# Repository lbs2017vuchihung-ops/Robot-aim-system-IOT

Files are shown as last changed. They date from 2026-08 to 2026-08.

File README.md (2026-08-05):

# Hệ Thống Phân Loại Màu Sắc Tự Động (IoT Robot Aim System)

> Một giải pháp tự động hóa toàn diện kết hợp phần cứng ESP32, vi điều khiển cơ khí 5 trục và nền tảng quản lý Web hiện đại (IoT).

Dự án được nghiên cứu và phát triển bởi nhóm hai sinh viên Đại học Bách Khoa TP.HCM. Hệ thống bao gồm một băng chuyền tự động và cánh tay robot 5 bậc tự do, có khả năng nhận diện, phân loại sản phẩm theo màu sắc và được giám sát theo thời gian thực qua giao diện Web Dashboard.

---
## Hình Ảnh Thực Tế Hệ Thống

<p align="center">
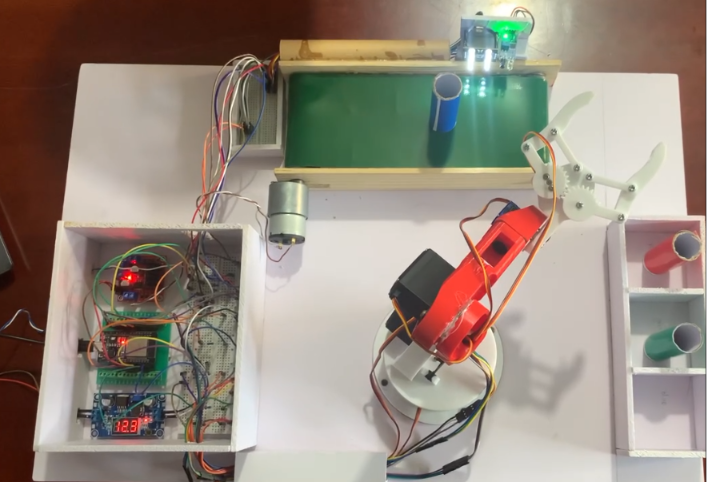
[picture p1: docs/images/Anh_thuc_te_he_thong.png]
Mô hình Robot Aim thực tế 1
  
</p>

---
## Tính Năng Nổi Bật

*   **Nhận Diện Chính Xác:** Sử dụng cảm biến màu TCS3200 với hộp che chống nhiễu sáng để thu thập thông số RGB của sản phẩm trên băng chuyền.
*   **Kết Cấu Cơ Khí Vững Chắc:** Băng tải sử dụng khung gỗ định hình dễ tháo lắp, dây đai PVC bám dính tốt và động cơ DC giảm tốc (12V) đảm bảo vận hành êm ái.
*   **Tay Máy Chịu Tải Cao:** Sử dụng 3 động cơ Servo MG996R (nhông kim loại, lực kéo 9-11 kg.cm) cho các khớp chịu lực (đế, vai, cùi chỏ) và 2 Servo SG90 siêu nhẹ cho tay kẹp để tối ưu trọng tâm.
*   **Hệ Thống Điện An Toàn:** Cấp nguồn 5V riêng biệt cho Servo qua mạch giảm áp LM2596. Tích hợp tụ điện chống tụt áp và điện trở giảm chấn bảo vệ chân tín hiệu của ESP32 khỏi tia lửa điện (Back EMF).
*   **Giao Diện Web Real-time:** Dashboard giám sát trực quan bằng Python, theo dõi tọa độ khớp gốc, số lượng sản phẩm màu và tình trạng đang chạy hay tắt của hệ thống.

---

## Sơ Đồ Đấu Dây (Pinout & Wiring)

### 1. Bảng Kết Nối ESP32 (Pin Mapping)
| Bảng chân (ESP32) | Thiết bị kết nối | Chức năng |
| :--- | :--- | :--- |
| **D5** | L298N (IN3) | Điều khiển Động cơ DC Băng tải |
| **D18** | L298N (IN4) | Điều khiển Động cơ DC Băng tải |
| **D13** | FC-51 | Cảm biến hồng ngoại nhận diện vật cuối băng tải |
| **D32, D14, D27, D26** | TCS3200 (S0, S1, S2, S3) | Cấu hình tần số cảm biến màu |
| **D25** | TCS3200 (OUT) | Tín hiệu xung màu sắc |
| **D4** | Servo MG996R (SV1) | Trục Đế (Xoay trái/phải) |
| **D19** | Servo MG996R (SV2) | Trục Vai (Nâng/hạ) |
| **D21** | Servo MG996R (SV3) | Trục Cùi chỏ (Vươn/rút) |
| **D22** | Servo SG90 (SV4) | Nâng hạ tay kẹp (Nâng/hạ) |
| **D23** | Servo SG90 (SV5) | Tay kẹp (Gripper) |

### 2. Nguyên Tắc Cấp Nguồn (Cực kỳ quan trọng)
*   **Tuyệt đối không** lấy nguồn 5V từ ESP32 để cấp cho Servo.
*   Nguồn 12V từ Adapter được chia làm 2 đường: 1 đường cấp cho L298N (kéo DC), 1 đường qua LM2596 hạ xuống đúng 5V để cấp cho Servo và ESP32.
*   Nối chung tất cả chân **GND** (Mass) của ESP32, LM2596, Servo và L298N để đồng bộ tín hiệu.
*   **Mạch bảo vệ:** Cắm tụ điện song song vào dải nguồn Servo và mắc điện trở nối tiếp trên các dây tín hiệu điều khiển.

### 3. Sơ đồ mạch trực quan

**Sơ đồ đấu nối hệ thống cảm biến & Servo:**
<p align="left">
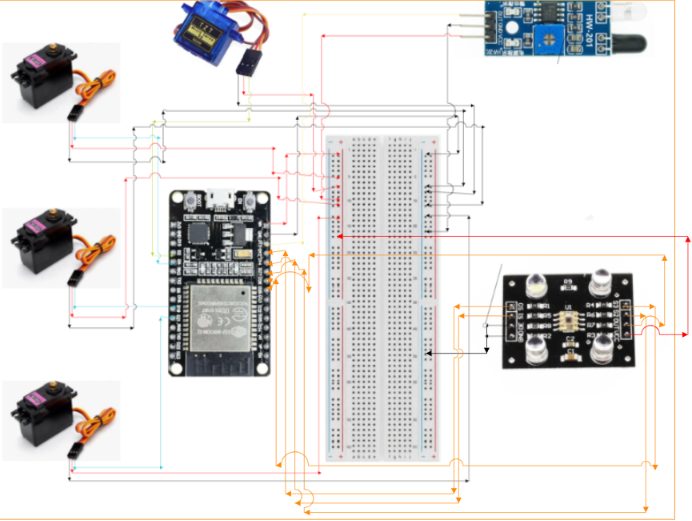
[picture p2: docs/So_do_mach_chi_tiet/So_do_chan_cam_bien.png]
Sơ đồ Cảm biến & Servo
  
</p>

**Sơ đồ đấu nối Động cơ DC & Hệ thống Nguồn:**
<p align="left">
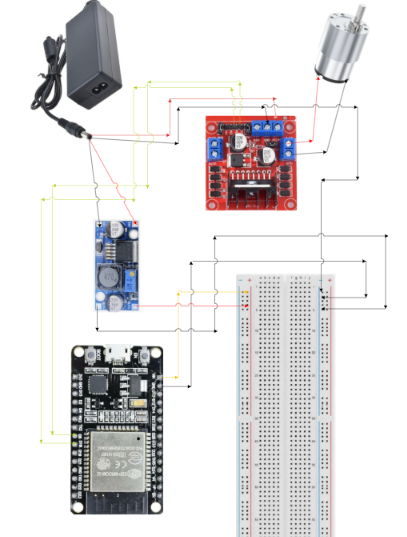
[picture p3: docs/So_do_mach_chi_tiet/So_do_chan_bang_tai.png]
Sơ đồ Băng tải & Nguồn
  
</p>

---

## Danh Sách Linh Kiện (BOM)

| STT | Tên Linh Kiện | Số Lượng |
| :--- | :--- | :--- |
| 1 | Vi điều khiển ESP32 NodeMCU 32S | 1 |
| 2 | Động cơ Servo MG996R (Nhông kim loại) | 3 |
| 3 | Động cơ Servo SG90 (Nhông nhựa) | 2 |
| 4 | Bộ băng tải mini (Khung gỗ định hình) | 1 |
| 5 | Động cơ DC giảm tốc 12V | 1 |
| 6 | Module điều khiển động cơ L298N | 1 |
| 7 | Cảm biến màu sắc TCS3200 | 1 |
| 8 | Cảm biến vật cản hồng ngoại FC-51 | 1 |
| 9 | Nguồn tổ ong / Adapter 12V-10A | 1 |
| 10 | Mạch giảm áp LM2596 (Step-down) | 1 |
| 11 | Điện trở, Tụ điện, Dây cắm Breadboard | Nhiều |

---

## Hướng Dẫn Cài Đặt & Khởi Chạy

### 1. Phần cứng (Firmware ESP32)
1. Tải và cài đặt Arduino IDE.
2. Mở file mã nguồn `.ino` trong thư mục `firmware`.
3. Cài đặt các thư viện cần thiết (ví dụ: `ESP32Servo`).
4. Kết nối board ESP32 với máy tính qua cáp Micro-USB và tiến hành Upload code.

### 2. Phần mềm (Web Dashboard)
Đảm bảo máy tính của bạn đã cài đặt Python. Hệ thống web sử dụng framework `NiceGUI` và `FastAPI` để render giao diện Real-time.

**Bước 1:** Di chuyển vào thư mục Web
```bash
cd web_app
```

**Bước 2:** Cài đặt các thư viện phụ thuộc
```bash
pip install -r requirements.txt
```

**Bước 3:** Khởi động máy chủ web
```bash
python RobotAim.py
```
*(Nếu muốn chạy ngầm máy chủ, hãy sử dụng lệnh pythonw RobotAim.py)*

**Bước 4:** Mở trình duyệt và truy cập vào địa chỉ `http://localhost:8080`.
Bạn có thể tự do bấm vào nút **Đăng ký** để tạo một tài khoản mới của riêng mình, hoặc sử dụng ngay tài khoản quản trị viên mặc định để trải nghiệm nhanh:
*   Username: `admin`
*   Password: `123456`

---
## Video Thuyết Trình & Hoạt Động

Dưới đây là các video thực tế ghi lại quá trình hoạt động của hệ thống mô hình:

* **Video Thuyết trình & Demo toàn bộ hệ thống:** [Bấm vào đây để xem](https://drive.google.com/file/d/19g9mdSmp5sloyk1nDQbA5UnhPswKEt9c/view?usp=sharing)

---

Dự án phát triển bởi: Vũ Chí Hưng & Đặng Hồng Anh - Đại học Bách Khoa TP.HCM

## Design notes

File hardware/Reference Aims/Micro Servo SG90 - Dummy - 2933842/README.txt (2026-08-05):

Micro Servo SG90 - Dummy by demetrius on Thingiverse: https://www.thingiverse.com/thing:2933842

Summary:
A simple micro servo dummy for help on your creation needs. One thing i had no idea about this servo (particularly the Tower Pro, not sure about others) is that its body is not perfectly square but is slightly tapered towards the top.

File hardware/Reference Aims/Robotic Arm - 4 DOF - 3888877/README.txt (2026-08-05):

Robotic Arm - 4 DOF by aled96 on Thingiverse: https://www.thingiverse.com/thing:3888877

Summary:
Robotic Arm - 4 DOF !Exclusive models and  contents only for you  on my PATREON page !!Visit now and support me at: https://www.patreon.com/aled96Support me if you like my work :)Motors used: SG90  https://www.amazon.it/gp/product/B01MXPTCHO/ref=ppx_yo_dt_b_asin_image_o02_s00?ie=UTF8&amp;psc=1Post ProcessingCreates the holes for the screws using a drill.Connect all together and make it works using an Arduino or another control board.

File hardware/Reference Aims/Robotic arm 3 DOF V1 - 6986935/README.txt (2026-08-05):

Robotic arm 3 DOF V1 by Vidimo_se on Thingiverse: https://www.thingiverse.com/thing:6986935

Summary:
The robot uses three 5V 28byj-48 stepper motors, one for each degree of freedom. The gripper is made for 20x20x20 XYZ calibration cubesThe SG90 is used for the two finger gripper. It's circuitry is removed so it's controlled as a DC motor, not a servo!I used the Arduino Pro Micro, though you can use other microcontrollers that have 14 or more digital I/O pins. Four are needed for each stepper motor if your using the ULN2003 drivers that come with the 28byj-48. The last two are for the DC motor on the end effector. I used the L293D driver IC, although it is a bit outdated. ~6 volt power source is required due to the voltage drop that occurs (1v on the ULN2003 and 1.5v-2.5v on the L293). I used a USB-C trigger (for fast charging) and a DC-DC step-down (buck) converter.Only one of each part needs to be printed.Non printed parts:28BYJ-48 stepper motor              x3SG90 modified to DC                       x1Main bearing - 6806                         x1Arm bearing - 693                             x2M3 nut                                                     x2M4 nut                                                    x2M4x6                                                       x6M3x12                                                     x6M3x8                                                       x5M3x25                                                    x2Screws                                                  x4Power supply                                      x1Breadboard                                         x1L293D motor driver                         x1Arduino microcontroller               x1ULN2003 driver board                   x3Edit 1: Posted pictures to help with assemblyEdit 2 (4.1.2025.):-Added a test print for tolerances with instructions (image)-Slight change to the "BASE"-Updated cover imageEdit 2 (15.3.2025.):-Added test code (Arduino IDE, requires AccelStepper library)-Added test code step-by-step explanation-Added pictures for the starting position the code uses Edit 3 (4.6.2025.):-Added "Beam 5 with counterweight", the counterweight helps with with the low torque of the stepper motorEdit 4 (9.8.2025.):-Fixed the test code to loop properlyEdit 5 (8.9.2025.):-Posted a video (.gif) of the test code, it's cut short due to file size limitations of the platform-Additional infoEdit 5 (9.9.2025.):-Fixed the "Base" model

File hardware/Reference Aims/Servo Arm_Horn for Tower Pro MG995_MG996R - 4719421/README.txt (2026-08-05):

Servo Arm/Horn for Tower Pro MG995/MG996R by Azxiana on Thingiverse: https://www.thingiverse.com/thing:4719421

Summary:
This is remixed to be close to the dimensions of the servo arm that ships with the authentic Tower Pro MG996R servos.  Unfortunately getting the authentic servos in my area is difficult so I am working with clones and need the correct servo arm for Alex Korvin's Walking UAZ robot.Print with 100% infill.  It only adds a few minutes and results in a much stronger part.I recommend using brim for bed adhesion since this is a small part.You might be able to get away without support for the screw recess.Print as shown with the flat side down.Blend file is included if you need to modify it outside of a STL format.

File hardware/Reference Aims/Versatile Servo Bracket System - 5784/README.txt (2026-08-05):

Versatile Servo Bracket System by bryanandaimee on Thingiverse: https://www.thingiverse.com/thing:5784

Summary:
This will hopefully be a versatile servo bracket system for robotics. I designed the holes to be spaced the same as the mounting holes on the servos and equidistant in both directions (square;)so brackets and/or servos should bolt together in many different configurations. The holes are a little closer to one of the long edges allowing a servo to be bolted on along that side directly. I don't know if that will ever be used, but I thought it might come in handy. It is sized for full size hobby servo motors. The files are in inches, so you may need to scale them in your system. They were created in google sketchup, so if you want other file formats I can only save to formats supported by sketchup. Pictures will follow soon. The servos I have are HS-322HD, so that is what I know it fits. Hopefully it will fit other full size servos. If you have a similar size servo that doesn't work with these brackets please let me know what changes are needed to make it more universal. I have a 2 DOF quad nearly finished using these brackets so pictures of that will be forthcoming as well. I'll soon be adding a connector to enable 3 DOF arms/legs. Update: Connectors added for 3 DOF limbs. Also I updated the brackets to be a little longer at the end. This will help prevent the ends splitting when screwing the bracket to the horn. The "Inside" brackets are a little narrower to be fitted inside the horn and the "outside" brackets are designed to attach outside the horn.Here is the 2DOF Quad http://www.thingiverse.com/thing:6321, and here http://www.youtube.com/watch?v=Z9ne67bbpSQ is a youtube video of the 2DOF walker in action. The controller is a Jaluino with a servo shield I designed myself.

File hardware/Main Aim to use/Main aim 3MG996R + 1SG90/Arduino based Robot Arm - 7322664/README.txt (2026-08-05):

Arduino based Robot Arm by FantaCitron on Thingiverse: https://www.thingiverse.com/thing:7322664

Summary:
An Arduino based simple 5 DOF robot arm controlled via a custom-built Android app. It utilizes three MG996R and two SG90 servo motors.https://howtomechatronics.com/tutorials/arduino/diy-arduino-robot-arm-with-smartphone-control

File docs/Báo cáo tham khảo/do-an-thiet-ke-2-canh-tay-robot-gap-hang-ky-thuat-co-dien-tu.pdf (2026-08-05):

DDDDDĐFFĐFDF44355 (https://www.studocu.vn/vn/document/truong-dai-hoc-thai-binh-duong/admistration/do-an-thiet-ke-2-canh-tay-robot-gap-hang-ky-thuat-co-dien-tu/162894056)

admistration (Trường Đại học Thái Bình Dương) (https://www.studocu.vn/vn/course/truong-dai-hoc-thai-binh-duong/admistration/5847769)

messages.pdf_cover_qr_code_label

messages.studocu_not_sponsored_or_endorsed_by_college messages.downloaded_by

lOMoARcPSD|60016464

TỔNG LIÊN ĐOÀN LAO ĐỘNG VIỆT NAM

TRƯỜNG ĐẠI HỌC TÔN ĐỨC THẮNG

KHOA ĐIỆN – ĐIỆN TỬ

TRẦN QUANG PHỔ

# THIẾT KẾ CÁNH TAY ROBOT GẮP HÀNG

## ĐỒ ÁN THIẾT KẾ 2

## KỸ THUẬT CƠ ĐIỆN TỬ

THÀNH PHỐ HỒ CHÍ MINH, NĂM 2025

TỔNG LIÊN ĐOÀN LAO ĐỘNG VIỆT NAM

TRƯỜNG ĐẠI HỌC TÔN ĐỨC THẮNG

KHOA ĐIỆN – ĐIỆN TỬ

TRẦN QUANG PHỔ

## THIẾT KẾ CÁNH TAY ROBOT GẮP HÀNG

## ĐỒ ÁN THIẾT KẾ 2

## KỸ THUẬT CƠ ĐIỆN TỬ

Người hướng dẫn

ThS.Thái Lâm Cường Quốc

THÀNH PHỐ HỒ CHÍ MINH, NĂM 2025

2

### LỜI CẢM ƠN

Đầu tiên cho em xin trân trọng gửi lời cảm ơn chân thành và sự kính trọng tới –

Các Thầy ngành Cơ điện tử Trường Đại học Tôn Đức Thắng, và đặc biệt là giảng viên

hướng dẫn thầy Thái Lâm Cường Quốc đã tận tình hướng dẫn chúng em trong suốt quá

trình thực hiện bài báo cáo này.

Do kiến thức của em còn hạn hẹp nên có thể sẽ mắc phải nhiều lỗi trong quá trình

em làm bài báo cáo. Em rất mong nhận được sự đóng góp ý kiến của quý thầy để bài báo

cáo đạt được kết quả tốt hơn.

Em xin chân thành cảm ơn!

TP. Hồ Chí Minh, ngày | tháng | năm 2025

Tác giả

3

4

MỤC LỤC

CHƯƠNG 1: TỔNG QUAN NGUYÊN LÝ HOẠT ĐỘNG CỦA TAY MÁY CÔNG

III

IV

DANH MỤC HÌNH VẼ

Hình 1-1. Cánh tay robot công nghiệp

Hình 1-2. Cánh tay robot kiểu khớp nối

Hình 1-3. Cánh tay robot SCARA

Hình 1-4. Cánh tay robot Cartesian

Hình 1-5. Cánh tay robot Delta

Hình 1-6. Cánh tay robot Polar

Hình 1-1. Cánh tay robot cộng tác

Hình 1-8. Quỷ đạo làm việc cánh tay robot

Hình 2-1. Các loại động cơ DC

Hình 2-2. Động cơ bước

Hình 2-3. Động cơ Servo

Hình 2-4. Động cơ AC

Hình 2-5. Driver A4988

Hình 2-6. Driver DRV8825

Hình 2-7. Driver TMC2208

Hình 2-8. Driver TB6600

Hình 2-9. ESP32

Hình 2-10. Arduino Uno R3

Hình 2-11. Arduino nano

Hình 2-12. Nguồn tổ ong

Hình 2-13. Nguồn adapter

Hình 2.14. Giác hút chân không L60-MP12

Hình 2-15. Động cơ bơm 12VDC

Hình 2-16. Ống silicon dẫn khí

Hình 2-17. Van xả 12VDC

V

Hình 3-0. Khioangr cách làm việc của cánh tay

Hình 3-1. Nắp đế động cơ 1

Hình 3-2. Đế khớp xoay động cơ 2 và 3

Hình 3-3. Đế khớp xoay động cơ 2 và 3 với giá đỡ công tắc hành trình

Hình 3-4. Khớp xoay bị động

Hình 3-5. cạnh khớp xoay bị động khi chạm vào công tắc hành trình

Hình 3-6. Cánh tay robot 4 bật tự do 2D

Hình 3-7. Động cơ bước NEMA17 −1,8 °−¿ 0,6 N.m

Hình 3-8. Động cơ bước NEMA17 −1,8 °−¿ 0,34 N.m

Hình 3-9. Góc quay arctan

Hình 3-10. Góc quay arctan 2

Hình 4-1. Đế khớp xoay và khâu 1

Hình 4-2. Đế khớp xoay và khâu 2

Hình 4-3. Đế khớp xoay và khâu 3

Hình 4-4. Khâu 4

Hình 4-5. Tay máy khi lắp ráp hoàn chỉnh và kiểm nghiệm bền

Hình 4-6. Sơ đồ điện của cánh tay robot

Hình 4-7. Lưu đồ giải thuật

Hình 5-1. Kết quả cánh tay và mạch trong quá trình nghiên cứu

VI

DANH MỤC BẢNG BIỂU

Bảng 2-1. Ưu và nhược điểm của từng loại động cơ

Bảng 2-2. Ưu và nhược điểm của từng loại Driver

Bảng 2-3. Ưu và nhược điểm của từng loại mạch vi điều khiển

Bảng 2-4. Các chí tiết phụ

Bảng 3-1. Các thông số kỹ thuật của vật liệu nhựa PETG

Bảng 3-2. Bảng số liệu khối lượng các khâu

Bảng 3-3. Các góc của tay máy

VII

DANH MỤC CÁC CHỮ VIẾT TẮT

CNC | Computer Numerical Control
DOF | Degrees of Freedom

VIII

ĐỒ ÁN THIÊT KẾ 2

Trang 1

CHƯƠNG 1: TỔNG QUAN NGUYÊN LÝ HOẠT ĐỘNG CỦA TAY MÁY

CÔNG NGHIỆP

### 1.1. Giới Thiệu đề Tài

### 1.1.1. Tổng quan về robot công nghiệp

- Cánh tay robot công nghiệp là một thiết bị cơ khí được thiết kế theo nguyên lý hoạt

động của tay người và có thể lập trình để thực hiện các chức năng cụ thể. Với thiết kế

tinh vi, chúng thường được sử dụng trong các dây chuyền sản xuất để đảm nhận nhiều

công việc khác nhau. Những cánh tay này nổi bật nhờ khả năng làm việc chính xác, hiệu

quả và đồng đều, giúp nâng cao năng suất và độ tin cậy trong quá trình sản xuất.

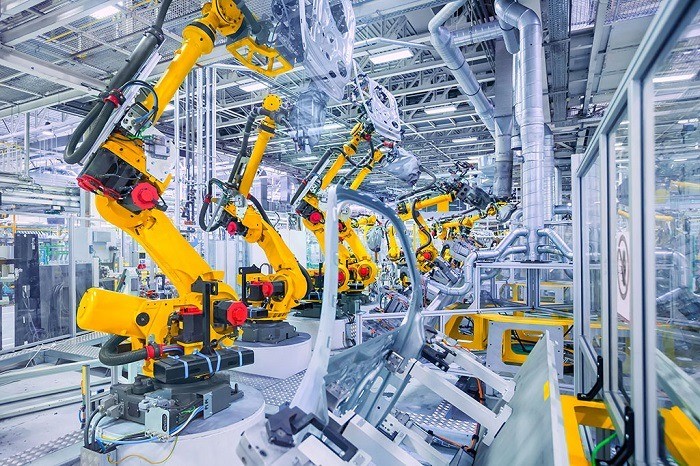
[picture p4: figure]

Thiết Kế Cánh Tay Robot Gắp Hàng (https://www.studocu.vn/vn)

Hình 1-2. Cánh tay robot công nghiệp

Trang 2

### 1.1.2. Các loại cánh tay công nghiệp phổ biến trong sắp xếp hàng hóa:

1. Cánh tay robot kiểu khớp nối (Articulated Robot Arm)
- Đặc điểm:

Có 3–6 bậc tự do (DOF), mỗi khớp nối thường dùng động cơ quay.

Giống cánh tay người.

Ví dụ: UR5, UR10 (Universal Robots), ABB IRB series, KUKA KR series.

- Ưu điểm:

Linh hoạt, hoạt động trong không gian 3D tốt

Có thể thực hiện nhiều thao tác phức tạp (lắp ráp, hàn, sơn...)

Có vùng làm việc lớn và dễ mở rộng

Thích hợp cho nhiều ứng dụng công nghiệp

- Nhược điểm:

+ Điều khiển và mô phỏng động học phức tạp

+ Giá thành cao

+ Khó bảo trì hơn các tay robot đơn giản

Hình 1-3. Cánh tay robot kiểu khớp nối

Trang 3

### 2. Cánh tay SCARA (Selective Compliance Articulated Robot Arm)

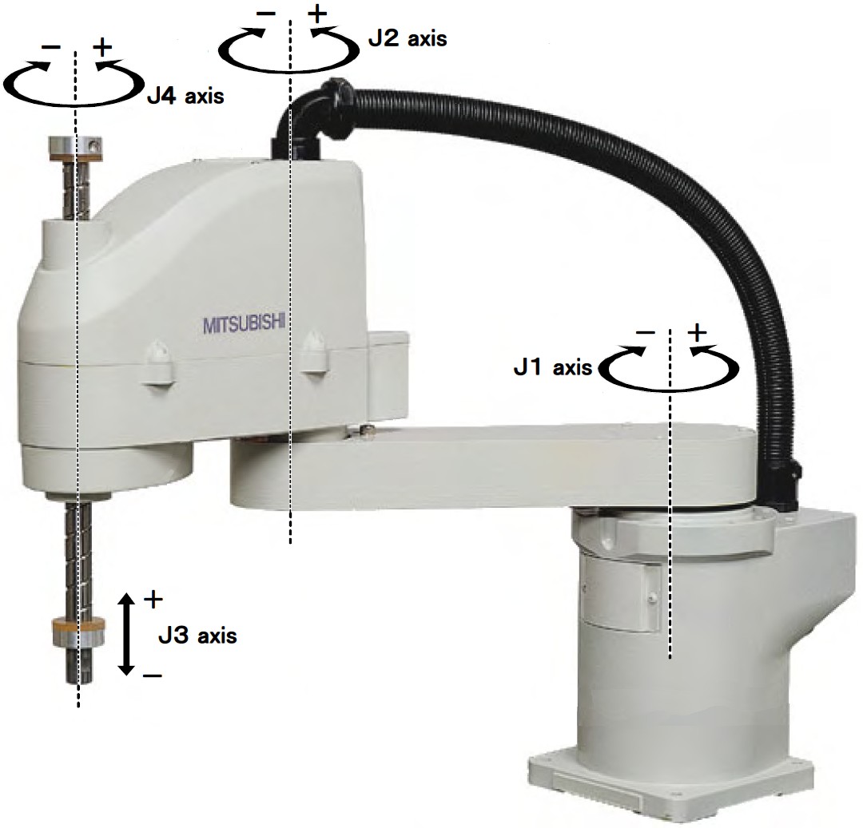
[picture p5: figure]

- Đặc điểm:

+ Chuyên dụng cho thao tác 2D trong mặt phẳng ngang, gồm 4 trục.

+ Phù hợp cho công việc pick-and-place, lắp ráp nhanh.

+ Ví dụ: Epson SCARA, Yamaha SCARA, Mitsubishi RH series.

- Ưu điểm:

+ Tốc độ rất nhanh

+ Độ chính xác cao

+ Thiết kế gọn gàng, dễ lắp đặt

- Nhược điểm:

Hình 1-4. Cánh tay robot SCARA

Trang 4

+ Chỉ làm việc trong mặt phẳng (ít linh hoạt hơn loại khớp nối)

+ Khó mở rộng phạm vi chuyển động không gian

### 3. Cánh tay Cartesian (Gantry Robot / XYZ robot)

- Đặc điểm:

+ Di chuyển dọc theo các trục X, Y, Z thẳng góc.

+ Hoạt động kiểu hệ tọa độ Descartes.

+ Ví dụ: Tay robot CNC, robot in 3D, pick-and-place công nghiệp.

- Ưu điểm:

+ Điều khiển đơn giản (chuyển động tuyến tính)

+ Độ chính xác cao

+ Tải trọng lớn

+ Dễ chế tạo, mở rộng

- Nhược điểm:

Hình 1-5. Cánh tay robot Cartesian

Trang 5

+ Không linh hoạt (chỉ chuyển động thẳng)

+ Chiếm nhiều không gian (khung lớn)

+ Không phù hợp với các công việc yêu cầu quay, cử động phức tạp

### 4. Cánh tay Delta (Parallel Robot)

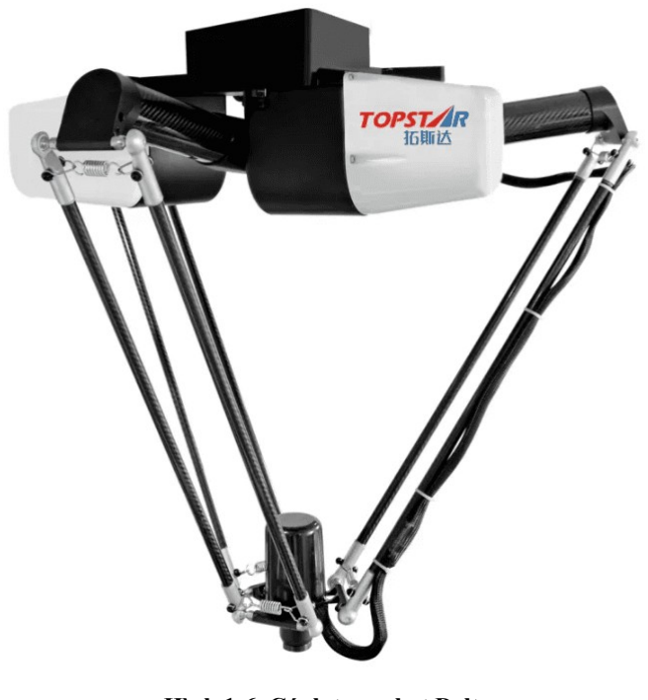
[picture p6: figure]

- Đặc điểm:

+ Gồm 3 hoặc 4 thanh tay song song liên kết với nhau

+ Di chuyển đầu công cụ rất nhanh và chính xác

+ Ví dụ: Tay robot pick-place tốc độ cao trong dây chuyền đóng gói.

- Ưu điểm:

+ Siêu nhanh (pick-and-place tốc độ cao)

+ Độ chính xác cao

+ Cấu trúc nhẹ

Hình 1-6. Cánh tay robot Delta

Trang 6

- Nhược điểm:

+ Không tải nặng được

+ Không linh hoạt trong không gian 3D

+ Điều khiển phức tạp do hệ song song

### 5. Cánh tay Polar / Spherical Robot

- Đặc điểm:

+ Tay robot có một khớp quay, một khớp gập, một khớp trượt

+ Vùng hoạt động dạng hình cầu

+ Ví dụ: Một số robot công nghiệp cũ trong sơn phủ, hàn.

Hình 1-7. Cánh tay robot Polar

Trang 7

- Ưu điểm:

+ Vùng làm việc hình cầu rộng

+ Cấu trúc đơn giản, tiết kiệm không gian

- Nhược điểm:

+ Độ chính xác không cao

+ Ít phổ biến hiện nay do hạn chế cơ học

### 6. Tay robot cộng tác (Collaborative Robot – Cobots)

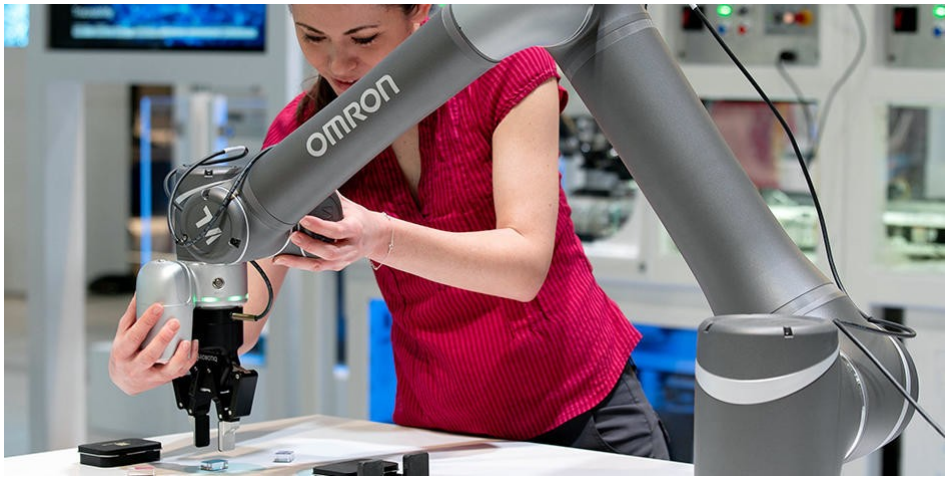
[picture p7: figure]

- Đặc điểm:

+ Có cảm biến, an toàn, làm việc cùng con người

+ Kiểu dáng thường là articulated hoặc SCARA

+ Ví dụ: UR series (Universal Robots), ABB YuMi, Doosan cobots.

- Ưu điểm:

+ An toàn khi làm việc cạnh người

+ Lập trình dễ (kéo thả, học lặp lại)

Hình 1-8. Cánh tay robot cộng tác

Trang 8

+ Linh hoạt, gọn nhẹ

- Nhược điểm:

+ Giá cao hơn so với công suất tương đương

+ Tốc độ/tải trọng thấp để đảm bảo an toàn

Vì yêu cầu đề tài là thiết kế cánh tay robot gắp hàng 4 bậc tự do nên em lựa chọn thiết kế

theo cánh tay kiểu khớp nối để có thể gắp hàng linh hoạt trong quỹ đạo của robot.

### 1.2. Mục đích nghiên cứu

- Với nhu cầu trong công nghiệp hiện nay có rất nhiều loại robot phục vụ cho từng mục

đích khác nhau nhưng vì đề tài của em hướng tới việc gắp hàng di chuyển từ vị trí A sang

B thì em đã lựa chọn thiết kế robot 4 bậc tự do, với mục tiêu xây dựng thành công mô

hình hoàn chỉnh, phục vụ cho nhu cầu nghiên cứu về lĩnh vực đang rất nổi trội trong thời

gian gần đây.

- Mục tiêu thiết kế cánh tay robot 4 bậc tự do để nhấc được vật ở khoảng cách tối đa của

cánh tay là 0,4 m nênd0=50mm; L1=¿ 250 mm; L2=300mm; L3=20mm

Hình 1-8. Quỷ đạo làm việc cánh tay robot

Trang 9

- Với phạm vi hoạt động này chắc chắn đáp ứng được các dự án cải tiến của em về sau

như thiết kế cánh tay robot đánh cờ tướng với AI, phân loại các khối hàng theo màu kết

hợp với băng tải,…

- Sử dụng giác hút chân không thay vì đầu gắp vì đề tài hướng tới là gắp hàng hóa nếu

thực tế sử dụng đầu gắp thì có khả năng gây hư hỏng thay vào đó sử dụng giác hút chân

không giúp tiết kiệm chi phí và khả năng di chuyển vật thể trong phạm vi hoạt động được

tốt nhất.

### 1.3. Đối tượng nghiên cứu

- Trong đồ án này, đối tượng nghiên cứu sẽ là một cánh tay robot ba bậc tự do với

khớp xoay thẳng đứng được gắn vào trục của một động cơ bước có driver. Khớp

xoay này sẽ được gắn vào trục của cánh tay đòn để giúp cánh tay đòn xoay đến vị

trí theo mong muốn của người lập trình.

- Vi điều khiển: ESP32
- Driver sử dụng để điều khiển động cơ bước là A4988 kết hợp với mạch ra chân

giúp cho việc lập trình và kết nối dây điện trở nên dễ dàng hơn

- Phần mềm điều khiển nạp code: Arduino IDE

### 1.4. Kết quả cần đạt được

- Do còn hạn chế về tài chính và kiến thức nên hiện tại chỉ có thể hoàn thiện được

một mô hình một bậc tự do có khả năng xoay lên xuống trong phạm vi góc từ 0°

đến 180° có thể được tùy chỉnh trong code tùy theo nhu cầu của người sử dụng.

- Cánh tay được điều khiển bởi phần cứng là một mạch Arduino ESP 32 kết nối với

một driver điều khiển động cơ bước là A4988.

- Đây là một hệ thống cơ cấu cánh tay máy đơn giản, gọn nhẹ và có thể chịu tải nhỏ

từ 300 g – 500 g tùy công suất động cơ mà người dùng lựa chọn.

- Sau khi thực hiện xong đồ án này, chúng ta có thể học được cách ứng dụng các

kiến thức về vi điều khiển, thiết kế 3D và lập trình một cách hiệu quả và cho ra

thành quả là một sản phẩm hoàn thiện ở một mức độ cơ bản, không quá chính xác.

Trang 10

- Ngoài ra, đồ án này là một nền móng quan trọng cho việc phát triển lên những sản

phẩm nâng cao hơn, yêu cầu sự chính xác như cánh tay robot 4 bậc, 5 bậc hay

thậm chí là 6 bậc tự do tùy theo nhu cầu trong tương lai.

### CHƯƠNG 2: LỰA CHỌN PHƯƠNG ÁN THIẾT KẾ

### 2.1. Tổng quan về các loại động cơ thông dụng:

- Hiện nay các dự án về cánh tay robot sử dụng rất nhiều các loại động cơ như:
- Động cơ DC (DC Motor) là một loại động cơ điện chạy bằng dòng điện một chiều (DC

– Direct Current). Nó hoạt động dựa trên nguyên lý lực từ tác động lên dây dẫn mang

dòng điện đặt trong từ trường, từ đó tạo ra chuyển động quay.

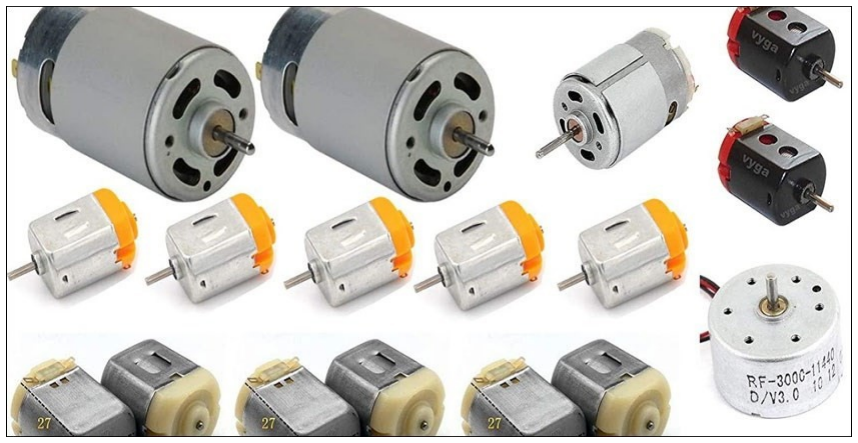
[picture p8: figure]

- Động cơ bước (Stepper Motor) là một loại động cơ điện quay từng bước góc xác định

thay vì quay liên tục như động cơ DC. Mỗi khi được cấp xung điện, rotor của nó sẽ quay

một góc nhất định (gọi là bước), giúp điều khiển vị trí chính xác mà không cần encoder.

Hình 2-1. Các loại động cơ DC

Trang 11

- Động cơ servo (Servo Motor) là một loại động cơ có khả năng điều khiển chính xác vị

trí, tốc độ và mô-men xoắn nhờ vào hệ thống phản hồi (feedback). Khác với động cơ DC

hoặc động cơ bước thông thường, servo motor luôn biết được nó đang ở đâu và phải di

chuyển như thế nào.

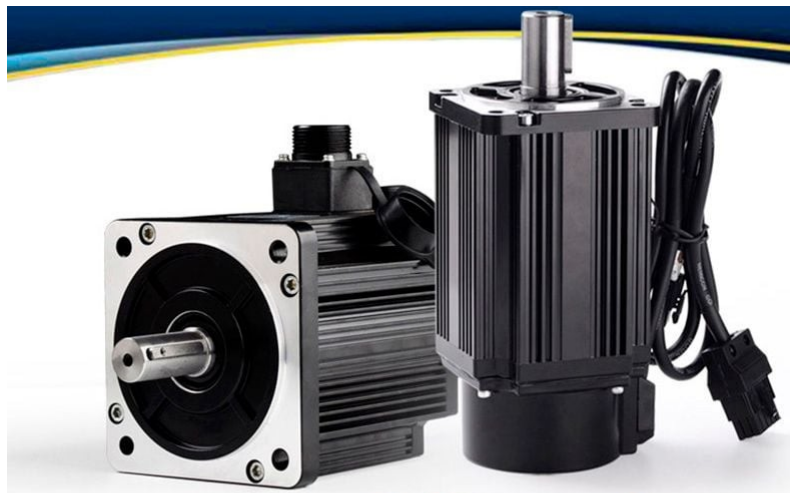
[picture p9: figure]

Hình 2-3. Động cơ Servo

Hình 2-2. Động cơ bước

Trang 12

- Động cơ AC (Alternating Current Motor) là loại động cơ điện sử dụng dòng điện xoay

chiều (AC) để tạo ra chuyển động quay. Đây là loại động cơ phổ biến nhất trong công

nghiệp và dân dụng nhờ vào cấu tạo đơn giản, độ bền cao và hiệu suất tốt.

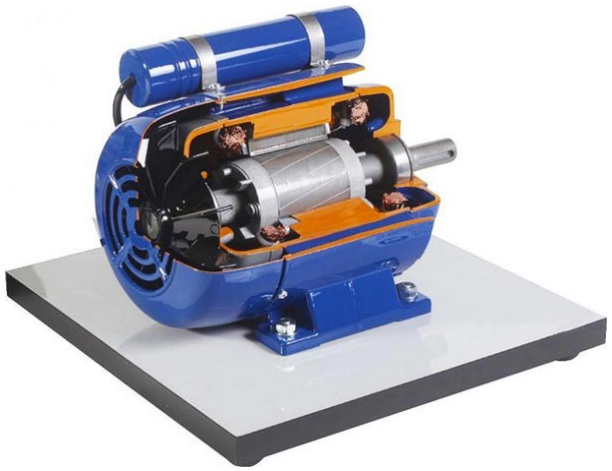
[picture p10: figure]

- Phân tích các ưu điểm và nhược điểm của từng động cơ:

Bảng 2-1. Ưu và nhược điểm của từng loại động cơ

Các loại động cơ | Ưu điểm | Nhược điểm | Ứng dụng
Động cơ DC | Điều khiển tốc độ đơn giản (bằng PWM). Khởi động nhanh, phản hồi tốt. Giá rẻ, phổ biến. | Chổi than nhanh mòn (với loại có chổi than). Gây nhiễu điện từ. Cần bảo trì định kỳ. | Xe robot mini, quạt, băng tải, máy bơm mini, đồ chơi…
Động cơ bước | Điều khiển vị trí chính xác mà không cần encoder. Cấu trúc đơn giản, giá thành rẻ. | Hiệu suất thấp, dễ bị mất bước nếu quá tải. Rung và ồn ở tốc độ cao | Máy in 3D, máy CNC mini, robot cánh tay đơn giản, máy khắc laser.

Hình 2-4. Động cơ AC

Trang 13

| Dễ tích hợp với mạch điều khiển (Arduino, CNC). Được sử dụng nhiều trong cánh tay robot
Động cơ Servo | Độ chính xác và mượt rất cao, không bị mất bước. Có thể kiểm soát vị trí, tốc độ, lực mô-men xoắn | Giá cao hơn nhiều so với stepper/DC. Điều khiển phức tạp hơn (cần driver chuyên dụng). Kích thước và trọng lượng đôi khi lớn | máy CNC chính xác cao, băng chuyền thông minh, camera gimbal, servo RC (loại nhỏ)
Động cơ AC | Bền, tin cậy, dễ bảo trì. Hoạt động ổn định trong công nghiệp | Cần biến tần (VFD) nếu muốn điều khiển tốc độ chính xác. Phản hồi chậm hơn so với servo. Kích thước lớn nếu công suất cao | Máy bơm, quạt công nghiệp, băng tải, hệ thống HVAC, máy nén khí.
- Kết luận: chọn động cơ bước làm động cơ chính trong các khâu của cánh tay robot vì

có những ưu và nhược điểm hợp với đồ án thiết kế 2 và có thể phát triển thêm cho các cải

tiến về sau.

### 2.2. Tổng quan về các loại Driver:

- Driver A4988 là một driver điều khiển động cơ bước (stepper motor driver) rất phổ

biến, do hãng Allegro Microsystems sản xuất. Nó được thiết kế để điều khiển các động

cơ bước lưỡng cực (bipolar stepper motors) thông qua tín hiệu số từ vi điều khiển (như

Arduino, ESP32, STM32...).

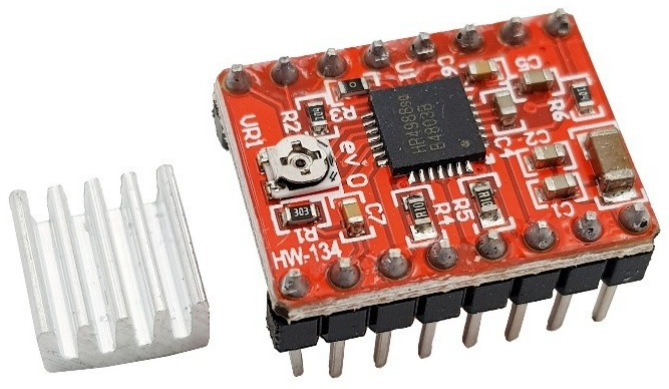
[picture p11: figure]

Hình 2-5. Driver A4988

Trang 14

- Driver DRV8825 là một driver điều khiển động cơ bước (stepper motor driver) được

sản xuất bởi Texas Instruments, thường được dùng như một bản nâng cấp của A4988. Nó

có khả năng điều khiển các động cơ bước lưỡng cực (bipolar stepper) với dòng cao hơn,

độ phân giải vi bước cao hơn, và hoạt động ổn định hơn.

- Driver TMC2208 là một driver điều khiển động cơ bước siêu êm và chính xác, do hãng

Trinamic (Đức) sản xuất. Nó nổi tiếng nhờ khả năng giảm tiếng ồn, vi bước mịn và điều

khiển dòng thông minh. Đây là bản nâng cấp cao cấp hơn so với A4988 hoặc DRV8825.-

Trang 15

Driver TB6600 là một loại driver điều khiển động cơ bước công suất cao, thường dùng để

điều khiển các động cơ bước lưỡng cực (bipolar) với dòng lớn, mô-men cao, rất phổ biến

trong máy CNC, máy cắt plasma, máy khắc laser, v.v.

- Phân tích các ưu nhược điểm của từng loại driver:

Bảng 2-2. Ưu và nhược điểm của từng loại Driver

Các loại Driver | Ưu điểm | Nhược điểm | Ứng dụng
A4988 | Rẻ, dễ tìm, nhỏ gọn. Hỗ trợ microstepping lên đến 1/16 bước. Có tính năng bảo vệ quá nhiệt, quá dòng. Dễ điều khiển bằng tín hiệu STEP/DIR (hợp với Arduino, STM32). | Dòng tối đa chỉ khoảng 1A – 2A, không phù hợp động cơ lớn. Không mượt ở tốc độ cao. Không có cách ly (isolation) tín hiệu điều khiển – dễ nhiễu. Không hỗ trợ điện áp cao (tối đa 35V). | Máy in 3D nhỏ, CNC mini, Cánh tay robot cỡ nhỏ..
DRV8825 (Texas Instruments) | Dòng tối đa cao hơn A4988 (khoảng 2.2A). Độ phân giải microstepping lên tới 1/32 bước → di chuyển mượt hơn. | Vẫn không đủ cho động cơ công suất lớn. Cần tản nhiệt tốt nếu chạy dòng cao. Gây nhiễu nếu không lọc nguồn tốt. | Máy in 3D, DIY CNC
TB6600 (Toshiba) | Tùy chỉnh được dòng điện, chế độ microstepping. Cách ly quang tín hiệu điều khiển → chống nhiễu tốt. | Kích thước lớn, không phù hợp không gian nhỏ. Giá cao hơn A4988, DRV8825. Tốc độ điều khiển không quá cao. | CNC bán chuyên, máy khắc laser
TMC2208 | Sử dụng công nghệ StealthChop2 giúp động cơ gần như không có tiếng ồn, phù hợp máy in 3D, robot chạy trong nhà. | Dòng tối đa ~1.4–1.5A ổn định, không đủ nếu dùng động cơ công nghiệp lớn. Đắt hơn A4988 hay DRV8825, tuy | Máy in 3D để in êm hơn, cánh tay robot giúp vận hành ổn định và ít rung lắc, …

Trang 16

Điều khiển cực kỳ mượt, chính xác

hơn hầu hết driver khác (A4988 chỉ

1/16, DRV8825 là 1/32).

nhiên xứng đáng với hiệu năng.

- Kết luận: em quyết định chọn Driver A4988, bởi vì nhìn vào ưu điểm thì driver có hiệu

năng tốt nhất trong các loại driver nêu trên và có thể ứng dụng được cho các cải tiến về

sau của đồ án.

### 2.3. Tổng quan về các loại mạch điều khiển

- ESP32 là một vi điều khiển tích hợp Wi-Fi và Bluetooth, được phát triển bởi công ty

Espressif Systems (Trung Quốc). Đây là một dòng chip mạnh mẽ, giá rẻ, rất phổ biến

trong các ứng dụng Internet of Things (IoT), tự động hóa, robot, thiết bị thông minh, và

nhiều dự án lập trình nhúng khác.

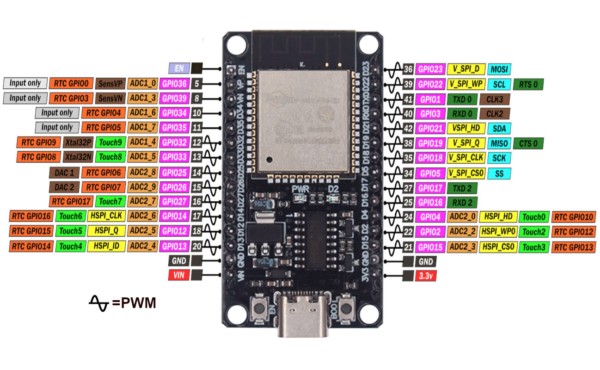
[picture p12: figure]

Hình 2-9. ESP32

Trang 17

- Arduino Uno R3 là một trong những bo mạch vi điều khiển phổ biến nhất của dòng

Arduino, rất phù hợp cho người mới học lập trình nhúng, các dự án DIY, robot, đo đạc

cảm biến, v.v. Nó được thiết kế để dễ dùng, lập trình bằng ngôn ngữ Arduino (dựa trên

C/C++), và kết nối với máy tính qua USB.

- Arduino nano là một bo mạch vi điều khiển nhỏ gọn, có cùng vi xử lý với Arduino Uno

(ATmega328P), nhưng kích thước nhỏ hơn rất nhiều, cực kỳ lý tưởng cho các dự án

nhúng, thiết bị wearable, robot mini, và không gian hạn chế.

Hình 2-10. Arduino Uno R3

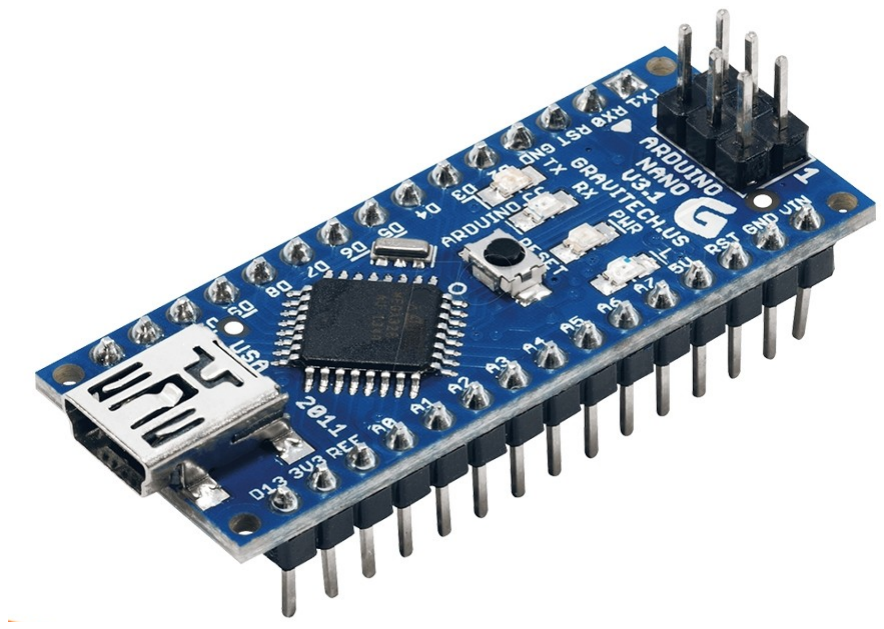
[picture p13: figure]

Hình 2.11 Arduino nano

Trang 18

- Phân tích ưu và nhược điểm của từng loại mạch vi điều khiển

Bảng 2-3. Ưu và nhược điểm của từng loại mạch

Tiêu chí | ESP32 | Arduino Uno R3 | Arduino Nano
Vi điều khiển chính | ESP32 (Xtensa 32-bit dual-core) | ATmega328P | ATmega328P
Xung nhịp (Clock) | 240 MHz | 16 MHz | 16 MHz
Bộ nhớ Flash | 4MB – 16MB | 32 KB | 32 KB
SRAM | ~520 KB | 2 KB | 2 KB
Số chân digital I/O | 30–38 chân | 14 (6 PWM) | 14 (6 PWM)
Số chân analog input | ~18 (tùy board) | 6 | 8
Chân analog output (DAC) | 2 DAC 8-bit | Không | Không
PWM output | Tùy chân (tối đa ~16) | 6 | 6
UART (Serial) | 3 (hoặc hơn) | 1 | 1
I2C | Có (2 hoặc nhiều hơn) | 1 | 1
SPI | Có (2 hoặc hơn) | 1 | 1
Wi-Fi | Tích hợp sẵn | Không | Không
Bluetooth | BLE + Classic | Không | Không
Logic level | 3.3V | 5V | 5V
Nguồn qua USB | 5V (microUSB hoặc USB-C) | 5V (USB-B) | 5V (mini-USB)
Kích thước | Nhỏ gọn | Trung bình | Rất nhỏ gọn
Giá (tham khảo) | 80k – 150k VND | 80k – 120k VND | 60k – 100k VND

Trang 19

Kết luận: Chọn ESP32 vì có những ưu điểm vượt trội hơn so với 2 mạch vi điều khiển

còn lại và đồng thời cũng phù hợp để cải tiến cánh tay robot trong tương lai.

### 2.4. Tổng quan về các loại nguồn

- Nguồn tổ ong (tiếng Anh: switching power supply with ventilation holes, hoặc thường

gọi là spider power supply / SMPS) là loại bộ nguồn chuyển mạch (Switching Mode

Power Supply - SMPS) được thiết kế với vỏ kim loại có nhiều lỗ thoáng khí giống như tổ

ong — giúp tản nhiệt hiệu quả.

- Nguồn adapter (còn gọi là adapter đổi nguồn, bộ đổi nguồn, hay adapter AC-DC) là

thiết bị chuyển đổi điện áp xoay chiều (AC) từ ổ cắm điện (thường 220V) thành điện áp

một chiều (DC) với mức thấp hơn (thường là 5V, 9V, 12V...), để cấp nguồn cho các thiết

bị điện tử như: laptop, camera, router, Arduino, ESP32, đèn LED, v.v.

Hình 2-12: Nguồn tổ ong

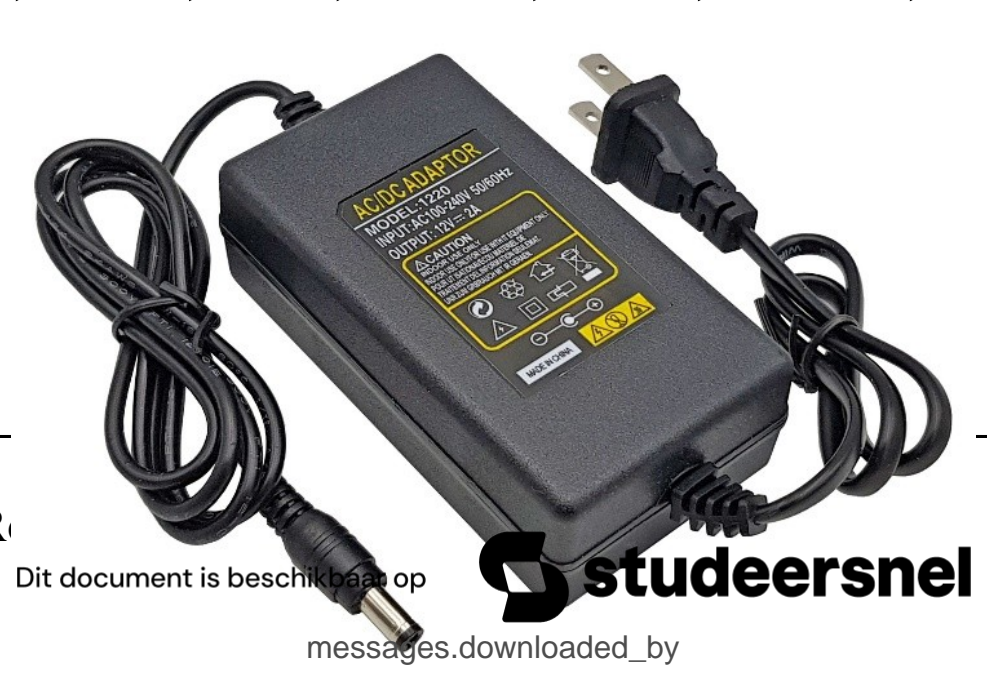
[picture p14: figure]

Trang 20

- Phân tích ưu và nhược điểm của 2 loại nguồn:
Tiêu chí | Nguồn tổ ong | Nguồn adapter
Cách đấu nối | Đấu dây thủ công qua terminal | Cắm trực tiếp qua jack (5.5mm, USB...)
Điện áp đầu vào | 220V AC trực tiếp | 220V AC (qua dây nguồn + jack tích hợp)
Điện áp đầu ra | 5V / 12V / 24V / 48V DC (ổn định) | 5V / 9V / 12V / 24V DC (có giới hạn dòng)
Dòng tối đa | Cao (3A – 40A tùy loại) | Thấp hơn (thường 0.5A – 5A)
Công suất | 50W – 1000W | 5W – 100W
Tản nhiệt | Tốt (vỏ tổ ong, đôi khi có quạt) | Kém hơn, dễ nóng nếu tải nặng
Tính ổn định | Rất ổn định, chịu tải cao | Có thể tụt áp nếu tải lớn đột ngột
Tính di động | Cồng kềnh, cố định | Nhỏ gọn, tiện mang theo
Độ an toàn (vỏ cách ly) | Cần che chắn khi dùng hở điện áp cao | Có vỏ bọc, an toàn với người dùng
Điều chỉnh điện áp | Có chiết áp chỉnh ±10% | Không chỉnh được điện áp
Giá bán | Rẻ / Trung bình | Rẻ / Trung bình
Ứng dụng phù hợp | Máy CNC, cánh tay robot, LED công nghiệp | Camera, mạch Arduino nhỏ, đồ gia dụng DIY
- Kết luận: Chọn nguồn tổ ong vì đồ án cần cấp nguồn cho nhiều thiết bị ngoại vi như

động cơ, driver, mạch điều khiển, sensor nên cần công suất lớn và sử dụng nguồn tổ ong

12V – 15A sẽ đáp ứng đủ các thiết bị cần cho đồ án.

Trang 21

2.5. Chọn động cơ bơm, van xả và giác hút cho tay gắp.

Sử dụng giác hút chân không L60 – MP12 .Ứng dụng nguyên lý gắp hút hình bình hành

để có thể hút và nhả vật, tiếp xúc tốt hơn với vật. Với việc sử dụng giác hút thì độ chính

xác và tiếp xúc với vật nhanh hơn.

- Ưu điểm :

+ Hoạt động chính xác.

+ Chi phí sản xuất thấp.

+ Kết cấu đơn giản.

+ Hệ thống điều khiển đơn giản.

- Nhược điểm:

+ Không hút được các vật có bề mặt tròn hoặc hình cầu

Hình 2-14: Giác hút chân không L60-MP12

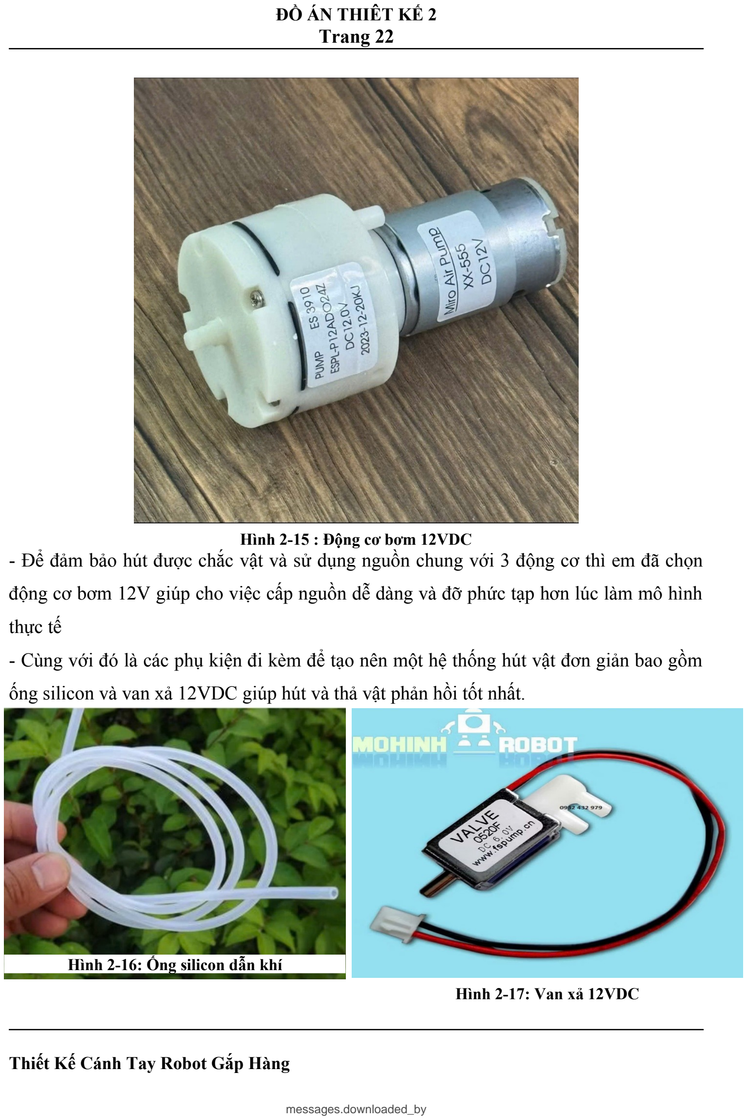
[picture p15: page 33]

Trang 22

- Để đảm bảo hút được chắc vật và sử dụng nguồn chung với 3 động cơ thì em đã chọn

động cơ bơm 12V giúp cho việc cấp nguồn dễ dàng và đỡ phức tạp hơn lúc làm mô hình

thực tế

- Cùng với đó là các phụ kiện đi kèm để tạo nên một hệ thống hút vật đơn giản bao gồm

ống silicon và van xả 12VDC giúp hút và thả vật phản hồi tốt nhất.

Hình 2-15 : Động cơ bơm 12VDC

Hình 2-16: Ống silicon dẫn khí

Hình 2-17: Van xả 12VDC

Trang 23

### 2.6. Danh sách các chi tiết phụ

Bảng 2-4. Các chí tiết phụ

STT | Tên chi tiết | Kích thước | Số lượng
1 | Bạc đạn F624 | | 10
2 | Bạc đạn F686 | | 12
3 | Vòng bi chặn F51105 | | 1
4 | Pulley GT2 | 20 răng | 3
5 | Dây đai GT2 | dày 6 mm - dài 200 mm | 3
6 | Bu lông M2 | 12 mm | 6 (đai ốc)
7 | Bu lông M3 | 6 mm | 8
| | 12 mm | 4
8 | Bu lông M4 | 10 mm | 6
| | 16 mm | 15 (đai ốc)
| | 20 mm | 4 (đai ốc)
9 | Bu lông M6 | 20 mm | 1 (đai ốc)
| | 40 mm | 1 (đai ốc)
| | 50 mm | 1 (đai ốc)
| | 60 mm | 1 (đai ốc)

TỔNG KẾT CÁC PHƯƠNG ÁN ĐÃ LỰA CHỌN

STT | 1 | 2 | 3 | 4 | 5 | 6 | 7 | 8
Tên linh kiện | Động cơ bước | Driver A4988 | Mạch ESP32 | Giác hút chân không L60-MP12 | Nguồn tổ ong 12V – 15A | Động cơ bơm 12 VDC | Van xả khí 12 VDC | Ống silicon dẫn khí

CHƯƠNG 3: TÍNH TOÁN ĐỘNG HỌC VÀ

KIỂM NGHIỆM BỀN

### 3.1. Lập bảng D-H cho cánh tay robot:

- Đặt các hệ tọa độ ta có được hình vẽ bên:

Trang 24

- Xác định bảng D-H:

Hàng 1:

# + Z0⊥Z1→a=0;α=90°

+ X0

# ∥ X1→d=50;θ=θ0

Hàng 2:

+ Z1

# ∥Z2→a=165 ;α=0°

+ X1 cùng mặt phẳng với X2→d=0 ;θ=θ1

Hàng 3:

+ Z2

# ∥Z3→a=200 ;α=0 °

+ X2 cùng mặt phẳng với X3→d=0 ;θ=θ2

Hàng 4:

+ Z3

# ∥Z4→a=50 ;α=0 °

+ X3 cùng mặt phẳng với X4→d=0;θ=θ3

- Xác định các góc θ0

;θ1

;θ2

;θ3 bằng phương pháp

động học thuận theo kiểu cổ điển (Classic DH parameter):

T=1T ×

0
2T ×

1
3T ×

2
4T

3
4
0 | T=

[

# Cθi −Cαi

# Sθi

# S αi

# S θi

# aiC θi

Sθi | CαiCθi | −S αiCθi

ai

| | | Sθi
0 | S αi | C αi | di
0 | 0 | 0 | 1 ] i

i−1

- Với {

# Cθ0=cos(θ0 ) ;Cθ1=cos(θ1) ;Cθ2=cos(θ2 );Cθ 3=cos(θ3) S θ0=sin (θ0 ) ; S θ1=sin (θ1 ); S θ2=sin (θ2) ;Sθ 1=sin (θ2)

- Sử dụng phần mềm Matlab để tính toán chính xác nhất
- Đặt biến bằng lệnh syms với a = a; α = a1; d = d; θ = th của ma trận iT i−1
:

Bảng 3-3. Các góc của tay máy

STT | a | α | d | θ
1 | 0 | 90 ° | d0 | θ0
2 | L1 | 0 ° | 0 | θ1
3 | L2 | 0 ° | 0 | θ2
4 | L3 | 0 ° | 0 | θ3

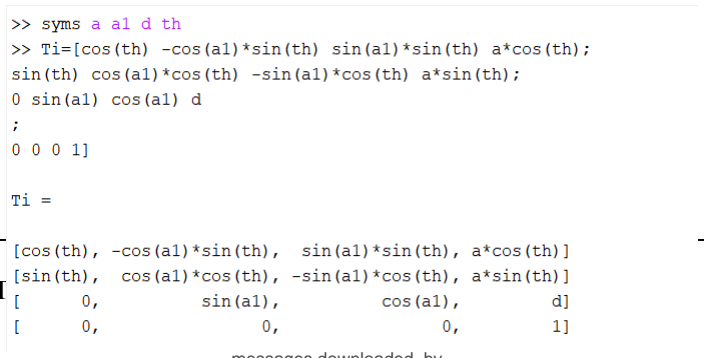
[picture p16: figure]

Trang 25

- Nhập giá trị của ma trận 1T

0
:

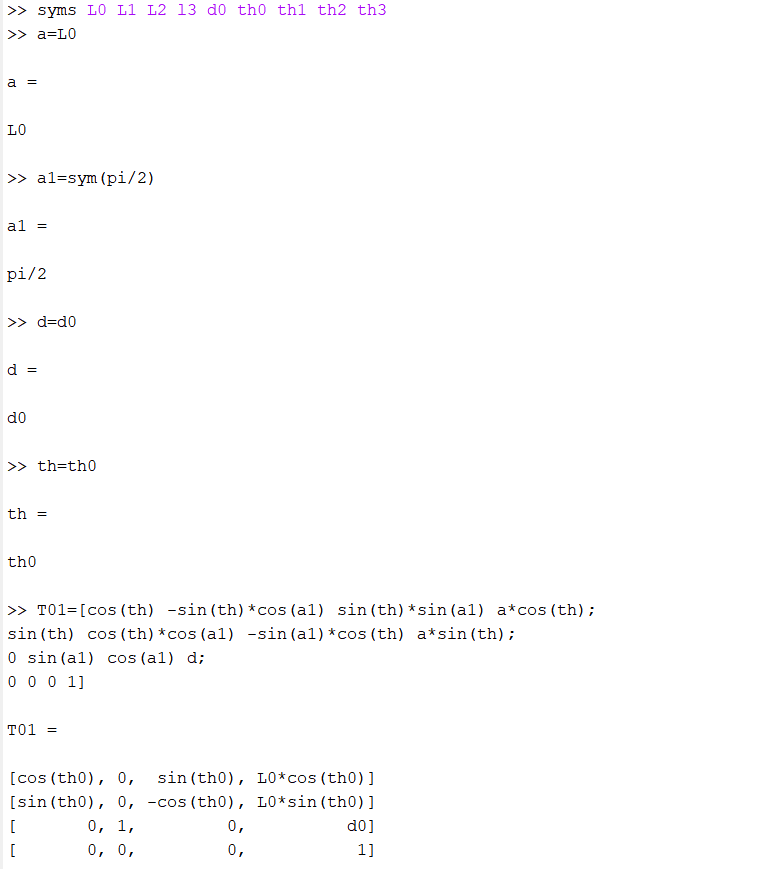
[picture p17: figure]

Trang 26

- Nhập giá trị của ma trận 2T

1
:
- Nhập giá trị của ma trận 3T

2
:

Trang 27

- Nhập giá tị của ma trận 4T

3
:

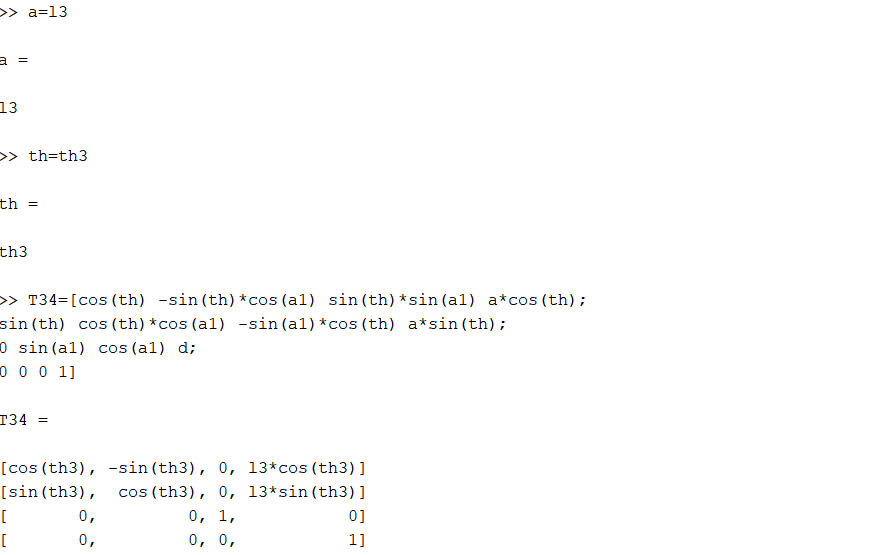
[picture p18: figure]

Từ đó ta có được các ma trận sau:

T=

[
C θ0

# 0 Sθ0 L0∗Cθ0

S θ0

0 −Cθ 0 | L0∗S θ 0
0 1 | 0 | d0
0 0 | 0 | 1 ] 1

0

; T=

[

# Cθ1 −S θ1

# 0 L1∗Cθ1

S θ1 | Cθ1 | 0 L1∗S θ1
0 | 0 | 1 | 0
0 | 0 | 0 | 1 ] 2

1

;

T=

[

# Cθ2 −S θ2 0 L2∗Cθ2

S θ 2 | Cθ2 | 0 L2∗Sθ2
0 | 0 | 1 | 0
0 | 0 | 0 | 1 ] 3

2

; T=

[

# Cθ3 −S θ3 0 L3∗Cθ3

S θ3 | Cθ 3 | 0 L3∗S θ3
0 | 0 | 1 | 0
0 | 0 | 0 | 1 ] 4

3

Tiếp tục tính toán ma trận T=1T ×

0
2T ×

1
3T ×

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
r11 r12 r13 | px
r21 r22 r23 | p y
r31 r32 r33 | pz

0 0 0 1 ] 4

0

Tính toán và rút gọn từ Matlab ta có được:

Trang 28
{

# px=cos(θ0

# )∗(L0⁺L2∗cos(θ1⁺θ 2

# )+L1∗cos(θ1

# )+ L3∗cos(θ1⁺θ2⁺θ3

))

# p y=sin(θ 0

# )∗(L0⁺L2∗cos(θ1⁺θ2

# )+L1∗cos(θ1

# )+L3∗cos(θ1⁺θ2⁺θ3

))

# pz=d0⁺L2∗sin(θ1⁺θ2

# )+L1∗sin(θ1

# )+ L3∗sin(θ1⁺θ2⁺θ3

)

(3.1.1)

Sử dụng phương pháp động học nghịch để tìm ra biểu thức cho các góc tại các khớp:
T=1T ×

0
2T ×

1
3T ×

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
T=2T ×

1
3T ×

2
4T

3
4

0

Dùng hàm inv để nghịch đảo ma trận 1T

0
:

Vì dữ liệu tính toán rất phức tạp nên em đặt :

T

−1
1 ×

0
T=

[
¿ | ¿ | ¿ | n1
¿ | ¿ | ¿ | n2
¿ | ¿ | ¿ | n3

0 0 0 1 ] 4

0

và 2T ×

1
3T ×

2
4T

3 =

[
¿ | ¿ | ¿ | m1
¿ | ¿ | ¿ | m2
¿ | ¿ | ¿ | m3

0 0 0 1 ]

Từ đó ta tính được:
{

# n1=px∗cos(θ0)−L0⁺ p y∗sin(θ 0

)

# n2=pz⁻d0 n3=px∗sin(θ0

# )−p y∗cos(θ0

)

(3.1.2)

và
{

# m1=L3∗cos(θ1⁺θ2⁺θ3

# )+L2∗cos(θ1⁺θ2

# )+L1∗cos(θ1

)

# m2=L3∗sin(θ1⁺θ 2⁺θ 3

# )+L2∗sin (θ1⁺θ2

# )+L1∗sin(θ 1

)
m3=0

(3.1.3)

Tính góc θ0:

# Mà n3=m3=¿ px∗sin (θ0 )−p y

# ∗cos( θ0 )=0

Trang 29

# sin (θ0 ) cos(θ0)

=

py
px

# =¿ tan( θ0 )=

py
px

# =¿ θ0=arctan 2( py

, px
) | (3.1.4)

Vì sao sử dụng arctan2 mà không sử dụng arctan như thông thường?

Arctan luôn đóng vai trò trong việc tính toán góc trong tam giác vuông nhưng sau đây sẽ

là chứng minh arctan đang gặp vấn đề trong vòng tròn lượng giác

# α=arctan (

y
x ) khi có điều kiện x > 0 thì mới tính được góc

Nhưng nếu x < 0 sẽ sinh ra 2 trường hợp như hình bên:

# góc α1=arctan (

y

# −x )=arctan (

−y
x )=α2

=> không xác định được chính xác khi góc nằm trong vùng II và IV

Giải pháp là sử dụng hàm arctan2 (y,x) vì có nhiều trường hợp

nên việc xác định các góc quay của cánh tay robot trở

nên chính xác hơn

# Arctan2 (y,x) = {

# arctan (

y
x )

# if x>0

# artan(

y
x )

# +π if x<0 ; y≥ 0

# artan(

y

# x )⁻π if x<0 ; y<0

π
2

# if x=0 ; y>0

−π
2

# if x=0; y<0 undefinded if x=y=0

(3.1.5)

Tính góc θ2:

Hình 3-9. Góc quay arctan

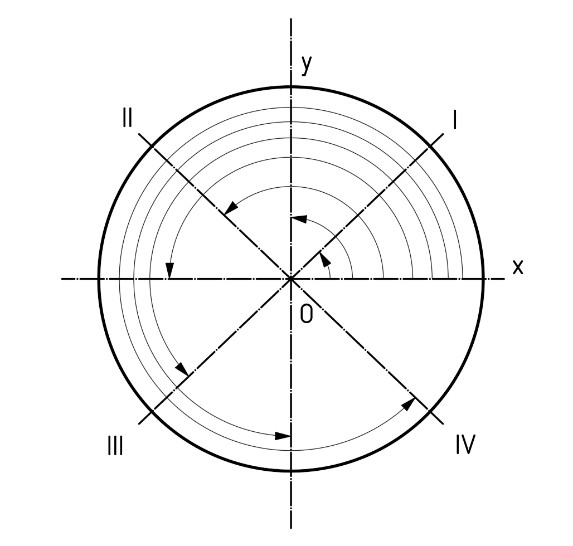
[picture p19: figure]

Hình 3-10. Góc quay arctan 2

Trang 30
{

n1=m1
n2=m2
{

# px∗cos(θ0)−d0⁺ py∗sin( θ0 )=L3∗cos(θ1⁺θ2⁺θ3

# )+ L2∗cos(θ1⁺θ2

# )+L1∗cos(θ1

)

# pz⁻d0=L3∗sin (θ1⁺θ2⁺θ3

# )+L2∗sin(θ 1⁺θ 2

# )+L1∗sin(θ1

)
{

# px∗cos(θ0 )−d0⁺ py∗sin( θ0 )−L3∗cos (θ1⁺θ2⁺θ3

# )=L2∗cos (θ1⁺θ2

# )+L1∗cos (θ1

)

# pz⁻d0⁻L3∗sin (θ1⁺θ2⁺θ3 )=L2∗sin( θ1⁺θ2)+L1∗sin (θ1)

Đặt {

# nx=L2∗cos(θ 1⁺θ 2 )+L1∗cos(θ1) ny=L2∗sin (θ1⁺θ2 )+L1∗sin (θ1)

=> ¿ | (3.1.6)

=> ¿

=> (n¿ ¿ x )

2
+(n¿¿ y )

2=L2

2∗(C12

2
+S12

2
)+L1
| 2∗(C1
| 2 +S1
| 2
)+2∗L1∗L2∗(C1∗C12⁺S1∗S12)¿ ¿

# Với {

# C1=cos(θ 1) C12=cos (θ1⁺θ2

)

# S1=sin (θ1

)

# S12=sin (θ1⁺θ2

)

(3.1.7)

=> (n¿ ¿ x )

2
+(n¿¿ y )

2=L2

2
+L1

2
+2∗L1∗L2∗(C1∗C12⁺S1∗S12 )¿ ¿

Rút gọn bằng Matlab: (C1∗C12⁺S1∗S12) = C2

=> (n¿ ¿ x )

2
+(n¿¿ y )

2=L2

2
+L1

2
+2∗L1∗L2∗C2 ¿ ¿ | (3.1.8)

=> C2=(n¿¿ x)

2
+

(n¿¿ y )

2
L2

2
+L1

2
+2∗L1∗L2

¿ ¿

(3.1.9)

Vì đường nét đứt ngang là đường cân bằng và cánh tay luôn chuyển động để hướng đầu hút ở

vị trí cân bằng nên θ1⁺θ2⁺θ3=0

Trang 31
{

# nx=px∗cos(θ0)−d0⁺ py∗sin( θ0 )−L3∗cos(θ1⁺θ2⁺θ3

)

# ny=pz⁻d0⁻L3∗sin (θ1⁺θ2⁺θ3

)
{

# nx=px∗cos(θ0 )−d0⁺ py∗sin( θ0)−L3 ny=pz⁻d0

Để tính được góc trong vòng tròn lượng giác thì ta phải biến đổi về hàm lượng giác tan từ

đó suy ra arctan2

Ta có: C2

2
+S2

2=1→S2=√1−C2
2

=> tan(θ2
¿=

# sin (θ2

)

# cos(θ2

)

# =¿θ2=arctan 2(S2

,C2
) | (3.1.10)

Tính góc θ1 :
{

# nx=L2∗cos(θ 1⁺θ2)+L1∗cos(θ 1 ) ny=L2∗sin (θ1⁺θ2)+L1∗sin (θ1 )

Sử dụng Matlab để khai triển cos(θ1⁺θ2 ) vàsin (θ1⁺θ 2):

¿

¿

¿

¿

¿

# Trường hợp 1: cos(θ 1 )

Trang 32

# => cos(θ1 )=¿ nx⁺ L2∗sin (θ2 )∗ny⁻L2∗cos ¿ ¿ ¿ ¿

# =nx∗(L2∗cos(θ2 )+L1)+L2∗sin (θ2)∗¿ ¿ ¿

=

# nx∗(L2∗cos(θ2 )+L1 )+L2∗sin (θ 2)∗n y⁻L2

# 2∗cos( θ1 )∗sin (θ2

)

2

¿ ¿ ¿

=

# nx∗(L2∗cos(θ2)+L1)+L2∗sin (θ2)∗n y

¿ ¿ ¿

# => cos(θ1 )∗¿ =>cos(θ 1 )∗¿

Rút gọn mẫu 2 vế:

# =>cos(θ1 )∗¿

# =>cos(θ1 )=

# nx∗( L2∗cos(θ2)+L1 )+L2∗sin( θ2 )∗ny

¿ ¿

(1) (3.1.11)

# Trường hợp 2: sin (θ1)

# => sin (θ1 )=ny⁻L2∗sin

# (θ2 )∗nx⁺L2∗sin (θ1)∗sin (θ2

)

¿ ¿

¿

=ny
∗¿ ¿

=n y
∗¿ ¿

=n y
∗¿ ¿

# => sin (θ1)∗

[
1+

L2

# 2∗sin (θ2)

2

# ( L2∗cos(θ2)+L1)

2 ]
=n y
∗¿ ¿

# => sin (θ1 )∗

[

# ( L2∗cos(θ2 )+L1)

2
+L2

# 2∗sin (θ 2)

2

# (L2∗cos(θ2 )+L1 )

2 | ]
=ny
∗¿¿

Rút gọn mẫu 2 vế:

Trang 33

# =>sin (θ1)∗¿ [( L2∗cos(θ2 )+L1)

2
+ L2

2

# ∗sin (θ2 )

2

]=ny
∗¿ ¿

# => sin (θ1 )=ny

∗¿ ¿ ¿ (2)

Từ (1) và (2) => tan(θ1
¿=

# sin (θ1

)

# cos(θ1

)

=ny
∗¿ ¿ | (3.1.12)

Đặt A = n y
∗¿ | (3.1.13)

# B = nx∗(L2∗cos(θ2 )+L1)+L2∗sin (θ2 )∗ny

Vậy θ1 = arctan2 (A,B)

Tính góc θ3:

Ta có: θ1⁺θ2⁺θ 3=0 | (3.1.14)

# => θ3=−θ1⁻θ2

ÁP DỤNG VÀO YÊU CẦU ĐỀ TÀI DI CHUYỀN VẬT VÀO Ô 2x2

Trang 34

- Sơ đồ về khoảng cách từ gốc cánh tay đến các 4 khối vuông 5x5x5cm như sau:

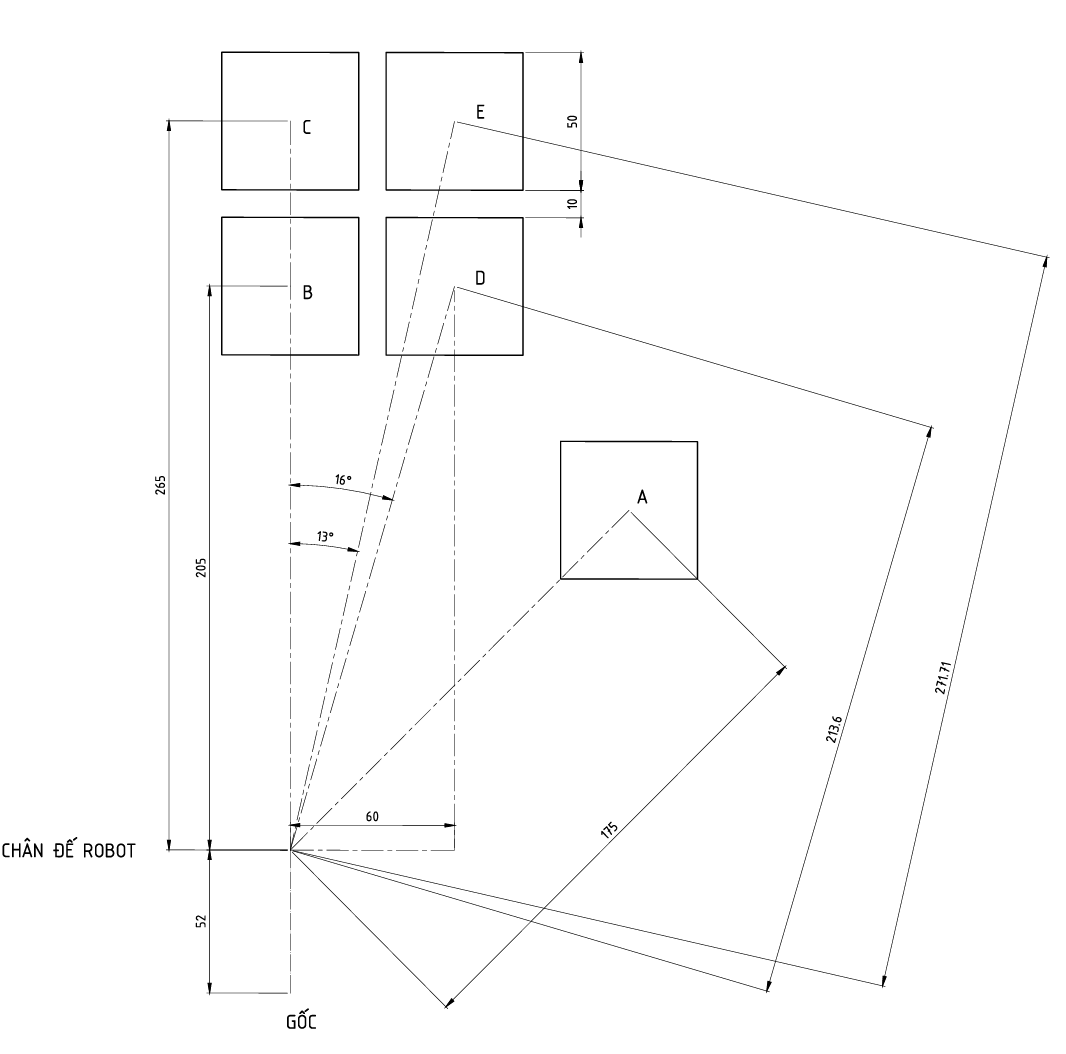
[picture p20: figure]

- Vật đặt tại vị trí A sẽ được nhấc và đưa vào lần lượt các vị trí B, C, D, E
a) Home

-Vì đây là vị trí ban đầu của cánh tay robot nên sẽ sử dụng công thức tính vi bước cho

động cơ để xác định các góc quay

Trang 35

- Trong thiết kế có thêm công tắc hành trình giúp cho cánh tay không hoạt động vượt quá

ngưỡng an toàn cho phép để tránh việc hư hỏng.

- Thực tế Driver điều khiển sẽ có sai số | 200 − | ¿

+¿ ¿
¿

bước nên khi sử dụng số liệu tính toán thì

phải ước lượng để đến được vị trí mong muốn trong lập trình.

- Động cơ NEMA17 có góc bước gốc là 1,8°/bước và sử dụng driver A4988 để điều

khiển 1/16 bước nên ta có công thức như sau:

θvi bước=

1,8°
16

=0,1125 °

- Đặt {
θ0=0°
θ1=90°
θ2=0°
θ3=−(−90 °)−0°=90°
- Vì θ3 là khớp xoay bị động do thiết kế nên không cần tính vi bước của động cơ

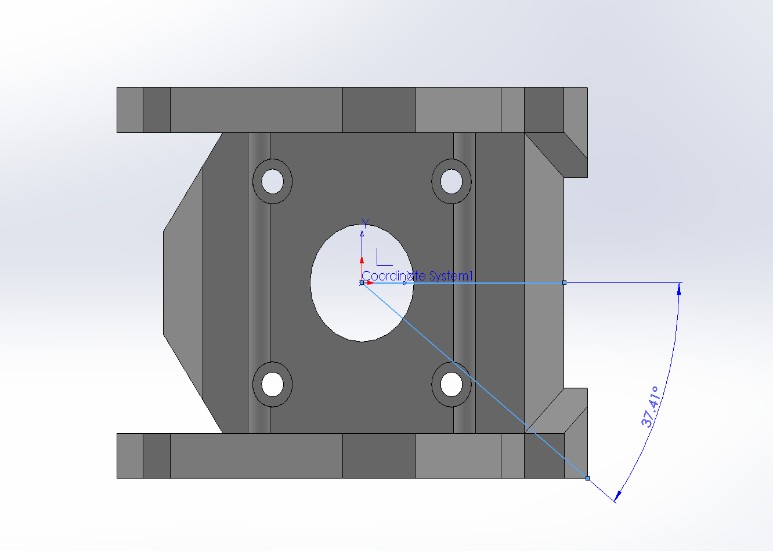
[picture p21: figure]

- Cánh tay robot có 3 công tắc hành trình và được bố trí như sau:

+ Khớp xoay 1 bao gồm có nắp động cơ 1 và đế động cơ 2 3 khi xoay cùng chiều kim

đồng hồ chạm vào công tắc hành trình thì sẽ quay ngược lại với số bước bằng với các góc

như trong hình vẽ như sau:

khi đế khớp xoay 2 và 3 chạm vào công tắc ở nắp đế động cơ 1 thì phải cần thực hiện

Hình 3.2: Nắp đế động cơ 1 | Hình 3.2: Đế khớp xoay động cơ 2 và 3

Trang 36

phép tính góc như sau:
44,29 °−37,41°=6,88 °

Để trung điểm khớp xoay 2 và 3 luôn nằm đúng tại góc 0 độ

- Tính số vi bước cần để xoay ngược lại khi chạm công tắc hành trình để θ0=0°:

Số bước¿

6,88°
0,1125°

=¿ 65 bước

- Công tắc hành trình ở khớp 2 được bố trí như hình sau:

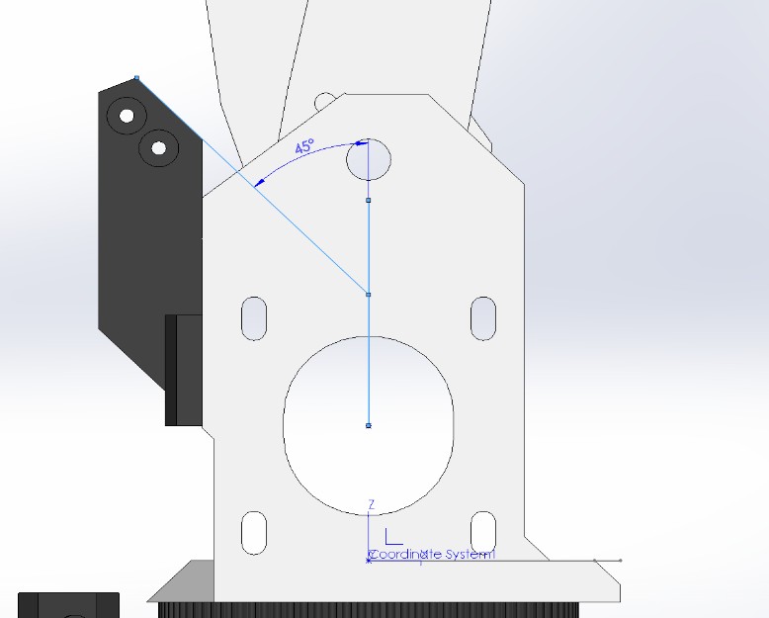
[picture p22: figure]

- Tính số vi bước cần để xoay ngược lại khi chạm công tắc hành trình để θ1=90 °:

Số bước¿

45 °
0,1125°

# =400+100(sailệch)=500 bước (3.1.15)

- Do cơ chế để xoay khâu 3 phải sử dụng tới khớp bị động để giúp cho động cơ 2 3 được

ở cùng vị trí nhưng vẫn đảm bảo là xoay được khâu 3

Hình 3.3: Đế khớp xoay động cơ 2 và 3 với giá đỡ công tắc hành trình

Hình 3.4: Khớp xoay bị động | Hình 3.5: cạnh khớp xoay bị động khi chạm vào công tắc hành trình

Trang 37

- Để khớp xoay 3 ở góc mong muốn là θ2=0 ° thì cạnh khớp xoay phải song song với mặt

đất

- Tính số vi bước cần để xoay ngược lại khi chạm vào công tắc hành trình để θ2=0 °:

Số vi bước¿

12,77°
0,1125°

=114 + 6 = 120 bước

I) Giai đoạn 1: A → B
- Thao tác của cánh tay 6 vị trí chuyển động : Home → A1 → A → A1 → B1 → B
- Vật là khối lập phương có kích thước là 5x5x5 cm và đặt tại và các thông số đã đặt ở

# trên d0=50mm; L1=¿ 250 mm; L2=300mm; L3=20mm

a) Vị trí A
- | Vị trí | A | trong tọa | độ cho | phép hoạt | động của | cánh | tay robot | là

# px=151,98; p y=151,98 ; pz=110

- Giả sử duy trì được vật luôn hướng song song với mặt đất thì ta có điều kiện: {
θ1>0
θ2<0
θ3>0
- Tính góc θ0:

# θ0=arctan 2( p y

, px

) vì px > 0 => θ0=arctan (

p y
px

# ) = arctan (

151,98
151,98 )= 45°
- Tính góc θ2:
Ta có : | {

# nx=px∗cos(θ0)−d0⁺ py∗sin( θ0)−L3 ny=pz⁻d0

(3.1.16)

=> | {

# nx=151,98∗cos(45 °)−100+151,98∗sin (45 °)−82

ny=110−100

=> | {

nx=32,93
ny=10

Trang 38

Tính được cos(θ 2 )=(n¿¿ x)

2
+

(n¿¿ y )

2
L2

2
+L1

2
+2∗L1∗L2

=

32,93²

+10²
300²

+250²
+2∗250∗300

=3,91×10⁻³
¿ ¿ > 0

(3.1.17)

Ta có: C2

2
+S2

2=1→S2=√1−C2
2
(3.1.18)

=> tan(θ2
¿=

# sin (θ2

)

# cos(θ2

)

# =¿θ2=arctan 2(S2

,C2
)

# => θ2=arctan(

S2
C2

)

# =arctan (

√1−C2

2

C2 )

# =¿ ¿ arctan (

√1−3,91×10⁻³²

3,91×10⁻³ )=90°

Để thỏa điều kiện thì θ2=−90 °<0

- Tính góc θ1:

Ta có A = n y
∗¿

# B = nx∗(L2∗cos(θ2 )+L1)+L2∗sin (θ2 )∗ny => A = 10∗(300∗cos(−90°)+250)−300∗sin (−90 °)∗32,93=12379 B =32,93∗(300∗cos(−90 °)+250)+300∗sin (−90 °)∗10=5232,5

θ1 = arctan2 (A,B) = artan(

A

# B )=artan(

44307,7
34666,15 )= 67° | (3.1.19)
- Tính góc θ3:

Ta có: θ1⁺θ2⁺θ3=0

=> θ3=−θ1⁻θ 2=−67 °−(−90°)=23 °

Các góc của cánh tay khi ở vị trí A:{
θ1=67 °
θ2=−90°
θ3=23 °

=> Thỏa yêu cầu vị trí A

Vì θ3 là khớp xoay bị động do thiết kế nên không cần tính vi bước của động cơ

- Tính số vi bước cần để xoay được θ0=45 °:

Số bước¿

45 °
0,1125°
=400+50(sailệch)=450 bước | (3.1.20)
- Tính số vi bước cần để xoay được θ1=52 ° vì vị trí home θ1=90 °:

Trang 39

Số i bước¿

90 °−52°
0,1125°
=¿ 205 + 15 (sai lệch) = 220 bước | (3.1.21)
- Tính số vi bước cần để xoay được θ2=86 °:

Số bước¿

86 °
0,1125°

=800bước

Do góc thiết kế trong thực tế nên số vi bước sẽ có sự thay đổi là {

# θ0=450 bước θ1=220 bước θ2=800 bước

b) Vị trí B
- Vị trí B trong tọa độ cho phép hoạt động của cánh tay robot là px=0; py=257 ; pz=110
- Giả sử duy trì được vật luôn hướng song song với mặt đất thì ta có điều kiện: {
θ1>0
θ2<0
θ3>0
- Tính góc θ0:

# θ0=arctan 2( p y

, px

) vì px = 0 và py

# >0 nên θ0=arctan 2( p y

, px
) =

π
2

=¿90° (3.1.22)

- Tính góc θ2:
Ta có : | {

# nx=px∗cos(θ0 )−d0⁺ py∗sin( θ0)−L3 ny=pz⁻d0

=> | {

# nx=0∗cos(90 °)−100+257∗sin (90 °)−82

ny=1 10−100

=> | {

nx=75
ny=1 0

Tính được cos(θ 2 )=(n¿¿ x)

2
+

(n¿¿ y )

2
L2

2
+L1

2
+2∗L1∗L2

=

75²

+10²
300²

+250²
+2∗250∗300

=0,037 ¿ ¿ > 0

(3.1.23)

Ta có: C2

2
+S2

2=1→S2=√1−C2
2

Trang 40

=> tan(θ2
¿=

# sin (θ2

)

# cos(θ2

)

# =¿θ2=arctan 2(S2

,C2
)

# => θ2=arctan(

S2
C2

)

# =arctan (

√1−C2
2

C2 )

# =¿ ¿ arctan (

√1−0,033²

0,033 )=88°

Để thỏa điều kiện thì θ2=−88 °<0

- Tính góc θ1:

Ta có A = n y
∗¿

# B = nx∗(L2∗cos(θ2 )+L1)+L2∗sin (θ2 )∗ny => A = 10∗(300∗cos(−88 °)+250)−300∗sin (−88 °)∗75=25091 B =75∗(300∗cos(−88 °)+250)+300∗sin (−88 °)∗10=16537,1

θ1 = arctan2 (A,B) = artan(

A

# B )=artan(

35191,12
20050,6 )= 56°
- Tính góc θ3:

Ta có: θ1⁺θ2⁺θ3=0

=> θ3=−θ1⁻θ2=−56°−(−88 °)=32°

Các góc của cánh tay khi ở vị trí A:{
θ1=56 °
θ2=−88°
θ3=32°

=> Thỏa yêu cầu vị trí B

Vì θ3 là khớp xoay bị động do thiết kế nên không cần tính vi bước của động cơ

- Tính số vi bước cần để xoay được θ0=90 °:

Số bước¿

90°
0,1125°

# =800+150(sailệch)=950 bước

- Tính số vi bước cần để xoay được θ1=56 ° vì vị trí home θ1=90 °:

Số bước¿

90−56 °
0,1125°
=¿ 312 - 42 = 270 bước | (3.1.24)
- Tính số vi bước cần để xoay được θ2=−88°:

Số bước¿

88°
0,1125°

=750 bước

Trang 41

Do góc thiết kế trong thực tế nên số vi bước sẽ có sự thay đổi là {

# θ0=950 bước θ1=270 bước θ2=750 bước

c) Vị trí A1 và B1
- Vị trí A1 là :{

# θ0=450 bước θ1=0bước θ2=0bước

Vị trí B1: {

# θ0=950 bước θ1=0 bước θ2=0bước

II) Giai đoạn 1: A → C

- Thao tác của cánh tay 5 vị trí chuyển động : Home → A → A1 → C1 → C
a) Vị trí C1
- Vị trí C1 là :{

# θ0=950 bước θ1=0 bước θ2=0bước

b) Vị trí C
- Vị trí C trong tọa độ cho phép hoạt động của cánh tay robot là px=0; py=317 ; pz=110
- Giả sử duy trì được vật luôn hướng song song với mặt đất thì ta có điều kiện: {
θ1>0
θ2<0
θ3>0
- Tính góc θ0:

# θ0=arctan 2( p y

, px

) vì px = 0 và py

# >0 nên θ0=arctan 2( p y

, px
) =

π
2

=¿90°

- Tính góc θ2:
Ta có : | {

# nx=px∗cos(θ0 )−d0⁺ py∗sin( θ0)−L3 ny=pz⁻d0

=> | {

# nx=0∗cos(90 °)−100+317∗sin (90 °)−82

ny=1 10−100

=> | {

nx=135
ny=10

Trang 42

Tính được cos(θ 2 )=(n¿¿ x)

2
+

(n¿¿ y )

2
L2

2
+L1

2
+2∗L1∗L2

=

135²

+10²
300²

+250²
+2∗250∗300

=0,061 ¿ ¿ > 0

Ta có: C2

2
+S2

2=1→S2=√1−C2
2

=> tan(θ2
¿=

# sin (θ2

)

# cos(θ2

)

# =¿θ2=arctan 2(S2

,C2
)

# => θ2=arctan(

S2
C2

)

# =arctan (

√1−C2

2

C2 )

# =¿ ¿ arctan (

√1−0,033²

0,033 )=86,5°

Để thỏa điều kiện thì θ2=−86,5 °<0

- Tính góc θ1:

Ta có A = n y
∗¿

# B = nx∗(L2∗cos(θ2 )+L1)+L2∗sin (θ2 )∗ny => A = 10∗(300∗cos(−86,5 °)+250)−300∗sin (−86,5 °)∗135=43107,6 B =135∗(300∗cos(−86,5°)+250)+300∗sin (−86,5°)∗10=39216,8

θ1 = arctan2 (A,B) = artan(

A

# B )=artan(

43107,6
39216,8 )= 47,7°
- Tính góc θ3:

Ta có: θ1⁺θ2⁺θ3=0

# => θ3=−θ1⁻θ 2=−47,7 °−(−86,5 °)=38,8 °

Các góc của cánh tay khi ở vị trí A:{
θ1=47,7 °
θ2=−86,5°
θ3=38,8 °

=> Thỏa yêu cầu vị trí C

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

- Tính số vi bước cần để xoay được θ0=90 °:

Số bước¿

90°
0,1125°

# =800+150(sailệch)=950 bước

- Tính số vi bước cần để xoay được θ1=47,7 ° vì vị trí home θ1=90 °:

Trang 43

Số bước¿

90−47,7°
0,1125 °

=¿ 376 + 4 (sai lệch) = 380 bước

- Tính số vi bước cần để xoay được θ2=−86,5 °:

Số bước¿

86,5°
0,1125°

# =769−69(sailệch)=700 bước

Do góc thiết kế trong thực tế nên số vi bước sẽ có sự thay đổi là {

# θ0=950 bước θ1=350 bước θ2=700 bước

III) Vị trí D

a) Vị trí D

Vị trí D trong tọa độ của cánh tay robot là px=60 ; p y=257 ; pz=110

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

# θ0=arctan 2( p y

, px

) vì px = 60 và py

# >0 nên θ0=arctan (

p y
px

# ) = arctan (

257
60 ) ¿77°
- Tính góc θ2:
Ta có : | {

# nx=px∗cos(θ0 )−d0⁺ py∗sin( θ0)−L3 ny=pz⁻d0

=> | {

# nx=60∗cos(77°)−100+257∗sin (77 °)−82

ny=110−100

=> | {

nx=82
ny=1 0

Tính được cos(θ 2 )=(n¿¿ x)

2
+

(n¿¿ y )

2
L2

2
+L1

2
+2∗L1∗L2

=

82²

+10²
300²

+250²
+2∗250∗300

=0,021 ¿ ¿ > 0

Trang 44

Ta có: C2

2
+S2

2=1→S2=√1−C2
2

=> tan(θ2
¿=

# sin (θ2

)

# cos(θ2

)

# =¿θ2=arctan 2(S2

,C2
)

# => θ2=arctan(

S2
C2

)

# =arctan (

√1−C2

2

C2 )

# =¿ ¿ arctan (

√1−0,021²

0,021 )=89°

Để thỏa điều kiện thì θ2=−89 °<0

- Tính góc θ1:

Ta có A = n y
∗¿

# B = nx∗(L2∗cos(θ2 )+L1)+L2∗sin (θ2 )∗ny => A = 10∗(300∗cos(−89 °)+250)−300∗sin (−89 °)∗82=27148 B =82∗(300∗cos(−89 °)+250)+300∗sin (−89 °)∗10=23928,87

θ1 = arctan2 (A,B) = artan(

A

# B )=artan(

27148
23928,87 )= 49°
- Tính góc θ3:

Ta có: θ1⁺θ2⁺θ3=0

=> θ3=−θ1⁻θ2=−49 °−(−89 °)=40 °

Các góc của cánh tay khi ở vị trí A:{
θ1=49°
θ2=−89°
θ3=40°

=> Thỏa yêu cầu vị trí D

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

- Tính số vi bước cần để xoay được θ0=77 °:

Số bước¿

77°
0,1125°

# =685+150(sai lệch)=830 bước

- Tính số vi bước cần để xoay được θ1=49 ° vì vị trí home θ1=90 °:

Số bước¿

90−49°
0,1125°

=¿ 365 - 65 = 300 bước

- Tính số vi bước cần để xoay được θ2=−89°:

Số bước¿

89°
0,1125°

=790 bước

Trang 45

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

# θ0=830 bước θ1=250 bước θ2=790 bước

b) Vị trí D1

Vị trí D1 là :{

# θ0=830 bước θ1=0 bước θ2=0 bước

1) Vị trí E

Vị trí E trong tọa độ của cánh tay robot là px=60 ; p y=317 ; pz=110

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

# θ0=arctan 2( p y

, px

) vì px = 60 và py=317 nên θ0=arctan (

p y
px

) = 79°

- Tính góc θ2:
Ta có : | {

# nx=px∗cos(θ0 )−d0⁺ py∗sin( θ0)−L3 ny=pz⁻d0

=> | {

# nx=60∗cos(79°)−100+257∗sin (79°)−82

n y=110−100

=> | {

nx=81,7
ny=1 0

Tính được cos(θ 2 )=(n¿¿ x)

2
+

(n¿¿ y )

2
L2

2
+L1

2
+2∗L1∗L2

=

81.7²

+10²
300²

+250²
+2∗250∗300

=0,04 ¿ ¿ > 0

Ta có: C2

2
+S2

2=1→S2=√1−C2
2

Trang 46

=> tan(θ2
¿=

# sin (θ2

)

# cos(θ2

)

# =¿θ2=arctan 2(S2

,C2
)

# => θ2=arctan(

S2
C2

)

# =arctan (

√1−C2
2

C2 )

# =¿ ¿ arctan (

√1−0,04²

0,04 )=88 °

Để thỏa điều kiện thì θ2=−88 °<0

- Tính góc θ1:

Ta có A = n y
∗¿

# B = nx∗(L2∗cos(θ2 )+L1)+L2∗sin (θ2 )∗ny => A = 10∗(300∗cos(−88 °)+250)−300∗sin (−88 °)∗81.7=27099 B =81.7∗(300∗cos(−89 °)+250)+300∗sin (−89 °)∗10=24278.55

θ1 = arctan2 (A,B) = artan(

A

# B )=artan(

27099
24278.55 )= 48°
- Tính góc θ3:

Ta có: θ1⁺θ2⁺θ3=0

=> θ3=−θ1⁻θ 2=−48 °−(−88 °)=40 °

Các góc của cánh tay khi ở vị trí E:{
θ1=48°
θ2=−88°
θ3=40°

=> Thỏa yêu cầu vị trí E

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

- Tính số vi bước cần để xoay được θ0=79°:

Số bước¿

79°
0,1125°

# =685+150(sai lệch)=850 bước

- Tính số vi bước cần để xoay được θ1=48 ° vì vị trí home θ1=90 °:

Số bước¿

90−48°
0,1125°

=¿ 375 bước

- Tính số vi bước cần để xoay được θ2=−88°:

Số bước¿

88°
0,1125°

# =782−82=700 bước

Trang 47

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

# θ0=850 bước θ1=375 bước θ2=700 bước

b) Vị trí E1

Vị trí E1 là :{

# θ0=850 bước θ1=0 bước θ2=0 bước

### 3.2. Kiểm nghiệm bền

- Nhựa PETG là một loại nhựa nhiệt dẻo kỹ thuật rất phổ biến, đặc biệt trong ngành in

3D, cơ khí chính xác, điện – điện tử, và vỏ thiết bị

- Số liệu nhựa PETG :

Bảng 3-1: Thông số kỹ thuật của vật liệu nhựa Petg

Đại lượng | Phương pháp thử | Giá trị
Độ bền kéo | ASTM D3039 | 50 – 75 MPa
Mô đun kéo | ASTM D3039 | 2000 – 2700 MPa
Moment uốn | ISO 178 | 1170 - 2760 MPa
Độ bền uốn | ASTM D790 | 50 – 80 MPa
Ứng suất chảy | ISO 178 | 28,3 – 101 MPa

Kiểm nghiệm bền:

Trang 48

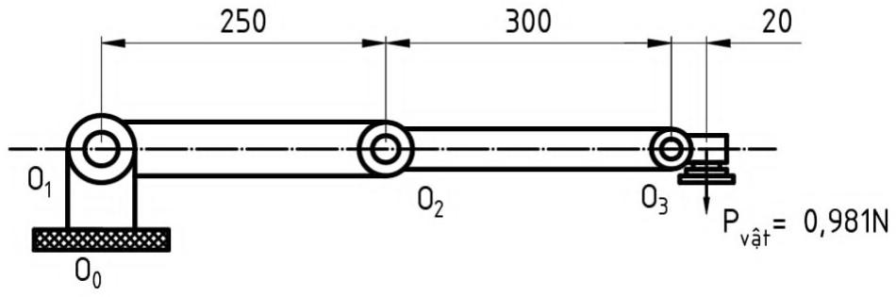
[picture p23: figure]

Hình 3-6. Cánh tay robot 4 bật tự do 2D

Ví dụ : chịu tải m= 100 g

- Lực:
F = P = m x g = 0,1 x 9,81 = 0,981 N | (3.2.1)
- Chiều dài các khâu như sau:

Khâu 2 ( θ1 - θ2 ) = 250 mm = 0,25 m

Khâu 3 (θ2 - θ3 ) = 300 mm = 0,3 m

Khâu 4 ( θ3- θ4 ) = 20 mm = 0,02 m

- Khâu 2 :
- Tiết diện khâu 2:

b = 19 mm = 0,019 m

h = 25 mm = 0,025 m

- Moment quán tính khâu 2:

# I = hb

3
12

=

0,025 x 0,019³
12

= 1.429 x 10⁻⁸
m

4
(3.2.2)
- Khoảng cách cánh tay đuổi dài nhất và nguy hiểm nhất :
L2,3,4 = L2 + L3 + L4 = 0,25 + 0,3 + 0,02 = 0,57 m | (3.2.3)
- Khoảng cánh từ trục đến trung hòa khâu 2: từ (θ1⁻θ4 ¿

Trang 49

y =

h
2

=

0,025
2

= 0,0125 m (3.2.4)

- Sau khi có các thông số cơ bản trên ta tính được moment uốn :

Moment:

M2 = F x L2,3,4 = 0,981 x 0,57 = 0,56 N.m | (3.2.4)

Ứng suất uốn:

σ M 2 =

M2

x y
I

=

0,56 x0,0125
1,429 x 10⁻⁸ = 489853 Pa = 0,489 MPa < 70 MPa (3.2.5)

→ Thỏa điều kiện bền của vật liệu

- Khâu 3 :
- Tiết diện khâu 3:

b = 20 mm = 0,02 m

h = 15 mm = 0,015 m

- Moment quán tính khâu 3: từ (θ2⁻θ3 ¿

# I = h b

3
12

=

0,015 x 0,02³
12

= 1 x 10⁻⁸
m
4 | (3.2.6)
- Khoảng cánh từ trục đến trung hòa khâu 3 :

y =

h
2

=

0,015
2
= 0,0075 m | (3.2.7)
- Khoảng cách cánh tay đuổi nguy hiểm:
L3,4 = L3 + L4 = 0,3 + 0,02 = 0,32 m | (3.2.8)

Moment:

M3 = F x L = 0,981 x 0,32 = 0,31 Nm | (3.2.9)

Ứng suất uốn:

σ 3=

M3

x y
I

=

0,31 x 0,0075
1x10⁻⁸

= 2325000 Pa = 0,2325 MPa < 70MPa (3.2.10)

→ Thỏa điều kiện bền của vật liệu

Trang 50

3.3 Tính toán cánh tay robot.

- Robot với cấu hình 4 bậc tự do, bao gồm : 4 khớp xoay , khớp đầu tiên giúp cánh

tay xoay sang 2 bên , tiếp đó là 2 khớp xoay giúp cánh tay gập lên gập xuống để

nâng hạ vật, cuối cùng là khớp giúp định vị vật chính xác hơn và đùng đầu hút để

hút vật.

a. Chọn vật liệu:

Vật liệu : đựa trên những ưu nhược điểm trên nhóm

em quyết định chọn vật liệu nhựa PETG vì những lý

do sau :

- Nhẹ, giá thành thấp.
- Có thể dễ dàng chế tạo các linh kiện bằng cách in

3D

b. Chọn động cơ:
- Sau khi ta tính toán chọn cơ cấu phủ hợp cho các trục khớp, ta thiết kế chi tiết các khâu

này trên phần mềm SOLIDWORKS theo bảng sau:

Bảng 3-2. Bảng số liệu khối lượng các khâu

Các khâu | Tên gọi | Vật liệu | Khối lượng | Ghi chú
Khâu 1 | Thân đế | PETG | 10 g
| Bộ truyền | PETG, Sắt | 5 g
| Động cơ | Thép, đồng | 350 g

Trang 51

Khâu 2 | Thân | PETG | 135 g | Có thêm 2 thanh nhỏ hỗ trợ điều khiển
| Động cơ | Thép, đồng | 200 g/1 động cơ | Gồm của khâu 2 và 3
| Ổ bi | Thép | 5 g
Khâu 3 | Thân | PETG | 62 g | Có thêm 2 thanh nhỏ hỗ trợ điều khiển
Khâu 4 | Thân | PETG | 5 g | Bao gồm giác hút
- Để chọn được động cơ cho các khâu ta cần phải tính được các momen xoắn cho từng

khâu và từ đó ta chọn được động cơ thích hợp:

- Khi đã có các số liệu ta tính được momen xoắn của khâu 1 như sau:
+ Do Từ O đến O (trục đỡ đứng) nên ta có : ₀ | ₁

Tổng chiều dài tay đòn tính từ O đến vật: ₁

L2,3,4=165+196+20 = 381mm =0,381m (3.3.1)

Trọng lượng vật gắn ở đầu tay:

Pv ật= 0,981 N

Khối lượng cánh tay:

mtay= 0,807kg

Từ đó suy ra được trọng lượng của cánh tay:

Ptay= 0,807 x 9,81 = 7,92N | (3.3.2)

+ Trọng tâm cánh tay nằm ở giữa phần ngang:

Tổng chiều dài cánh tay (không tính trục đỡ):

Ltay = L2 + L3 =361 mm | (3.3.3)

Trọng tâm cánh tay:

dtay =

361
2
= 180,5 mm = 0,1805 m | (3.3.4)

Do khâu đế chúng em có làm đai thang tỉ lệ 4:1 suy ra moment động cơ thay đổi như sau:

Mra = Mđộngcơ x 4 = 0,6 x 4 = 2,4 N.m | (3.3.5)

→ Từ đó suy ra moment xoắn tại O là: ₀

Trang 52

M1 = Pvậtx L2,3,4 + Ptay x dtay = 0,981 x 0,381 + 7,92 x 0,1805 = 1,802 N.m < 2,4 N.m

(3.3.6)

- Dựa vào mục 3.2 kiểm nghiệm bền ở trên và moment vừa tính khâu 1 ở trên ta có được

kết quả của moment xoắn khâu 1,2 và khâu 3 như sau:

M1 = 1,082 Nm < Mra(đai 4:1)

M2=¿0,370 Nm < Mra(đai 4:1)

M3 = 0,192 Nm < Mra(đai 4:1)

- Ta chọn động cơ Step NEMA 17LS19-1684E-200G có các thông số kỹ thuật như sau:

Động cơ bước khâu 1: NEMA 17 (0,6 N.m)

- Mã: 17LS19-1684E-350G
- Thông sổ kĩ thuật:
- Điện áp: 3,57V
- Dòng điện định mức / pha: 1,7A
- Mô-men xoãn cho phép: 0,6 N.m

Động cơ bước khâu 2 và khâu 3: NEMA17 (0,34 N.m)

- Mã: 17LS19-1684E-200G
- Thông sổ kĩ thuật:
- Điện áp: 3,8V
- Dòng điện định mức / pha: 1,3A

Mô-men xoãn cho phép: 0,34 N.m

Hình 3-7. Động cơ bước NEMA17 tiêu chuẩn 0,6 N.m

Hình 3-8. Động cơ bước NEMA17 tiêu chuẩn 0,34

N.m

Trang 53

CHƯƠNG 4: MÔ PHỎNG VÀ THỰC NGHIỆM BẰNG SOLIDWORKS

### 4.1. Thiết kế cánh tay robot

a) Đế khớp xoay và khâu 1
- Khâu 1 gồm 2 phần bao gồm nắp và đế
- Đế tiếp xúc với động cơ và bắt với khâu 1 được làm bằng vật liệu nhựa PETG.
- Nắp được mang bộ truyền đai GT2 và có vòng bi đỡ chặn để truyền moment cho khớp

xoay 1 chuyển động

- Khâu 1 được gắn lên để bằng liên kết bu lông đồng thời nhận chuyển động và quay

trong mặt phẳng song song với mặt phẳng đế.

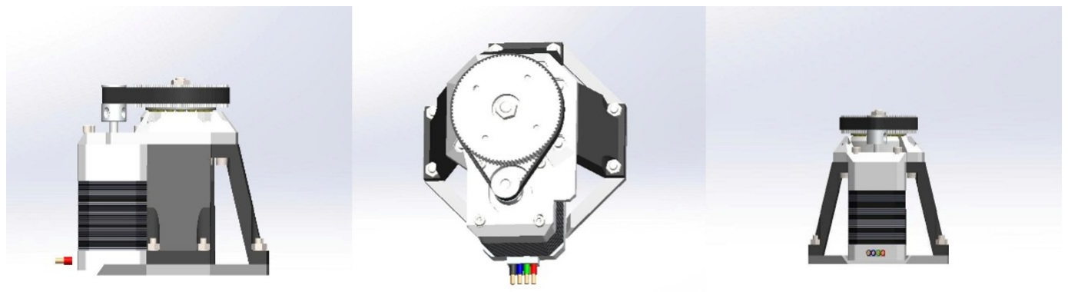
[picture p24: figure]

Hình 4-1. Đế khớp xoay và khâu 1

b) Đế khớp xoay và khâu 2

Khâu 2 là khâu giúp mô hình đạt các thông số chiều cao yêu cầu, là khâu có chuyển động

quay vuông góc với mặt phẳng đế. Ngoài ra khâu 2 còn có 3 thanh trục kết nói song song

với trục chính khâu 2 để hỗ trợ chuyển động cho khâu 3 và 4 và mắc khác cũng hỗ trợ lực

giúp khâu 2 bền hơn.

Trang 54

Hình 4.2. Đế khớp xoay và khâu 2

c) Khâu 3

Khâu 3 gắn với khâu 4 thông qua 1 khớp xoay giúp khâu 4 luôn song song với mặt

phẳng. Mặt khác khâu 3 có thêm 2 trục song song với trục chính nhằm hỗ trợ lực cho

khâu 3 giúp khâu 4 chuyển động. Có hình dạng như hình dưới:

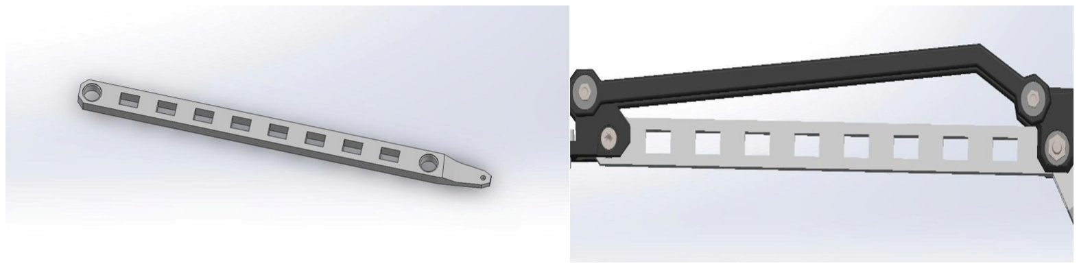
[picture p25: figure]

Hình 4-3. Đế khớp xoay và khâu 3

d) Khâu 4

Khâu 4 luôn luôn song song với mặt phẳng và được kết hợp thêm giác hút giúp hút vật và

vận chuyển vật từ A sang B.

Hình 4-4. Khâu 4

e) Cánh tay máy hoàn chỉnh và kiểm nghiệm bền

Sau khi có thiết kế các chi tiết của cánh tay máy và lắp ráp:

- Ứng suất chảy (yield strength) là giá trị ứng suất lớn nhất mà vật liệu có thể chịu được

trước khi bắt đầu biến dạng dẻo vĩnh viễn.

- Ứng suất chảy của nhựa PETG từ 28,3 – 101 MPa

Trang 55

- Mức độ biến dạng dẻo được thể hiện trên thanh màu, hiện tại khi Mô phỏng cánh tay

duỗi thẳng và chịu một lực ngay giác hút chân không là 10 N tương đương với 1 kg thì

cánh tay vẫn ở trong ứng suất uốn cho phép là 51,4 MPa

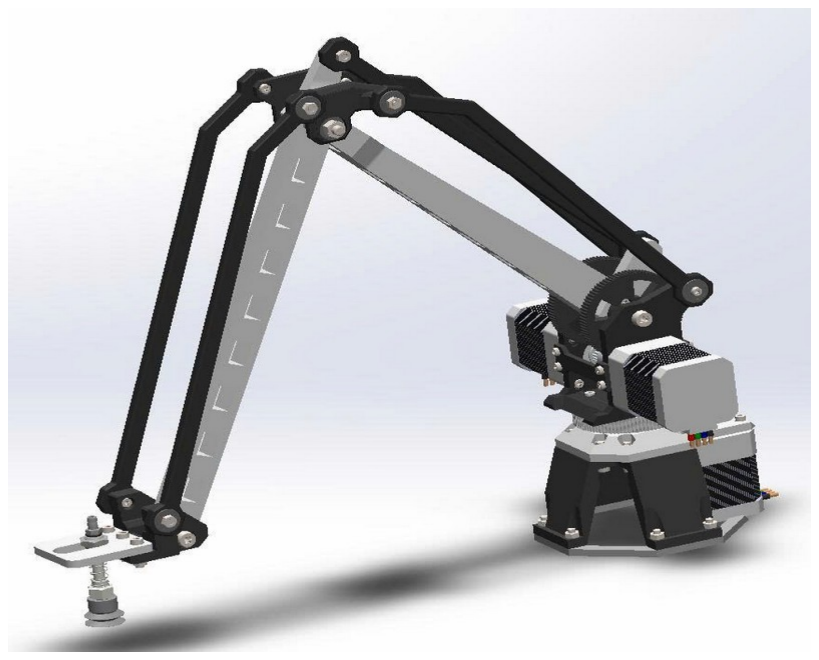
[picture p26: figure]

Hình 4-5. Tay máy khi lắp ráp hoàn chỉnh và kiểm nghiệm bền

=> Thỏa yêu cầu đề tài đặt ra ban đầu là nhấc được vật có khối lượng 100 gram

Trang 56

### 4.2. Sơ đồ điện

Hình 4-6. Sơ đồ điện của cánh tay robot

Trang 57

### 4.3. Lưu đồ giải thuật

Trang 58

### 4.3. Lưu đồ giải thuật

Trang 59

### 4.4. Chương trình ARDUINO

#include <AccelStepper.h>

#include <EEPROM.h>

// Cấu hình động cơ

#define STEP_PIN1 | 18

#define DIR_PIN1 | 5

#define ENA_PIN1 | 19

#define LIMIT1_PIN 15

#define STEP_PIN2 | 22

#define DIR_PIN2 | 21

#define ENA_PIN2 | 23

#define LIMIT2_PIN 35

#define STEP_PIN3 | 27

#define DIR_PIN3 | 14

#define ENA_PIN3 | 26

#define LIMIT3_PIN 34

// Cấu hình nút nhấn và relay

#define BUTTON1_PIN 12 // nút nhấn relay 1

#define RELAY1_PIN 2 // relay 1

#define BUTTON2_PIN 4 // nút nhấn relay 2

#define RELAY2_PIN 25 // relay 2

#define EEPROM_SIZE 512

// Cấu trúc lưu trữ vị trí và trạng thái relay

struct Position {

int pos1;

int pos2;

int pos3;

Trang 60

byte relayFlags; // Bit 0: relay1, Bit 1: relay2

};

#define MAX_POSITIONS (EEPROM_SIZE / sizeof(Position))

AccelStepper stepper1(AccelStepper::DRIVER, STEP_PIN1, DIR_PIN1);

AccelStepper stepper2(AccelStepper::DRIVER, STEP_PIN2, DIR_PIN2);

AccelStepper stepper3(AccelStepper::DRIVER, STEP_PIN3, DIR_PIN3);

Position positions[MAX_POSITIONS];

int posCount = 0;

String input = "";

int step = 1;

int lastVal1 = 65;

int lastVal2 = 0;

int lastVal3 = 0;

bool playFinished = false;

bool restartRequested = false;

byte currentRelayFlags = 0;

// Biến chống debounce và đếm tổng số lần nhấn

unsigned long lastDebounceTime1 = 0;

unsigned long lastDebounceTime2 = 0;

const unsigned long debounceDelay = 50;

int lastReading1 = LOW;

int lastStableState1 = LOW;

int lastReading2 = LOW;

int lastStableState2 = LOW;

int relayToggleCount1 = 0;

int relayToggleCount2 = 0;

enum HomingState { START, MOVING_TO_LIMIT, RETURNING_TO_ORIGIN, DONE };

Trang 61

HomingState homing1 = START, homing2 = START, homing3 = START;

bool printedInitialPrompt = false;

// Thêm biến timeout

const unsigned long HOMING_TIMEOUT = 20000; // 20 giây

const float HOMING_SPEED = 300.0; // Tốc độ đồng nhất cho cả hai giai đoạn homing

bool motorsAtPosition = false;

bool relay1_enabled = false;

bool relay2_enabled = false;

// Biến để xử lý lệnh change và delete

int changeStep = 0;

int selectedPosition = 0;

enum CommandMode { NONE, CMD_CHANGE, CMD_DELETE };

CommandMode commandMode = NONE;

// Biến để xử lý pause

bool isPaused = false;

int currentPlayIndex = 0;

void setup() {

Serial.begin(115200);

EEPROM.begin(EEPROM_SIZE);

// Khởi tạo chân relay và nút nhấn

pinMode(RELAY1_PIN, OUTPUT);

pinMode(RELAY2_PIN, OUTPUT);

digitalWrite(RELAY1_PIN, LOW);

digitalWrite(RELAY2_PIN, LOW);

pinMode(BUTTON1_PIN, INPUT_PULLDOWN);

Trang 62

pinMode(BUTTON2_PIN, INPUT_PULLDOWN);

// Khởi tạo chân động cơ

pinMode(ENA_PIN1, OUTPUT);

pinMode(ENA_PIN2, OUTPUT);

pinMode(ENA_PIN3, OUTPUT);

digitalWrite(ENA_PIN1, LOW);

digitalWrite(ENA_PIN2, LOW);

digitalWrite(ENA_PIN3, LOW);

pinMode(LIMIT1_PIN, INPUT_PULLUP);

pinMode(LIMIT2_PIN, INPUT_PULLUP);

pinMode(LIMIT3_PIN, INPUT_PULLUP);

// Kiểm tra trạng thái ban đầu của công tắc

Serial.print("[DEBUG] Trạng thái công tắc ban đầu - LIMIT1: ");

Serial.print(digitalRead(LIMIT1_PIN));

Serial.print(", LIMIT2: ");

Serial.print(digitalRead(LIMIT2_PIN));

Serial.print(", LIMIT3: ");

Serial.println(digitalRead(LIMIT3_PIN));

// Khởi tạo EEPROM

bool needsInit = true;

for (int i = 0; i < EEPROM_SIZE; i++) {

if (EEPROM.read(i) != 0xFF) {

needsInit = false;

break;

}

}

if (needsInit) {

Position empty = {0, 0, 0, 0};

Trang 63

for (int i = 0; i < MAX_POSITIONS; i++) {

EEPROM.put(i * sizeof(Position), empty);

}

EEPROM.commit();

}

// Đọc dữ liệu từ EEPROM

for (int i = 0; i < MAX_POSITIONS; i++) {

EEPROM.get(i * sizeof(Position), positions[i]);

if (positions[i].pos1 == 0 && positions[i].pos2 == 0 && positions[i].pos3 == 0 &&

positions[i].relayFlags == 0) {

posCount = i;

break;

}

}

Serial.printf(" Đã nạp %d vị trí từ EEPROM\n", posCount);

stepper1.setMaxSpeed(HOMING_SPEED); stepper1.setAcceleration(200);

stepper2.setMaxSpeed(HOMING_SPEED); stepper2.setAcceleration(200);

stepper3.setMaxSpeed(HOMING_SPEED); stepper3.setAcceleration(200);

Serial.println("[HOMING] Đang bắt đầu về góc...");

}

void loop() {

handleButtons();

if (restartRequested) {

restartMotors();

restartRequested = false;

}

if (homing1 != DONE || homing2 != DONE || homing3 != DONE) {

Trang 64

homingLoop();

return;

}

if (!printedInitialPrompt) {

Serial.println(" Nhập bước cho động cơ 1 (chỉ sau khi homing hoàn tất):");

printedInitialPrompt = true;

}

if (!playFinished && posCount >= 2) {

Serial.printf(" Đã lưu %d vị trí. Bạn có muốn chạy tự động không? (gõ 'play')\n", posCount);

playFinished = true;

}

while (Serial.available()) {

char c = Serial.read();

if (c == '\n' || c == '\r') {

input.trim();

input.toLowerCase();

if (input.length() > 0) handleInput(input);

input = "";

} else {

input += c;

}

}

}

void handleButtons() {

// --------- Nút 1 ----------

int reading1 = digitalRead(BUTTON1_PIN);

if (reading1 != lastReading1) {

lastDebounceTime1 = millis();

}

Trang 65

if ((millis() - lastDebounceTime1) > debounceDelay) {

if (reading1 != lastStableState1) {

lastStableState1 = reading1;

if (lastStableState1 == HIGH) {

relayToggleCount1++;

if (relayToggleCount1 == 1) {

if (!relay1_enabled) {

relay1_enabled = true;

digitalWrite(RELAY1_PIN, HIGH);

currentRelayFlags |= 1;

Serial.println(" Nút 1: BẬT relay 1");

}

} else if (relayToggleCount1 == 2) {

relay1_enabled = false;

digitalWrite(RELAY1_PIN, LOW);

currentRelayFlags &= ~1;

Serial.println(" Nút 1: TẮT relay 1 (nhấn 2 lần)");

if (posCount > 0 && step == 5) {

Serial.printf(" Vị trí %d: %d - %d - %d | Relay: %s %s đã tắt\n",

posCount, lastVal1, lastVal2, lastVal3,

(currentRelayFlags & 1) ? "R1" : "",

(currentRelayFlags & 2) ? "R2" : "");

}

relayToggleCount1 = 0;

}

}

}

}

lastReading1 = reading1;

// --------- Nút 2 ----------

int reading2 = digitalRead(BUTTON2_PIN);

if (reading2 != lastReading2) {

Trang 66

lastDebounceTime2 = millis();

}

if ((millis() - lastDebounceTime2) > debounceDelay) {

if (reading2 != lastStableState2) {

lastStableState2 = reading2;

if (lastStableState2 == HIGH) {

relayToggleCount2++;

if (relayToggleCount2 == 1) {

if (!relay2_enabled) {

relay2_enabled = true;

digitalWrite(RELAY2_PIN, HIGH);

currentRelayFlags |= 2;

Serial.println(" Nút 2: BẬT relay 2");

}

} else if (relayToggleCount2 == 2) {

relay2_enabled = false;

digitalWrite(RELAY2_PIN, LOW);

currentRelayFlags &= ~2;

Serial.println(" Nút 2: TẮT relay 2 (nhấn 2 lần)");

if (posCount > 0 && step == 5) {

Serial.printf(" Vị trí %d: %d - %d - %d | Relay: %s %s đã tắt\n",

posCount, lastVal1, lastVal2, lastVal3,

(currentRelayFlags & 1) ? "R1" : "",

(currentRelayFlags & 2) ? "R2" : "");

}

relayToggleCount2 = 0;

}

}

}

}

lastReading2 = reading2;

}

Trang 67

void restartMotors() {

Serial.println(" Đang reset động cơ về vị trí homing...");

homing1 = START;

homing2 = START;

homing3 = START;

step = 1; // Reset về bước nhập cho động cơ 1

printedInitialPrompt = false; // Đảm bảo hiển thị lại prompt nhập bước

while (homing1 != DONE || homing2 != DONE || homing3 != DONE) {

homingLoop();

}

Serial.println(" Đã reset động cơ về vị trí homing");

playFinished = false;

}

void homingLoop() {

static unsigned long homingStartTime1 = 0, homingStartTime2 = 0, homingStartTime3 = 0;

// Homing động cơ 1

if (homing1 != DONE) {

if (homing1 == START) {

homingStartTime1 = millis();

stepper1.setMaxSpeed(HOMING_SPEED);

Serial.print("[DEBUG] LIMIT1 ban đầu: ");

Serial.println(digitalRead(LIMIT1_PIN));

if (digitalRead(LIMIT1_PIN) == HIGH) {

stepper1.moveTo(-2000);

Serial.println("[HOMING1] Công tắc đã kích hoạt, di chuyển ra khỏi limit");

} else {

stepper1.moveTo(-20000);

Serial.println("[HOMING1] Bắt đầu di chuyển tới limit");

}

homing1 = MOVING_TO_LIMIT;

Trang 68

} else if (homing1 == MOVING_TO_LIMIT) {

Serial.print("[DEBUG] LIMIT1 hiện tại: ");

Serial.println(digitalRead(LIMIT1_PIN));

if (digitalRead(LIMIT1_PIN) == HIGH || millis() - homingStartTime1 > HOMING_TIMEOUT) {

stepper1.stop();

stepper1.setCurrentPosition(0);

stepper1.setMaxSpeed(HOMING_SPEED);

stepper1.moveTo(65);

homing1 = RETURNING_TO_ORIGIN;

Serial.println("[HOMING1] Đã chạm limit hoặc timeout, quay về vị trí xuất phát");

} else {

stepper1.run();

}

} else if (homing1 == RETURNING_TO_ORIGIN) {

if (stepper1.distanceToGo() == 0) {

stepper1.setCurrentPosition(0);

homing1 = DONE;

Serial.println("[HOMING1] Đã về vị trí xuất phát");

} else {

stepper1.run();

}

}

}

// Homing động cơ 2

if (homing2 != DONE) {

if (homing2 == START) {

homingStartTime2 = millis();

stepper2.setMaxSpeed(HOMING_SPEED);

Serial.print("[DEBUG] LIMIT2 ban đầu: ");

Serial.println(digitalRead(LIMIT2_PIN));

if (digitalRead(LIMIT2_PIN) == HIGH) {

stepper2.moveTo(-2000);

Trang 69

Serial.println("[HOMING2] Công tắc đã kích hoạt, di chuyển ra khỏi limit");

} else {

stepper2.moveTo(-20000);

Serial.println("[HOMING2] Bắt đầu di chuyển tới limit");

}

homing2 = MOVING_TO_LIMIT;

} else if (homing2 == MOVING_TO_LIMIT) {

Serial.print("[DEBUG] LIMIT2 hiện tại: ");

Serial.println(digitalRead(LIMIT2_PIN));

if (digitalRead(LIMIT2_PIN) == HIGH || millis() - homingStartTime2 > HOMING_TIMEOUT) {

stepper2.stop();

stepper2.setCurrentPosition(0);

stepper2.setMaxSpeed(HOMING_SPEED);

stepper2.moveTo(500);

homing2 = RETURNING_TO_ORIGIN;

Serial.println("[HOMING2] Đã chạm limit hoặc timeout, quay về vị trí xuất phát");

} else {

stepper2.run();

}

} else if (homing2 == RETURNING_TO_ORIGIN) {

if (stepper2.distanceToGo() == 0) {

stepper2.setCurrentPosition(0);

homing2 = DONE;

Serial.println("[HOMING2] Đã về vị trí xuất phát");

} else {

stepper2.run();

}

}

}

// Homing động cơ 3

if (homing3 != DONE) {

if (homing3 == START) {

Trang 70

homingStartTime3 = millis();

stepper3.setMaxSpeed(HOMING_SPEED);

Serial.print("[DEBUG] LIMIT3 ban đầu: ");

Serial.println(digitalRead(LIMIT3_PIN));

if (digitalRead(LIMIT3_PIN) == HIGH) {

stepper3.moveTo(-2000);

Serial.println("[HOMING3] Công tắc đã kích hoạt, di chuyển ra khỏi limit");

} else {

stepper3.moveTo(20000);

Serial.println("[HOMING3] Bắt đầu di chuyển tới limit");

}

homing3 = MOVING_TO_LIMIT;

} else if (homing3 == MOVING_TO_LIMIT) {

Serial.print("[DEBUG] LIMIT3 hiện tại: ");

Serial.println(digitalRead(LIMIT3_PIN));

if (digitalRead(LIMIT3_PIN) == HIGH || millis() - homingStartTime3 > HOMING_TIMEOUT) {

stepper3.stop();

stepper3.setCurrentPosition(0);

stepper3.setMaxSpeed(HOMING_SPEED);

stepper3.moveTo(-120);

homing3 = RETURNING_TO_ORIGIN;

Serial.println("[HOMING3] Đã chạm limit hoặc timeout, quay về vị trí xuất phát");

} else {

stepper3.run();

}

} else if (homing3 == RETURNING_TO_ORIGIN) {

if (stepper3.distanceToGo() == 0) {

stepper3.setCurrentPosition(0);

homing3 = DONE;

Serial.println("[HOMING3] Đã về vị trí xuất phát");

} else {

stepper3.run();

}

Trang 71

}

}

}

void moveAndSave() {

stepper1.moveTo(lastVal1);

stepper2.moveTo(lastVal2);

stepper3.moveTo(-lastVal3); // Đảo chiều động cơ 3

while (stepper1.distanceToGo() != 0 || stepper2.distanceToGo() != 0 || stepper3.distanceToGo() != 0) {

stepper1.run();

stepper2.run();

stepper3.run();

}

Serial.println("\nBạn có muốn lưu vị trí này? (yes / no)");

step = 4;

}

void handleInput(String cmd) {

if (cmd == "restart") {

restartRequested = true;

isPaused = false;

currentPlayIndex = 0;

return;

}

if (cmd == "p" && !isPaused) {

if (currentPlayIndex > 0 || motorsAtPosition) {

isPaused = true;

stepper1.stop();

stepper2.stop();

stepper3.stop();

Serial.println(" Đã tạm dừng tại vị trí hiện tại. Gõ 'play' để tiếp tục.");

return;

Trang 72

}

}

if (cmd == "play") {

if (posCount == 0) {

Serial.println(" Chưa có vị trí nào được lưu!");

return;

}

if (isPaused) {

Serial.println(" Tiếp tục chạy các vị trí đã lưu...");

isPaused = false;

} else {

Serial.println("\n [AUTO] Đang chạy các vị trí đã lưu:");

currentPlayIndex = 0;

}

for (int i = currentPlayIndex; i < posCount; i++) {

Serial.printf(" Vị trí %d: %d - %d - %d | Relay: %s %s\n",

i + 1,

positions[i].pos1,

positions[i].pos2,

positions[i].pos3,

(positions[i].relayFlags & 1) ? "R1" : "",

(positions[i].relayFlags & 2) ? "R2" : "");

stepper1.moveTo(positions[i].pos1);

stepper2.moveTo(positions[i].pos2);

stepper3.moveTo(-positions[i].pos3); // Đảo chiều động cơ 3

motorsAtPosition = false;

while (stepper1.distanceToGo() != 0 || stepper2.distanceToGo() != 0 || stepper3.distanceToGo() != 0)

{

if (isPaused) {

Trang 73

currentPlayIndex = i;

return;

}

// Kiểm tra đầu vào Serial trong khi di chuyển

while (Serial.available()) {

char c = Serial.read();

if (c == '\n' || c == '\r') {

input.trim();

input.toLowerCase();

if (input == "p") {

isPaused = true;

stepper1.stop();

stepper2.stop();

stepper3.stop();

Serial.println(" Đã tạm dừng tại vị trí hiện tại. Gõ 'play' để tiếp tục.");

currentPlayIndex = i;

input = "";

return;

}

input = "";

} else {

input += c;

}

}

stepper1.run();

stepper2.run();

stepper3.run();

}

motorsAtPosition = true;

if (motorsAtPosition) {

relay1_enabled = (positions[i].relayFlags & 1) != 0;

relay2_enabled = (positions[i].relayFlags & 2) != 0;

Trang 74

digitalWrite(RELAY1_PIN, relay1_enabled ? HIGH : LOW);

digitalWrite(RELAY2_PIN, relay2_enabled ? HIGH : LOW);

if (relay1_enabled || relay2_enabled) {

Serial.println(" Động cơ đã đến vị trí, kích hoạt relay...");

}

}

stepper1.setCurrentPosition(positions[i].pos1);

stepper2.setCurrentPosition(positions[i].pos2);

stepper3.setCurrentPosition(-positions[i].pos3); // Đảo chiều động cơ 3

// Kiểm tra đầu vào trong khi delay

unsigned long startDelay = millis();

while (millis() - startDelay < 3000) {

if (Serial.available()) {

char c = Serial.read();

if (c == '\n' || c == '\r') {

input.trim();

input.toLowerCase();

if (input == "p") {

isPaused = true;

Serial.println(" Đã tạm dừng tại vị trí hiện tại. Gõ 'play' để tiếp tục.");

currentPlayIndex = i + 1;

input = "";

return;

}

input = "";

} else {

input += c;

}

}

}

Trang 75

if (isPaused) {

currentPlayIndex = i + 1;

return;

}

}

digitalWrite(RELAY1_PIN, LOW);

digitalWrite(RELAY2_PIN, LOW);

relay1_enabled = false;

relay2_enabled = false;

currentRelayFlags = 0;

motorsAtPosition = false;

isPaused = false;

currentPlayIndex = 0;

lastVal1 = positions[posCount-1].pos1;

lastVal2 = positions[posCount-1].pos2;

lastVal3 = positions[posCount-1].pos3;

Serial.println(" Đã hoàn tất phát lại.");

step = 1;

Serial.println(" Nhập bước cho động cơ 1:");

return;

}

if (cmd == "list") {

if (posCount == 0) {

Serial.println(" Chưa có vị trí nào được lưu!");

} else {

Serial.println("\n Danh sách các vị trí đã lưu:");

for (int i = 0; i < posCount; i++) {

Serial.printf(" Vị trí %d: %d - %d - %d | Relay: %s %s\n",

i + 1,

positions[i].pos1,

positions[i].pos2,

Trang 76

positions[i].pos3,

(positions[i].relayFlags & 1) ? "R1" : "",

(positions[i].relayFlags & 2) ? "R2" : "");

}

Serial.println(" Gõ 'change' để sửa, 'delete' để xóa, hoặc 'no' để quay lại:");

step = 5;

}

return;

}

if (cmd == "clear") {

for (int i = 0; i < MAX_POSITIONS; i++) {

positions[i] = {0, 0, 0, 0};

EEPROM.put(i * sizeof(Position), positions[i]);

}

EEPROM.commit();

posCount = 0;

Serial.println(" | Đã xóa toàn bộ các vị trí đã lưu trong EEPROM.");
Serial.println(" | Nhập bước cho động cơ 1:");

step = 1;

currentRelayFlags = 0;

relay1_enabled = false;

relay2_enabled = false;

digitalWrite(RELAY1_PIN, LOW);

digitalWrite(RELAY2_PIN, LOW);

return;

}

if (step == 5) {

if (cmd == "no") {

step = 1;

commandMode = NONE;

changeStep = 0;

Trang 77

Serial.println(" Nhập bước cho động cơ 1:");

return;

} else if (cmd == "change") {

if (posCount == 0) {

Serial.println(" Chưa có vị trí nào để thay đổi!");

step = 1;

commandMode = NONE;

Serial.println(" Nhập bước cho động cơ 1:");

return;

}

Serial.println(" Bạn muốn thay đổi số bước ở vị trí mấy? (Nhập số thứ tự):");

commandMode = CMD_CHANGE;

changeStep = 1;

return;

} else if (cmd == "delete") {

if (posCount == 0) {

Serial.println(" Chưa có vị trí nào để xóa!");

step = 1;

commandMode = NONE;

Serial.println(" Nhập bước cho động cơ 1:");

return;

}

Serial.println(" Bạn muốn xóa vị trí nào? (Nhập số thứ tự):");

commandMode = CMD_DELETE;

changeStep = 1;

return;

}

if (changeStep == 1) {

selectedPosition = cmd.toInt();

if (selectedPosition >= 1 && selectedPosition <= posCount) {

if (commandMode == CMD_CHANGE) {

Serial.println(" Nhập số bước mới (cú pháp: số bước 1 - số bước 2 - số bước 3):");

Trang 78

changeStep = 2;

} else if (commandMode == CMD_DELETE) {

// Xử lý xóa vị trí

for (int i = selectedPosition - 1; i < posCount - 1; i++) {

positions[i] = positions[i + 1];

EEPROM.put(i * sizeof(Position), positions[i]);

}

positions[posCount - 1] = {0, 0, 0, 0};

EEPROM.put((posCount - 1) * sizeof(Position), positions[posCount - 1]);

EEPROM.commit();

posCount--;

Serial.printf(" Đã xóa vị trí %d.\n", selectedPosition);

step = 1;

changeStep = 0;

commandMode = NONE;

Serial.println(" Nhập bước cho động cơ 1:");

}

} else {

Serial.println(" Số thứ tự không hợp lệ. Nhập lại số hoặc 'no' để quay lại.");

}

return;

} else if (changeStep == 2 && commandMode == CMD_CHANGE) {

// Xử lý thay đổi vị trí

int pos1, pos2, pos3;

if (sscanf(cmd.c_str(), "%d-%d-%d", &pos1, &pos2, &pos3) == 3) {

if (pos3 < 0) {

Serial.println(" Số bước cho động cơ 3 phải là số dương.");

return;

}

positions[selectedPosition - 1] = {pos1, pos2, pos3, positions[selectedPosition - 1].relayFlags};

EEPROM.put((selectedPosition - 1) * sizeof(Position), positions[selectedPosition - 1]);

EEPROM.commit();

Serial.printf(" Đã cập nhật vị trí %d: %d - %d - %d\n", selectedPosition, pos1, pos2, pos3);

Trang 79

step = 1;

changeStep = 0;

commandMode = NONE;

Serial.println(" Nhập bước cho động cơ 1:");

} else {

Serial.println(" Cú pháp không đúng. Vui lòng nhập theo định dạng: số bước 1 - số bước 2 - số

bước 3");

}

return;

}

}

if ((step == 1 || step == 2 || step == 3) && cmd.toInt() == 0 && cmd != "0" && cmd != "next") {

Serial.println(" Vui lòng chỉ nhập **số** (hoặc gõ 'next' để qua bước tiếp theo). Không được nhập

chữ hoặc lệnh tại đây.");

return;

} else if (step == 1) {

if (cmd == "next") {

step = 2;

Serial.println(" Nhập bước cho động cơ 2:");

} else {

lastVal1 = cmd.toInt();

if (lastVal1 != 0 || cmd == "0") {

Serial.printf(" [NHẬP] Đã nhập %d bước cho động cơ 1. Đang xoay...\n", lastVal1);

stepper1.moveTo(lastVal1);

while (stepper1.distanceToGo() != 0) stepper1.run();

stepper1.setCurrentPosition(lastVal1);

Serial.println(" | [XONG] Động cơ 1 đã xoay xong.\n | Nhập bước mới hoặc gõ 'next' để

chuyển:");

} else {

Serial.println(" Vui lòng nhập số hợp lệ cho động cơ 1.");

}

}

Trang 80

} else if (step == 2) {

if (cmd == "next") {

step = 3;

Serial.println(" Nhập bước cho động cơ 3 (chỉ nhập số dương, nhập nhiều lần để thử, gõ 'next' khi

ưng ý):");

} else {

lastVal2 = cmd.toInt();

if (lastVal2 != 0 || cmd == "0") {

Serial.printf(" [NHẬP] Đã nhập %d bước cho động cơ 2. Đang xoay...\n", lastVal2);

stepper2.moveTo(lastVal2);

while (stepper2.distanceToGo() != 0) stepper2.run();

stepper2.setCurrentPosition(lastVal2);

Serial.println(" | [XONG] Động cơ 2 đã xoay xong.\n | Nhập bước mới hoặc gõ 'next' để

chuyển:");

} else {

Serial.println(" Vui lòng nhập số hợp lệ cho động cơ 2.");

}

}

} else if (step == 3) {

if (cmd == "next") {

Serial.println(" Đã xác nhận vị trí động cơ 3.");

step = 4;

Serial.println(" Bạn có muốn lưu vị trí này? (yes/no):");

} else {

int inputVal = cmd.toInt();

if (inputVal < 0) {

Serial.println(" Vui lòng chỉ nhập số dương cho động cơ 3.");

return;

}

lastVal3 = inputVal;

Serial.printf(" [NHẬP] Đã nhập %d bước cho động cơ 3. Đang xoay...\n", lastVal3);

stepper3.moveTo(-lastVal3); // Đảo chiều động cơ 3

while (stepper3.distanceToGo() != 0) stepper3.run();

Trang 81

stepper3.setCurrentPosition(-lastVal3); // Đảo chiều động cơ 3

Serial.println(" | [XONG] Động cơ 3 đã xoay xong.\n | Nhập bước mới hoặc gõ 'next' để xác

nhận:");

}

} else if (step == 4 && cmd == "yes") {

if (lastVal1 == 0 && lastVal2 == 0 && lastVal3 == 0) {

Serial.println(" Vị trí không hợp lệ, vui lòng nhập lại từ bước 1.");

step = 1;

Serial.println(" Nhập bước cho động cơ 1:");

return;

}

stepper1.setCurrentPosition(lastVal1);

stepper2.setCurrentPosition(lastVal2);

stepper3.setCurrentPosition(-lastVal3); // Đảo chiều động cơ 3

if (posCount < MAX_POSITIONS) {

positions[posCount] = {lastVal1, lastVal2, lastVal3, currentRelayFlags};

EEPROM.put(posCount * sizeof(Position), positions[posCount]);

EEPROM.commit();

Serial.println(" Đã lưu vị trí.");

if (currentRelayFlags != 0) {

Serial.print(" Đã ghi nhớ trạng thái relay tại vị trí này: ");

if (currentRelayFlags & 1) Serial.print("R1 ");

if (currentRelayFlags & 2) Serial.print("R2 ");

Serial.println();

}

posCount++;

playFinished = false;

} else {

Serial.println(" EEPROM đã đầy, không thể lưu thêm.");

}

step = 1;

Trang 82

currentRelayFlags = 0;

relay1_enabled = false;

relay2_enabled = false;

digitalWrite(RELAY1_PIN, LOW);

digitalWrite(RELAY2_PIN, LOW);

Serial.println(" Nhập bước cho động cơ 1:");

} else if (step == 4 && cmd == "no") {

step = 1;

currentRelayFlags = 0;

relay1_enabled = false;

relay2_enabled = false;

digitalWrite(RELAY1_PIN, LOW);

digitalWrite(RELAY2_PIN, LOW);

Serial.println(" Nhập bước cho động cơ 1:");

}

}

Trang 83

CHƯƠNG 5: KẾT LUẬN VÀ ĐÁNH GIÁ

### 5.1. Kết luận

- Tiêu chí đề tài đặt ra là nhấc vật được 100 gram đã thỏa.

### 5.2. Ưu điểm

- Cấu trúc đơn giản, dễ thiết kế
- Chi phí thấp
- Dễ điều khiển
- Mô hình đơn giản có thể in 3D, lắp ráp thủ công nhanh, dễ thiết kế và nghiên cứu trong

quá trình làm đồ án. Vì còn là sinh viên nên tiêu chí chi phí thấp luôn được cân nhắc hàng

đầu. ESP32 là một dạng vi điều khiển của Arduino nên thư viện khá phổ biến và rộng rãi

giúp cho việc tham khảo các nguồn trên website dễ dàng.

### 5.3. Nhược điểm

- Độ chính xác và tải trọng thấp
- Giới hạn về không gian hoạt động vì mục tiêu đề tài là gấp vật nằm ở mặt phẳng song

song với mặt đất nên việc sử dụng khớp bị động đã làm cho cánh tay trở nên ít linh hoạt

hơn sơ với cánh tay công nghiệp.

- Không thích hợp cho công việc phức tạp
- Bị rung lắc trong quá trình sử dụng

### 5.4. Đề xuất cải tiến

- Tăng độ linh hoạt, cho phép điều chỉnh hướng của đầu gắp (end-effector)
- Cải thiện độ chính xác và ổn định, tránh mất bước (đối với stepper)
- Tăng độ bền và tải trọng làm việc
- Tăng tính thông minh, dễ dùng, linh hoạt cho người dùng

### 5.5. Tổng kết

- Những hình ảnh thực tế sau khi in 3D và thiết kế mạch điện trên máy. Em đã hàn mạch

để giúp việc di chuyển không bị bung dây về sau.

Trang 84

- Trong quá trình nghiên cứu có những khó khăn trong việc tìm hiểu về cánh tay robot 4

bậc tự do nhưng từ đó cũng giúp em có thêm được nhiều kiến thức mới và kinh nghiệm

để thực hiện những đồ án tiếp theo.

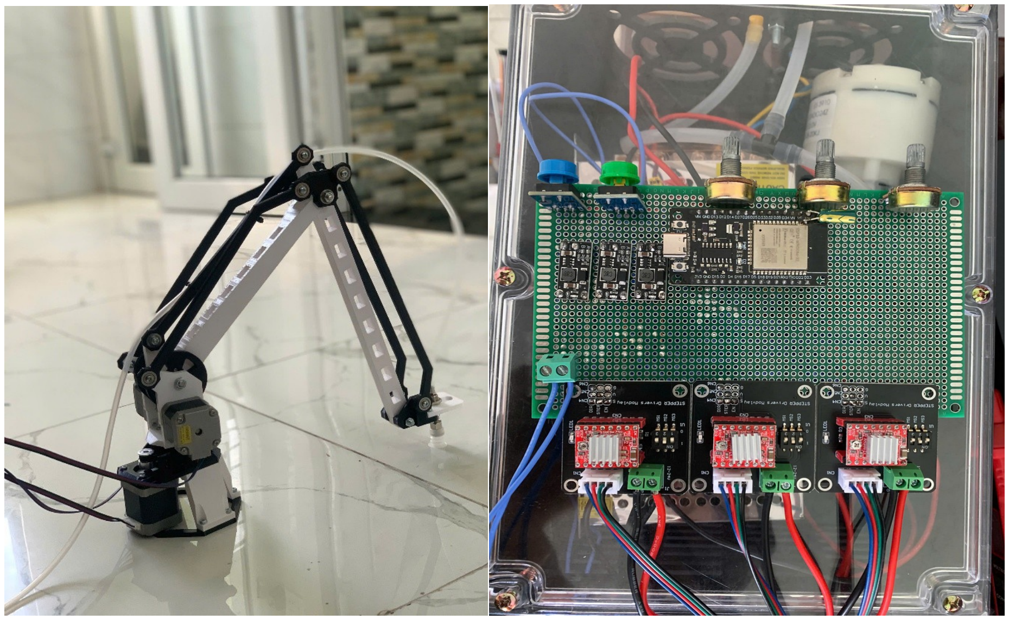
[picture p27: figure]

Hình 5-1. Kết quả cánh tay và mạch trong quá trình nghiên cứu

Trang 85

CHƯƠNG 6: TÀI LIỆU THAM KHẢO

Tiếng Việt

Nguyễn Tiến Khiêm. (2013). Giáo trình Sức bền vật liệu. NXB Giáo dục

Bùi Trọng Tín. (2018). Cơ học vật rắn biến dạng. NXB Giáo dục

MatWeb. (1996). PETG Copolyester.(11/7/2025),

https://www.matweb.com/search/datasheet.aspx?

MatGUID=4de1c85bb946406a86c52b688e3810d0&ckck=1. (https://www.matweb.com/search/datasheet.aspx?MatGUID=4de1c85bb946406a86c52b688e3810d0&ckck=1)

Nguyễn Bính. (1995). Giáo trình Truyền động điện NXB Khoa học và Kỹ thuật

Tiếng Anh

Principia Mathematica – Isaac Newton (1687), khái niệm này nằm ở Quyển I (Book I),

phần đầu tiên giải thích mối quan hệ giữa lực và gia tốc, từ đó suy ra lực hấp dẫn

(gravity)

Douglas W. Jones – Control of Stepper Motors (1995)

Beer, Ferdinand P., Johnston Jr., E. Russell – Mechanics of Materials, McGraw-Hill,

University of Iowa

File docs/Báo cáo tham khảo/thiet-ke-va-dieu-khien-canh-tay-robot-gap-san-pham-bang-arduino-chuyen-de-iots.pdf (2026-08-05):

Nhóm 1 Thiết kế và điều khiển cánh tay robot bằng adruino (https://www.studocu.vn/vn/document/truong-dai-hoc-duy-tan/tieng-anh-on-dau-ra-eng-este/thiet-ke-va-dieu-khien-canh-tay-robot-gap-san-pham-bang-arduino-chuyen-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)

Tiếng anh ôn đầu ra ENG ESTE (Trường Đại Học Duy Tân) (https://www.studocu.vn/vn/course/truong-dai-hoc-duy-tan/tieng-anh-on-dau-ra-eng-este/6397653)

messages.pdf_cover_qr_code_label

messages.studocu_not_sponsored_or_endorsed_by_college messages.downloaded_by

lOMoARcPSD|60016464

ỦY BAN NHÂN DÂN TP. HỒ CHÍ MINH

TRƯỜNG ĐẠI HỌC THỦ DẦU MỘT


Báo cáo môn học: CHUYÊN ĐỀ INTERNET OF THINGS (IoTs)

### Tên đề tài

## Thiết kế và điều khiển cánh tay Robot gắp sản phẩm bằng

## Adruino

SVTH: | TRẦN THANH ĐỒNG | - MSSV: 2395202010006
| HUỲNH NGUYỄN HOÀNG TRUNG | - MSSV: 2395202010024
GVHD: | ThS. NGÔ THANH ĐÔNG

TP.HCM, tháng 09 năm 2025

Tên đề tài: Thiết kế cánh tay Robot gắp sản phẩm sử dụng Adruino

2

MỤC LỤC

Tên đề tài: Thiết kế cánh tay Robot gắp sản phẩm sử dụng Adruino

3

Tên đề tài: Thiết kế cánh tay Robot gắp sản phẩm sử dụng Adruino

4

DANH MỤC CÁC HÌNH

Tên đề tài: Thiết kế cánh tay Robot gắp sản phẩm sử dụng Adruino

5

DANH MỤC CÁC BẢNG

Tên đề tài: Thiết kế cánh tay Robot gắp sản phẩm sử dụng Adruino

6

CHƯƠNG 1. GIỚI THIỆU ĐỀ TÀI

1.1. 1. Lý do chọn đề tài

Trong thời đại công nghiệp 4.0, tự động hóa và robot ngày càng đóng vai trò quan trọng trong sản xuất và đời sống. Robot công nghiệp, đặc biệt là cánh tay robot gắp

sản phẩm, được ứng dụng rộng rãi trong dây chuyền sản xuất, lắp ráp và phân loại

sản phẩm nhằm:

- Tăng năng suất lao động.
- Giảm thiểu rủi ro cho con người trong môi trường nguy hiểm.
- Đảm bảo độ chính xác và ổn định trong thao tác lặp đi lặp lại.
- Trong sản xuất hiện đại, robot là công cụ quan trọng vì chúng làm việc nhanh,

chính xác và không biết mệt mỏi.

- Đặc biệt, cánh tay robot gắp sản phẩm có thể thay thế con người trong việc

lặp lại thao tác đơn giản, nhưng cần chính xác (ví dụ: gắp linh kiện, sắp xếp

sản phẩm).

- Do đó, chọn thiết kế mô hình nhỏ gọn, giá rẻ, dễ làm dựa trên Arduino (nền

tảng lập trình mở, dễ học, phổ biến).

Tuy nhiên, robot công nghiệp chuyên dụng thường có giá thành cao, khó tiếp cận đối

với sinh viên và các mô hình nghiên cứu nhỏ. Vì vậy, thiết kế và chế tạo một cánh tay

robot đơn giản, sử dụng nền tảng mở Arduino là một hướng đi phù hợp để vừa tiết

kiệm chi phí, vừa tạo điều kiện cho sinh viên rèn luyện kỹ năng thiết kế – lập trình –

điều khiển.

1.2. 2. Mục tiêu của đề tài
- Thiết kế và chế tạo mô hình cánh tay robot 3–4 bậc tự do có khả năng gắp, di

chuyển và thả sản phẩm.

Tên đề tài: Thiết kế cánh tay Robot gắp sản phẩm sử dụng Adruino

7

- Sử dụng Arduino làm bộ điều khiển trung tâm để xử lý và điều khiển các động

cơ servo.
- Xây dựng chương trình điều khiển với 2 chế độ:
- Thủ công (joystick, nút nhấn).
- Tự động (chu trình gắp – di chuyển – thả sản phẩm được lập trình sẵn).
- Ứng dụng trong các bài thí nghiệm, mô phỏng quy trình sản xuất và học tập

về robot.

1.3. 3. Ý nghĩa khoa học và thực tiễn
- Ý nghĩa khoa học: Đề tài giúp sinh viên làm quen với các khái niệm về robot

học, điều khiển servo, kinematics cơ bản và lập trình nhúng, phát triển sang

robot có AI, IoT, thị giác máy.
- Ý nghĩa thực tiễn:
- Mô hình mô phỏng một dây chuyền sản xuất tự động thu nhỏ.
- Tạo tiền đề cho việc phát triển nền tảng nghiên cứu nếu muốn phát triển sang

robot có AI, IoT, thị giác máy.

Tên đề tài: Thiết kế cánh tay Robot gắp sản phẩm sử dụng Adruino

8

Chương 2. TỔNG QUAN ĐỀ TÀI

### 2.1. Tổng quan đề tài

### 2.1.1. Cơ sở lý thuyết về robot và cánh tay robot

Robot công nghiệp: Là thiết bị tự động có khả năng lập trình, thực hiện nhiều nhiệm

vụ khác nhau như hàn, lắp ráp, sơn, vận chuyển, gắp – thả sản phẩm.

Cánh tay robot (Robotic Arm): Mô phỏng cánh tay con người, gồm nhiều khớp

(bậc tự do – DOF), cho phép thực hiện các chuyển động linh hoạt. Các bậc tự do càng

nhiều thì robot càng phức tạp và có thể thực hiện nhiều thao tác hơn.

Nguyên lý điều khiển: Thường sử dụng động cơ điện (servo, step motor, DC motor).

Arduino hoặc PLC là bộ điều khiển trung tâm, nhận lệnh từ người dùng (nút nhấn,

joystick, máy tính) hoặc từ chương trình cài đặt sẵn để điều khiển chuyển động robot.

### 2.1.2. Tình hình nghiên cứu và ứng dụng

Trên thế giới: Các hãng lớn như ABB, KUKA, Yaskawa, FANUC… đã phát triển

robot công nghiệp 6–7 bậc tự do có khả năng hàn, lắp ráp, sơn, bốc dỡ hàng hóa. Đây

là các robot thương mại với độ chính xác cao, tốc độ nhanh nhưng giá thành rất đắt.

Ở Việt Nam: Một số trường đại học, viện nghiên cứu và doanh nghiệp đang chế tạo

robot mô hình hoặc robot gắp sản phẩm phục vụ đào tạo. Tuy nhiên, đa phần là quy

mô nhỏ, dùng cho giảng dạy và nghiên cứu, chưa phổ biến trong công nghiệp thực tế.

Xu hướng hiện nay: Ứng dụng nền tảng mở (Arduino, Raspberry Pi) kết hợp với công

nghệ IoT, AI, thị giác máy để tạo ra các robot thông minh, chi phí thấp, phù hợp cho

đào tạo và thí nghiệm.

### 2.1.3. Ưu điểm – hạn chế của cánh tay robot Arduino

Ưu điểm:

Tên đề tài: Thiết kế cánh tay Robot gắp sản phẩm sử dụng Adruino

9

- Chi phí thấp, dễ chế tạo.
- Dễ học, dễ lập trình nhờ Arduino IDE.
- Nghiên cứu cơ bản.

Hạn chế:

- Độ chính xác và độ bền không cao.
- Phù hợp cho mô hình thí nghiệm

Lý do lựa chọn hướng nghiên cứu

- Xuất phát từ nhu cầu học tập và nghiên cứu của sinh viên ngành điện – điện

tử – cơ điện tử.
- Tận dụng nền tảng Arduino phổ biến, giúp dễ dàng tiếp cận và mở rộng.
- Mô hình có tính thực tiễn cao, phục vụ thí nghiệm, mô phỏng sản xuất tự động.
- Robot gắp sản phẩm là hướng nghiên cứu quan trọng và có ứng dụng thực tế

rộng rãi.
- Arduino là nền tảng phù hợp để chế tạo mô hình robot giá rẻ, dễ tiếp cận .

### 2.2. Nội dung thực hiện

### 2.2.1. Nghiên cứu tài liệu và lý thuyết

Khái niệm về robot, cánh tay robot

Robot là thiết bị tự động, có khả năng lập trình để thực hiện các thao tác lặp đi lặp lại

thay cho con người.

Cánh tay robot là một dạng robot công nghiệp mô phỏng cấu trúc và chuyển động

của tay người, có nhiều bậc tự do (DOF), giúp thực hiện các công việc như gắp, di

chuyển, lắp ráp sản phẩm.

Ứng dụng phổ biến: trong dây chuyền sản xuất ô tô, điện tử, bao gói, phân loại sản

phẩm, và các công việc nguy hiểm như hàn, sơn, làm việc trong môi trường độc hại.

Tên đề tài: Thiết kế cánh tay Robot gắp sản phẩm sử dụng Adruino


10

### 2.2.2. Nguyên lý hoạt động của động cơ servo, Arduino

- Động cơ servo: là động cơ có khả năng quay một góc xác định (0°–180° hoặc 0°–360°) nhờ tín hiệu điều khiển xung PWM. Thường dùng để điều khiển

khớp quay trong robot.
- Arduino: nền tảng vi điều khiển mã nguồn mở, dễ lập trình bằng Arduino IDE.

Arduino có các chân PWM để xuất tín hiệu điều khiển servo, đồng thời có thể

nhận tín hiệu từ joystick, nút nhấn.

- Arduino được chọn vì chi phí thấp, dễ lập trình, cộng đồng hỗ trợ rộng rãi.

Hình 1 Kết nối servo với arduino

### 2.2.3. Phương pháp điều khiển cơ bản (thủ công, tự động)

- Điều khiển thủ công: trực tiếp điều khiển robot thông qua joystick hoặc nút

nhấn → Arduino đọc tín hiệu và điều chỉnh góc quay servo theo thao tác.

- Điều khiển tự động: robot thực hiện các chu trình gắp – di chuyển – thả sản

phẩm được lập trình sẵn trong Arduino.

Tên đề tài: Thiết kế cánh tay Robot gắp sản phẩm sử dụng Adruino


11

### 2.2.4. Phân tích và lựa chọn giải pháp thiết kế

- Số bậc tự do của robot (3–4 DOF)
- Số khớp chuyển động độc lập của robot.
- Mục tiêu mô phỏng thao tác gắp – di chuyển – thả sản phẩm, robot cần tối

thiểu 3 bậc tự do:

- Đế xoay (quay trái – phải).
- Khớp nâng/hạ (điều chỉnh độ cao).
- Khớp gắp (mở – đóng kẹp).

Hình 2 Các khớp cánh tay robot

Chọn loại động cơ servo phù hợp:

- Mô-men xoắn đủ để nâng cánh tay và vật gắp.
- Kích thước nhỏ gọn, phù hợp với mô hình.
- Góc quay phù hợp (0°–180° cho khớp, 0°–360° cho đế xoay).

Đề xuất:

Động cơ DC giảm tốc JGB37-520 : dùng cho khớp gắp (nhỏ, nhẹ).

Tên đề tài: Thiết kế cánh tay Robot gắp sản phẩm sử dụng Adruino


12

Hình 3 Động cơ DC giảm tốc JGB37-520

Servo Động Cơ DC Servo JGB37-520 dùng cho khớp nâng/hạ, đế xoay (mô-men

xoắn lớn hơn).

Hình 4 Động Cơ DC Servo JGB37-520

Lựa chọn vật liệu chế tạo khung

Mica: dễ gia công, giá rẻ, trọng lượng nhẹ.

Nhựa in 3D (PLA, ABS): cho phép chế tạo chi tiết chính xác, hình dạng linh hoạt.

Kim loại mỏng (nhôm, thép nhẹ): bền chắc hơn, phù hợp làm đế hoặc trục chính.

Kết hợp: đế bằng kim loại mỏng để vững chắc, các bộ phận tay bằng mica hoặc nhựa

in 3D để giảm trọng lượng.

Tên đề tài: Thiết kế cánh tay Robot gắp sản phẩm sử dụng Adruino

13

Đề xuất sơ đồ khối hệ thống điều khiển

Arduino (bộ điều khiển trung tâm): xử lý tín hiệu và phát xung PWM cho servo.

Joystick / Nút nhấn: thiết bị nhập lệnh điều khiển thủ công.

Servo: cơ cấu chấp hành, điều khiển các khớp robot.

Nguồn điện DC: cấp nguồn cho servo và Arduino.

### 2.2.5. Thiết kế mạch điều khiển

Lập sơ đồ nguyên lý kết nối: Esp 32, servo, joystick, nút nhấn, nguồn.

Lắp đặt mạch điều khiển trên breadboard hoặc PCB nhỏ gọn.

Kiểm tra khả năng cấp nguồn và tín hiệu điều khiển PWM.

### 2.2.6. Lập trình ESP 32

- Viết chương trình điều khiển chế độ thủ công: đọc tín hiệu joystick, nút nhấn

→ điều khiển góc quay servo.

- Viết chương trình điều khiển chế độ tự động: lập trình sẵn chuỗi thao tác gắp

– di chuyển – thả.

- Tối ưu chương trình để robot hoạt động mượt và ổn định.
2.2.7. Thiết kế cơ khí

Tên đề tài: Thiết kế cánh tay Robot gắp sản phẩm sử dụng Adruino


14

Bảng 1 Các cấu tạo linh kiện cơ khí

Số thứ tự | Tên | Hình ảnh | Thông số
1 | Puly 20 răng trục 5mm | | - Chiều dài: 16mm. - Cân nặng: 5g. - Đường kính đầu vào: 5mm. - Đường kính đầu ra: 5mm. - Số răng: 20 răng.
2 | Puly đôi 80 răng trục 5mm | | - Số răng: 80 răng. - Cân nặng: 10g. - Bản rộng: 6mm. - Đường kính đầu vào: 5mm. - Đường kính đầu ra: 5mm.
3 | Ròng rọc trơn trục 5mm | | - Loại: ròng rọc trơn. - Bề rộng rãnh đai: 6.5mm. - Đường kính lỗ trục: 5mm.
4 | Gối đỡ vòng bi bạc đạn KLF06 | | - Chất liệu: hợp kim. - Khối lượng: 30g. - Trục vòng bi: 8mm.

Tên đề tài: Thiết kế cánh tay Robot gắp sản phẩm sử dụng Adruino


15

5 | Con trượt tròn LM8UU | - Chất liệu: kim loại. - Màu sắc: màu kim loại. - Đường kính: 15mm. - Chiều dài: 24mm. - Dành cho trục: 8mm. - Khối lượng: 13.1g.
6 | Puly GT2 80 răng | - Số răng: 80 răng. - Bề rộng đai: 6mm. - Đường kính ngoài: 54mm. - Đường kính bánh răng: 50.5mm. - Bước ren: 2mm. - Chiều cao: 20mm. - Chất liệu: nhôm.
7 | Dây đai GT2 300 | - Bước răng: 2mm. - Chiều rộng đai:6mm.
8 | Bạc đạn 6087 | - Đường kính trong: 10 mm. - Đường kính ngoài: 26mm. - Độ dày: 8mm. - Khối lượng: 0.019 kg.
9 | Mặt bích trục 8mm | - Vật liệu: Thép. - Kích thước lỗ trục bên trong: 8mm. - Đường kính ngoài: 16mm, 32mm. - Tổng chiều cao: 13mm. - Kích thước vít: M4.

Tên đề tài: Thiết kế cánh tay Robot gắp sản phẩm sử dụng Adruino


16

2.2.8. Thử nghiệm và hiệu chỉnh

Hình 5 Mô phỏng

- Thử nghiệm robot ở chế độ thủ công và tự động.
- Quan sát hoạt động: tốc độ, độ chính xác, độ ổn định.
- Điều chỉnh phần mềm và cơ khí nếu phát hiện lỗi.

### 2.2.9. Đánh giá kết quả và hướng phát triển

- Đánh giá ưu điểm: chi phí thấp, dễ chế tạo.
- Chỉ ra hạn chế: tải trọng thấp, độ chính xác chưa cao, chưa có AI
- Phát triển: thêm bậc tự do, tích hợp cảm biến, IoT, thị giác máy tính.

Tên đề tài: Thiết kế cánh tay Robot gắp sản phẩm sử dụng Adruino

17

Chương 3. THIẾT KẾ VÀ THI CÔNG

### 3.1.1. Thiết kế hệ thống

Mục tiêu thiết kế: xây dựng một cánh tay robot có khả năng xoay đế, nâng hạ cánh

tay và gắp sản phẩm, điều khiển thông qua Arduino và các thiết bị ngoại vi (joystick,

nút nhấn).

Sơ đồ khối tổng thể:

Nguồn cấp điện → Arduino Uno → Servo Động Cơ DC Servo JGB37-520 → Cơ cấu

cơ khí (đế, khớp, kẹp gắp).

Thiết bị điều khiển: Joystick/Nút nhấn → Arduino.

Sơ đồ khối minh họa:

[ Nguồn 5V/12V ] → [ Arduino Uno ] → [ Servo 1 (Đế xoay) ]

→ [ Servo 2 (Khớp nâng/hạ) ]

→ [ Servo 3 (Kẹp gắp) ]

[ Joystick / Nút nhấn ] → [ Arduino Uno ]

### 3.1.2. Thiết kế cơ khí

Cấu trúc chính:

Đế xoay: giữ ổn định robot, cho phép xoay 180°–270°.

Khớp nâng/hạ: thay đổi chiều cao tay gắp.

Khớp gắp: cơ cấu kẹp mở/đóng để gắp vật nhỏ.

Vật liệu: mica trong suốt 3–5mm, nhựa in 3D, hoặc kim loại mỏng (tùy khả năng gia

công).

Tên đề tài: Thiết kế cánh tay Robot gắp sản phẩm sử dụng Adruino


18

### 3.1.3. Thiết kế điện – điều khiển

Bộ điều khiển trung tâm: Arduino Uno R3.

Cơ cấu chấp hành:

Động cơ DC giảm tốc JGB37-520 (2kg.cm) cho khớp chính (nâng/hạ).

Servo Động Cơ DC Servo JGB37-520 cho các khớp nhẹ (xoay đế, kẹp gắp).

Thiết bị điều khiển: Joystick module + nút nhấn để điều khiển thao tác thủ công.

Nguồn cấp: 5V–12V, dòng tối thiểu 2A (tùy số lượng servo).

Hình 6 Điều khiển các khớp

Tên đề tài: Thiết kế cánh tay Robot gắp sản phẩm sử dụng Adruino

19

### 3.1.4. Thi công mô hình

- Gia công – lắp ráp cơ khí:
- Cắt/gia công mica theo thiết kế CAD.
- Gắn các servo vào khung theo đúng vị trí thiết kế.
- Lắp ráp các khớp nối với vít và bu-lông nhỏ.
- Lắp ráp mạch điện:
- Kết nối Arduino với các servo (chân PWM).
- Kết nối joystick và nút nhấn vào Arduino (chân analog/digital).
- Kiểm tra nguồn cấp ổn định.
- Lập trình và chạy thử nghiệm:
- Lập trình Arduino bằng IDE để điều khiển servo theo tín hiệu joystick/nút

nhấn.

- Kiểm tra các khớp di chuyển đúng hướng, điều chỉnh giới hạn góc xoay để

tránh va chạm.
- Thử nghiệm gắp vật có khối lượng nhỏ (bóng nhựa, khối gỗ nhẹ).

Tên đề tài: Thiết kế cánh tay Robot gắp sản phẩm sử dụng Adruino


20

Hình 7 Mô hình thử nghiệm

Tên đề tài: Thiết kế cánh tay Robot gắp sản phẩm sử dụng Adruino


21

Chương 4. KẾT QUẢ THỰC HIỆN

### 4.1. Tạo Firebase Project

- Truy cập Firebase và đăng nhập bằng tài khoản Google.
- Vào Firebase Console và tạo một dự án mới.

Hình 8 Firebase Project
- Đặt tên cho dự án, ví dụ: ESP32-IoTs-TDMU, sau đó nhấn Continue.
- Tiếp theo, bật hoặc tắt trợ lý AI (AI assistance) cho dự án của bạn. Tùy chọn

này không bắt buộc. Sau đó nhấn Continue.

Tên đề tài: Thiết kế cánh tay Robot gắp sản phẩm sử dụng Adruino


22

Hình 9 Chọn trợ lý trong Firebase Project

- Tắt tùy chọn "Enable Google Analytics for this project" vì dự án này không

cần đến phân tích dữ liệu. Sau đó nhấn Tạo dự án (Create project).

Tên đề tài: Thiết kế cánh tay Robot gắp sản phẩm sử dụng Adruino


23

Hình 10 Tạo dự án (Create project)

- Quá trình khởi tạo dự án sẽ mất vài giây. Khi hoàn tất, nhấn Continue.


Tên đề tài: Thiết kế cánh tay Robot gắp sản phẩm sử dụng Adruino

24

Hình 11 Quá trình khởi tạo dự án

- Chuyển đến trang điều khiển (console) của dự án.

Tên đề tài: Thiết kế cánh tay Robot gắp sản phẩm sử dụng Adruino


25

Hình 12 Điều khiển (console)

- Ở thanh bên trái, nhấp vào Realtime Database, sau đó nhấp vào Create

Database (Tạo cơ sở dữ liệu).

Hình 13 Create Database (Tạo cơ sở dữ liệu).

- Chọn vị trí địa lý cho cơ sở dữ liệu của bạn. Nên chọn vị trí gần nơi bạn đang

sinh sống nhất để có tốc độ truy cập tốt hơn.


Tên đề tài: Thiết kế cánh tay Robot gắp sản phẩm sử dụng Adruino

26

Hình 14 Thiết lập vị trí cho Realtime Database

Hình 15 Đường dẫn các note của dữ liệu

Thẻ Data là đường dẫn các note của dữ liệu


Tên đề tài: Thiết kế cánh tay Robot gắp sản phẩm sử dụng Adruino

27

Bây giờ, chúng ta sẽ tạo các node cơ sở dữ liệu. Bạn có thể tạo thủ công trực tiếp trên

Firebase Console, qua ứng dụng web, hoặc từ ESP32. Trong hướng dẫn này, ta sẽ tạo

thủ công trên Firebase Console để dễ theo dõi.

Hình 16 Firebase Console để dễ theo dõi

Bước 2: Bạn có thể dùng biểu tượng dấu (+) trong Firebase để tạo node. Tuy nhiên,

để tránh gõ sai, bạn có thể tải một tệp JSON có sẵn mà chúng tôi cung cấp để tạo các

node giống hướng dẫn.

Hình 17 Firebase để tạo node

Tên đề tài: Thiết kế cánh tay Robot gắp sản phẩm sử dụng Adruino


28

Bước 3: Quay lại Firebase Console > Realtime Database. Nhấn vào biểu tượng ba

dấu chấm ở góc phải, chọn Import JSON.

Bước 4: Chọn tệp .json bạn vừa tải xuống.

Bước 5: Sau khi import, cơ sở dữ liệu của bạn sẽ có cấu trúc như hình dưới (giống

như đoạn JSON ở trên).

### 4.2. Chương trình ESP32 nút nhấn điều khiển LED

Hình 18 Bo mạch esp 32

Bảng 2 Bo mạch module ESP32-WROOM-32

Pin | Pin Label | GPIO | Reason
4 | SENSOR_VP | GPIO36 | Input only GPIO, cannot be configured as output
5 | SENSOR_VN | GPIO39 | Input only GPIO, cannot be configured as output
6 | IO34 | GPIO34 | Input only GPIO, cannot be

Tên đề tài: Thiết kế cánh tay Robot gắp sản phẩm sử dụng Adruino

29

| | | configured as output
7 | IO35 | GPIO35 | Input only GPIO, cannot be configured as output
8 | IO32 | GPIO32
9 | IO33 | GPIO33
10 | IO25 | GPIO25
11 | IO26 | GPIO26
12 | IO27 | GPIO27
13 | IO14 | GPIO14
14 | IO12 | GPIO12 | must be LOW during boot
16 | IO13 | GPIO13
17 | SHD/SD2 | GPIO9 | Connected to Flash memory
18 | SWP/SD3 | GPIO10 | Connected to Flash memory
19 | SCS/CMD | GPIO11 | Connected to Flash memory
20 | SCK/CLK | GPIO6 | Connected to Flash memory
21 | SDO/SD0 | GPIO7 | Connected to Flash memory
22 | SDI/SD1 | GPIO8 | Connected to Flash memory
23 | IO15 | GPIO15 | must be HIGH during boot, prevents startup log if pulled LOW
24 | IO2 | GPIO2 | must be LOW during boot and also connected to the on-board LED
25 | IO0 | GPIO0 | must be HIGH during boot and LOW for programming
26 | IO4 | GPIO4

Tên đề tài: Thiết kế cánh tay Robot gắp sản phẩm sử dụng Adruino

30

27 | IO16 | GPIO16
28 | IO17 | GPIO17
29 | IO5 | GPIO5 | must be HIGH during boot
30 | IO18 | GPIO18
31 | IO19 | GPIO19
33 | IO21 | GPIO21
34 | RXD0 | GPIO3 | Rx pin, used for flashing and debugging
35 | TXD0 | GPIO1 | Tx pin, used for flashing and debugging
36 | IO22 | GPIO22
37 | IO23 | GPIO23
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

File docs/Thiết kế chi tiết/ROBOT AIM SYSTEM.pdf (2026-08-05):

## ROBOT AIM SYSTEM

### 1. Phân tích linh kiện phần cứng (1 băng tải):

Tên linh kiện | Vai trò
ESP32 NodeMCU | Bộ não điều khiển trung tâm, xử lý toàn bộ logic và kết nối Wi-Fi để đưa dữ liệu (số lượng sản phẩm, trạng thái) lên nền tảng IoT.

Khung tay máy &
4 Động cơ Servo

Gồm 3 động cơ Servo MG996R (cho đế, vai, cùi chỏ - cần lực khỏe) và 1 Servo SG90 (cho tay kẹp - cần nhẹ). Thực hiện nhiệm vụ gắp và phân loại:

Động cơ Servo MG996R (3 cái): Đặc điểm: Sử dụng bánh răng kim loại, lực kéo rất khỏe (có thể lên tới 9-11 kg.cm).
Vị trí: Đặt ở phần Đế (Base - xoay trái/phải), Vai (Shoulder -nâng/hạ toàn bộ cánh tay), và Cùi chỏ (Elbow - vươn xa/rút gần). Những vị trí này phải chịu toàn bộ tải trọng của tay máy và vật thể nên bắt buộc phải dùng động cơ khỏe.
Động cơ Servo SG90 (1 cái):
Đặc điểm: Bánh răng nhựa, siêu nhỏ và nhẹ (lực kéo khoảng 1.5 kg.cm).
Vị trí: Đặt ở phần Tay kẹp (Gripper). Vì nó nằm ở ngọn của cánh tay robot, nếu dùng động cơ nặng như MG996R sẽ làm cánh tay bị mất trọng tâm, rụt cổ hoặc giật lắc. SG90 nhỏ nhẹ là sự lựa chọn hoàn hảo để kẹp các vật nhỏ.

1 Bộ băng tải mini
& Động cơ DC

Khung nhôm, rulo, dây đai và 1 động cơ giảm tốc DC (thường là 12V) để vận chuyển vật thể từ đầu này sang đầu kia.

Băng tải: Khung nhôm định hình giúp kết cấu vững chắc, dễ gắn thêm các gá đỡ cho cảm biến. Dây đai (thường là PVC hoặc cao su) được kéo bởi Rulo chủ động.
Link làm băng tải: https://www.youtube.com/watch?v=X4WG-6mejI0 (https://www.youtube.com/watch?v=X4WG-6mejI0)

Động cơ giảm tốc DC (12V): Bạn không thể dùng động cơ DC thường (như trong xe đồ chơi) vì tốc độ quá nhanh nhưng lực kéo lại yếu. Động cơ giảm tốc có một hộp số tích hợp, giúp tốc độ quay chậm lại (khoảng 30 - 60 vòng/phút) nhưng lực kéo tải

| (Torque) tăng lên rất nhiều, giúp vật thể đi trên băng tải từ từ, êm ái, tạo điều kiện cho cảm biến màu đọc chính xác.
Module L298N | Mạch công suất nhận tín hiệu PWM từ ESP32 để điều khiển tốc độ và bật/tắt động cơ DC của băng tải. Vi điều khiển ESP32 chỉ xuất ra tín hiệu điều khiển dòng điện rất nhỏ (vài chục mA). Nếu nối trực tiếp ESP32 vào động cơ DC 12V, ESP32 sẽ cháy ngay lập tức. L298N đóng vai trò là "rơ-le công suất". Hoạt động: cấp nguồn 12V (từ nguồn tổ ong) vào L298N. L298N lấy tín hiệu điều khiển (PWM) từ ESP32 để quyết định việc đóng/mở dòng điện 12V này cho động cơ DC, từ đó giúp băng tải chạy/dừng hoặc thay đổi tốc độ chạy nhanh/chậm.

Cảm biến màu
TCS3200

Lắp ở giữa băng tải. Khi vật đi ngang qua, nó sẽ quét và gửi thông số màu sắc (RGB) về ESP32.

Cấu tạo: Cảm biến này có các ma trận đi-ốt quang (Photodiode) với các bộ lọc màu Đỏ (Red), Xanh lá (Green), Xanh dương (Blue) và Trắng (Clear). Xung quanh nó thường có 4 đèn LED trắng để chiếu sáng bề mặt vật thể.
Cách hoạt động: Khi vật đi ngang qua, ánh sáng phản xạ từ vật sẽ đi vào cảm biến. Cảm biến sẽ xuất ra một dải xung vuông với tần số khác nhau. ESP32 sẽ đọc tần số này để nội suy ra vật đó là màu gì.
Lưu ý khi lắp ráp: Cảm biến này rất dễ bị nhiễu bởi ánh sáng môi trường (ánh sáng đèn tuýp, ánh sáng mặt trời). Bạn nên làm một cái "hộp chụp" nhỏ hoặc màng che xung quanh cảm biến để giữ ánh sáng ổn định.

Cảm biến hồng
ngoại (IR)

Cảm biến vật cản
hồng ngoại FC-51

Lắp ở cuối băng tải. Nhận diện vật đã đến vị trí cần gắp để báo ESP32 dừng băng tải.
Cấu tạo: Gồm 1 bóng phát tia hồng ngoại (màu trong suốt) và 1 bóng thu tia hồng ngoại (màu đen).
Hoạt động: Bóng phát liên tục chiếu tia IR ra phía trước. Khi không có vật, tia hồng ngoại đi thẳng. Khi có vật cản (sản phẩm đến cuối băng tải), tia hồng ngoại bị dội ngược lại vào bóng thu. Cảm biến sẽ báo một tín hiệu logic (LOW/HIGH) về chân ESP32. Vai trò: Giống như một "công tắc hành trình không tiếp xúc". Khi báo có vật, ESP32 lập tức ra lệnh cho L298N dừng băng tải, đảm bảo vật luôn dừng đúng vị trí (tọa độ cố định) để tay robot gắp trúng.

Hệ thống Nguồn
điện

Cần 1 nguồn tổ ong (ví dụ 12V-10A) kèm mạch giảm áp LM2596 (xuống 5V cho Servo). Bắt buộc cấp nguồn 5V riêng cho Servo, không lấy từ ESP32 để tránh cháy board.

Nguồn tổ ong (12V - 10A): Cấp tổng nguồn cho toàn hệ thống. Điện 12V này được nối trực tiếp vào Module L298N để kéo động cơ DC băng tải. một cái Adapter (biến áp) công suất lớn, có vỏ bằng kim loại đục lỗ lỗ như tổ ong để tản nhiệt. Bạn cắm điện 220V từ ổ cắm vào nó, nó sẽ xuất ra 12V.
Mạch giảm áp LM2596: Nhận điện 12V từ nguồn tổ ong và hạ áp (step-down) xuống mức 5V. Mạch LM2596 có khả năng chịu tải dòng cao (khoảng 3A).
Cấp nguồn cho Servo: Lấy điện 5V từ LM2596 để cấp cho 4 động cơ Servo. Khi MG996R gắp vật nặng, nó có thể "ngốn" tới 1.5A -2A một lúc.
Tuyệt đối ghi nhớ: Không bao giờ lấy nguồn 5V hay 3.3V từ board ESP32 để cắm cho Servo. Phải dùng nguồn 5V riêng từ LM2596. Việc duy nhất bạn cần nối chung là chân GND (Mass) của ESP32, LM2596, Servo và L298N lại với nhau để đồng bộ mức tín hiệu logic.

Sơ đồ đi dây điện:
1. Điện nhà 220V -> Nguồn tổ ong -> Xuất ra 12V.
2. Lấy 12V này cắm vào mạch L298N (loại to) để chạy động cơ băng tải.
3. Đồng thời, lấy 12V này cắm vào mạch LM2596.
4. Cực kỳ quan trọng: Trươc khi cắm mạch LM2596 vào linh kiện, cấp nguồn 12V cho nó, dùng tuốc nơ vít vặn con ốc nhỏ trên mạch và lấy đồng hồ VOM đo đầu ra bao giờ nó hạ xuống đúng 5V thì mới dừng.
5. Lấy 5V từ LM2596 cấp cho 4 động cơ Servo và cấp vào chân VIN (hoặc 5V) của ESP32. nối chung tất cả dây Âm (GND) lại với nhau.

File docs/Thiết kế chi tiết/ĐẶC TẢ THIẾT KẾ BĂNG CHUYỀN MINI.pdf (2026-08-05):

## ĐẶC TẢ THIẾT KẾ BĂNG CHUYỀN MINI

### 1. Kết cấu cơ khí

Khung: ( đề xuất sử dụng nhôm định hình)

- Sử dụng nhôm định hình ( ưu điểm là dễ tháo lắp, cứng vững, dễ thay đổi vị trí cảm biến, dễ dàng thêm các chi tiết,… Nhược điểm: có thể hơi mắc và chưa tìm đc giá thị trường)
- Liên kết các khớp nối bằng ke góc ( chi tiết khiến việc lắp ráp dễ dàng và tiện lợi khi tháo lắp,…. signature của nhôm định hình)

Con lăn ( 2 cái)

- Gồm 1 con lăn chủ động ( có gắn động cơ) và 1 con lăn bị động.
- Con lăn bị động sẽ lắp vòng bi ở hai đầu để giảm ma sát.
- Con lăn chủ động 1 đầu lắp vòng bi, 1 đầu lắp cố định với động cơ để điều khiển.

Dây bằng tải ( dây PVC)
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

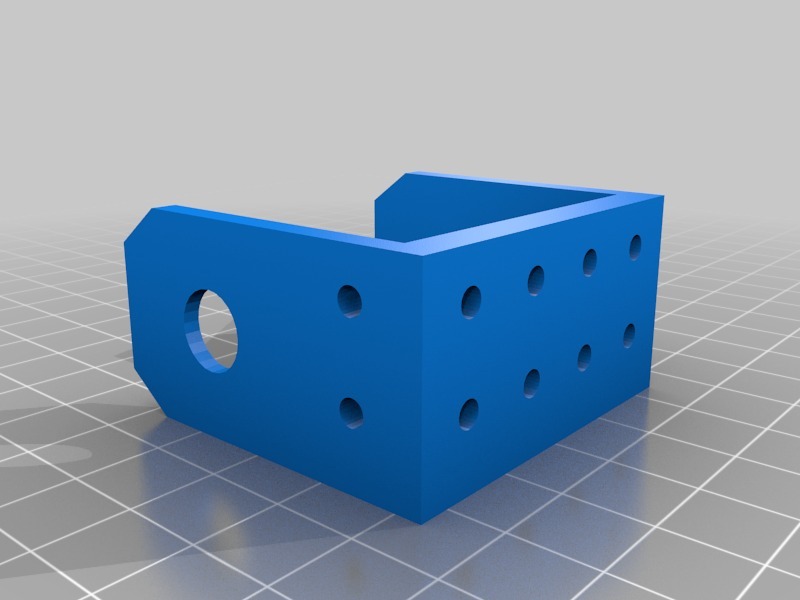
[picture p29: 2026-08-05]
hardware/Reference Aims/Versatile Servo Bracket System - 5784/images/Servo_BracketInsideShortV1.1.jpg

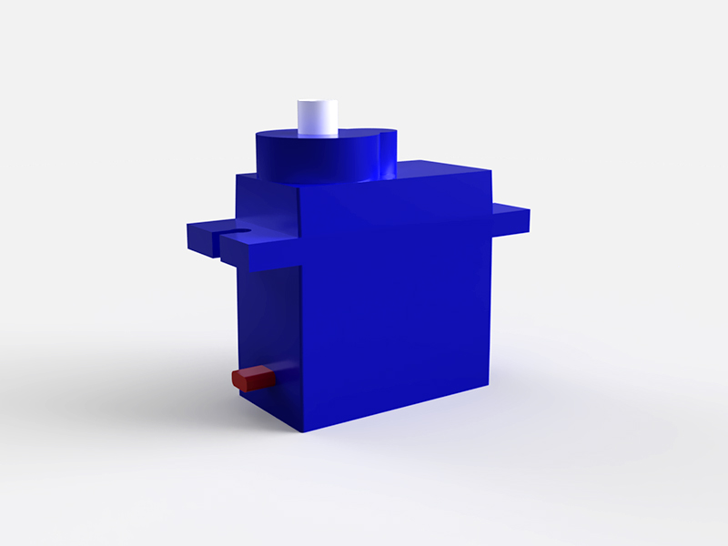
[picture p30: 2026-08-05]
hardware/Reference Aims/Micro Servo SG90 - Dummy - 2933842/images/Micro_Servo_SG90.jpg

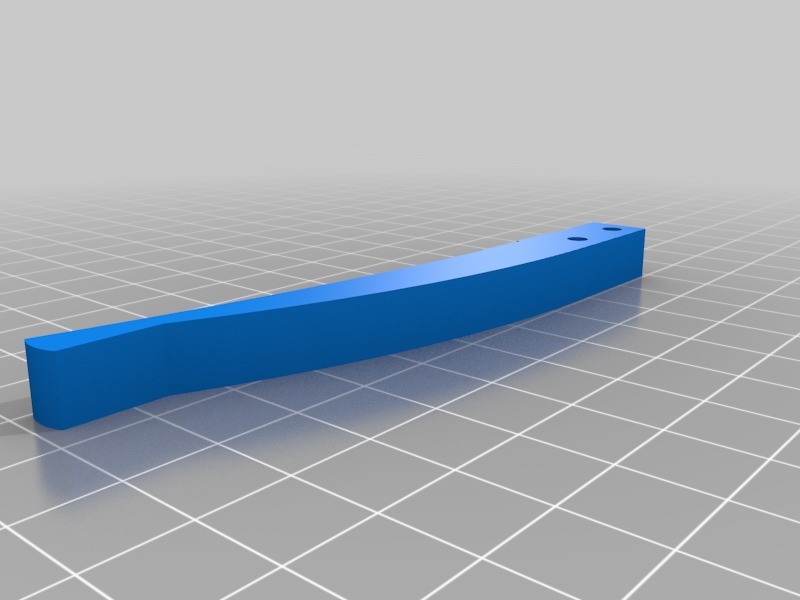
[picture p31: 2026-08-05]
hardware/Reference Aims/Versatile Servo Bracket System - 5784/images/Servo_Leg.jpg

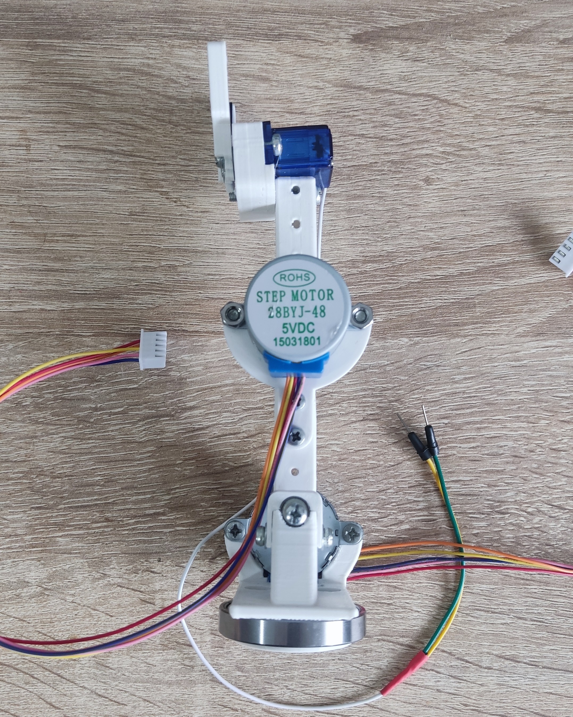
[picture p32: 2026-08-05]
hardware/Reference Aims/Robotic arm 3 DOF V1 - 6986935/images/View_2.jpg

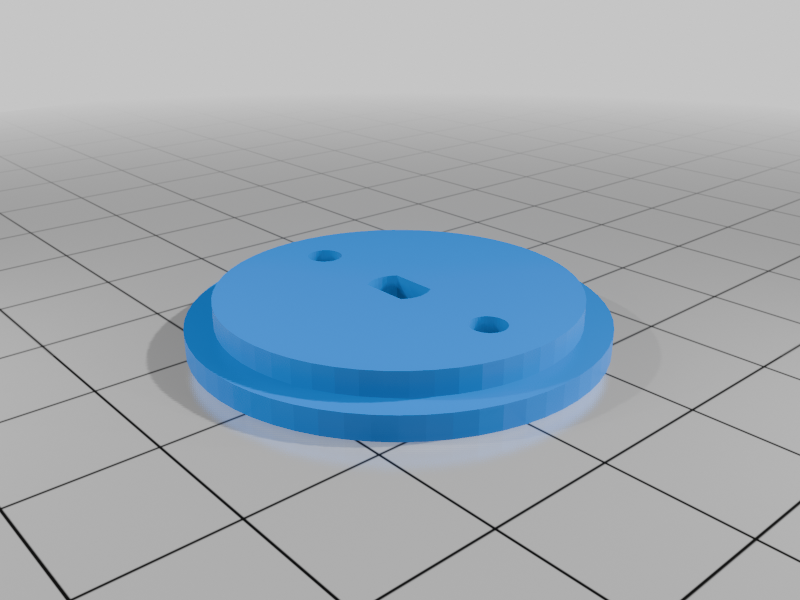
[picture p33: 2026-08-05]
hardware/Reference Aims/Robotic arm 3 DOF V1 - 6986935/images/Main_bearing_mount.png

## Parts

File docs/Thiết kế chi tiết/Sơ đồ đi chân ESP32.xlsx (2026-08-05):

Bảng chân
ESP32 | Linh kiện khác
D5 | IN3 (ĐK DC)
D18 | IN4 (ĐK DC)
D13 | Càm biến vật cản hồng ngoại FC 51
D32 | S0 (cảm biến màu sắc)
D14 | S1 ((cảm biến màu sắc)
D27 | S2 (cảm biến màu sắc)
D26 | S3 (cảm biến màu sắc)
D25 | OUT (cảm biến màu sắc)
D4 | SV1 (đế robot aims)
D19 | SV2 (vai robot aims)
D21 | SV3 (khuỷu robot aims)
D22 | SV4 (cổ tay năng hạ kẹp)
D23 | SV5 (kẹp robot aims)

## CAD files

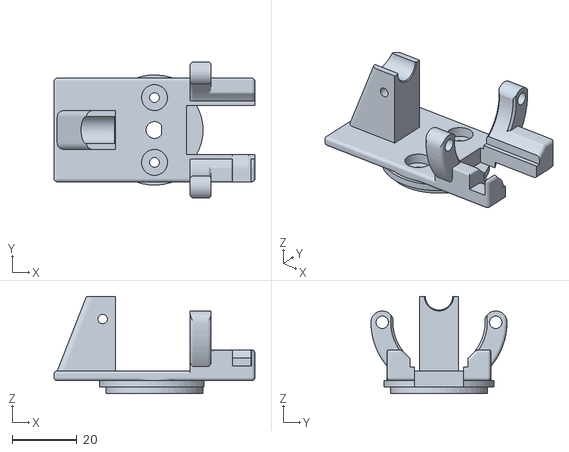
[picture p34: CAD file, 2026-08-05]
hardware/Reference Aims/Robotic arm 3 DOF V1 - 6986935/files/Main_28byj_mount.stl
62.0 x 42.0 x 30.0

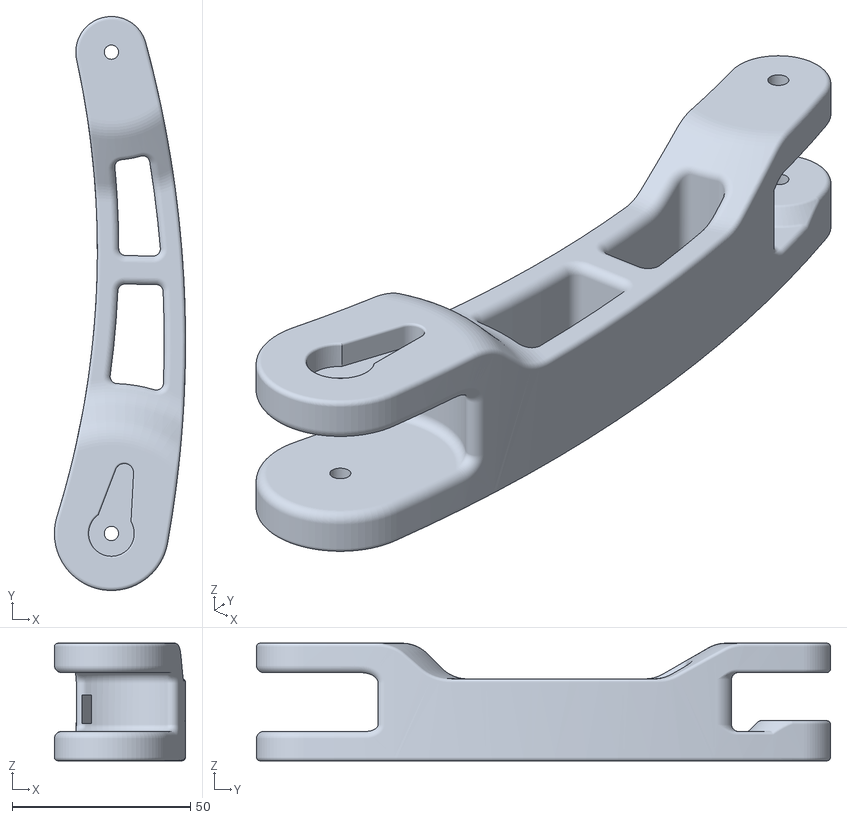
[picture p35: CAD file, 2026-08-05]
hardware/Reference Aims/EEZYbotARM MK2 - 1454048 - part 2 of 2/files/EBAmk2_002_mainarm.STL
36.8 x 161.0 x 33.0

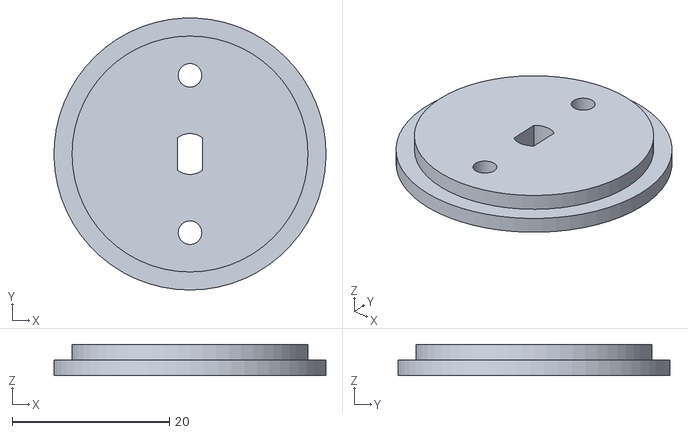
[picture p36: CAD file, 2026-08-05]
hardware/Reference Aims/Robotic arm 3 DOF V1 - 6986935/files/Main_bearing_mount.stl
34.6 x 34.6 x 4.00

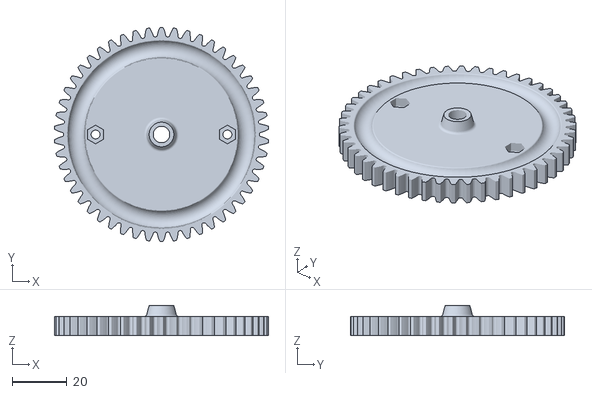
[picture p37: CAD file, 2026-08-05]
hardware/Reference Aims/EEZYbotARM MK2 - 1454048 - part 2 of 2/files/EBAmk2_011_gearmast_full.STL
77.9 x 78.0 x 11.0

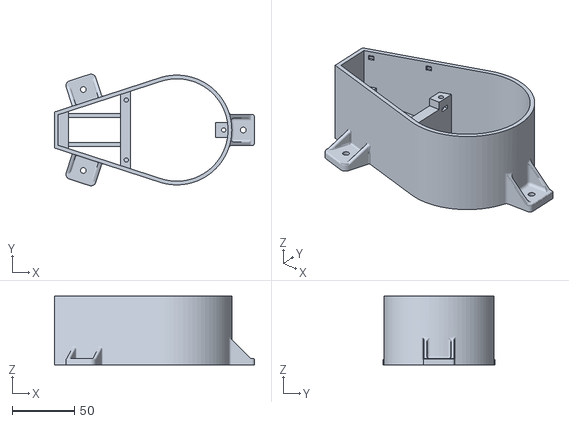
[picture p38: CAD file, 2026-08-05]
hardware/Reference Aims/EEZYbotARM MK2 - 1454048 - part 2 of 2/files/EBAmk2_012_mainbase.STL
160.2 x 89.5 x 55.0

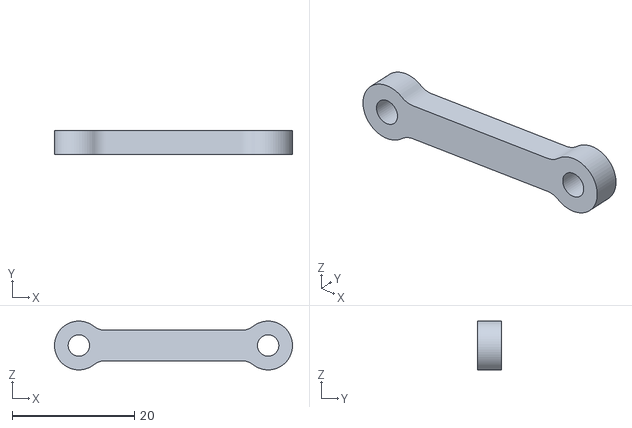
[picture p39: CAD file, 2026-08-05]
hardware/Main Aim to use/Main aim 3MG996R + 1SG90/Arduino based Robot Arm - 7322664/files/grip_link_1.STL
39.0 x 4.00 x 8.00

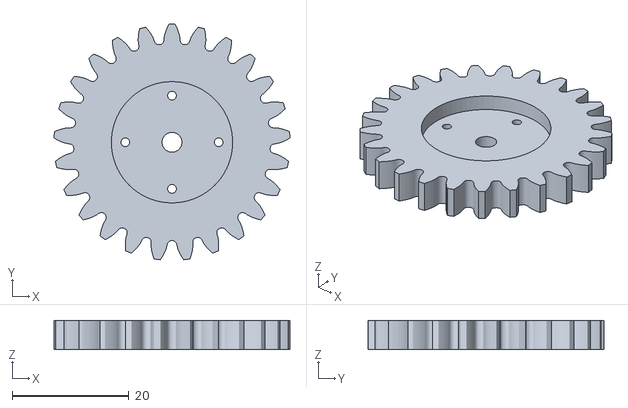
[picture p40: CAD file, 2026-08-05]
hardware/Reference Aims/EEZYbotARM MK2 - 1454048 - part 2 of 2/files/EBAmk2_010_gearservo.STL
40.5 x 40.4 x 5.00

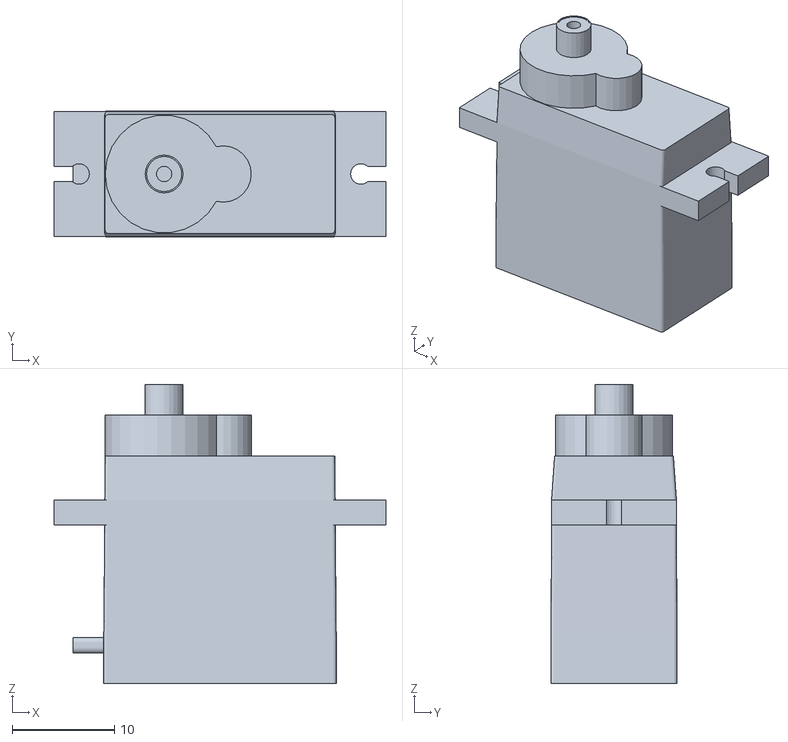
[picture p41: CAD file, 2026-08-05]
hardware/Reference Aims/Micro Servo SG90 - Dummy - 2933842/files/Micro_Servo_SG90.stl
32.4 x 12.3 x 29.2

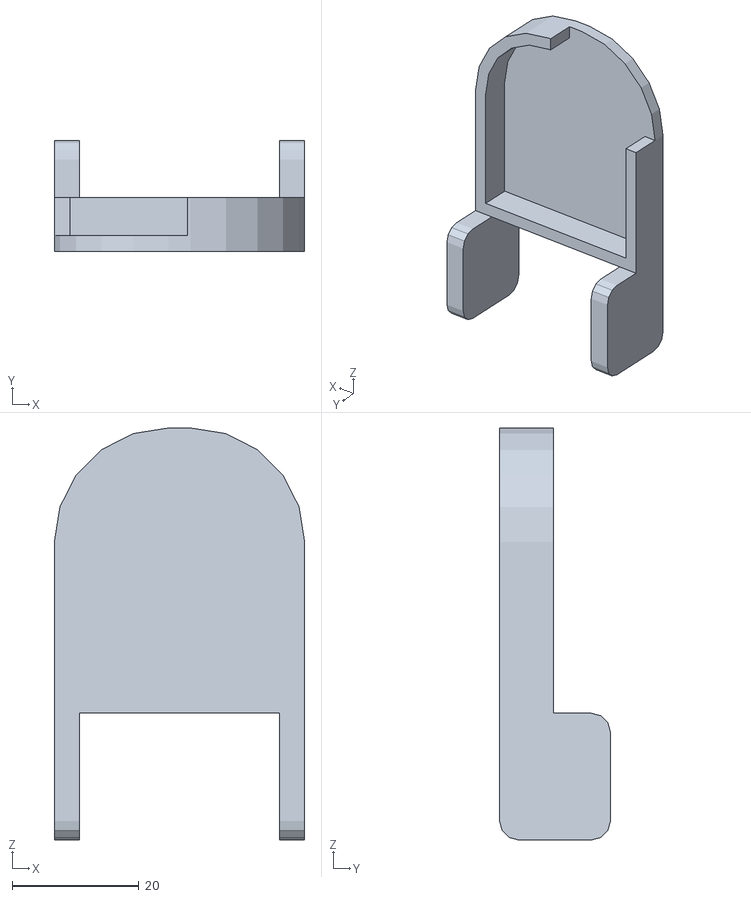
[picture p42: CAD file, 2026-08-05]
hardware/Reference Aims/Robotic Arm - 4 DOF - 3888877/files/prt0004.stl
39.5 x 17.5 x 65.0

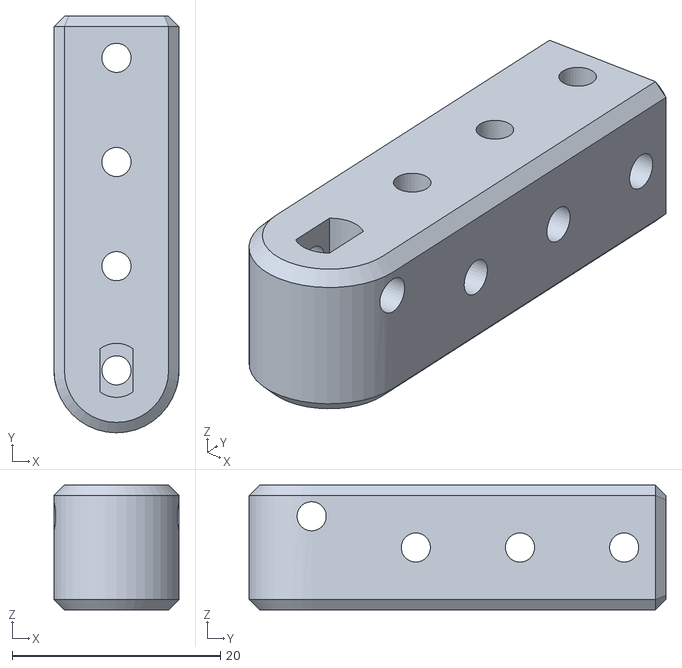
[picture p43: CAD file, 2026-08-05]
hardware/Reference Aims/Robotic arm 3 DOF V1 - 6986935/files/Beam_3.stl
12.0 x 40.0 x 12.0

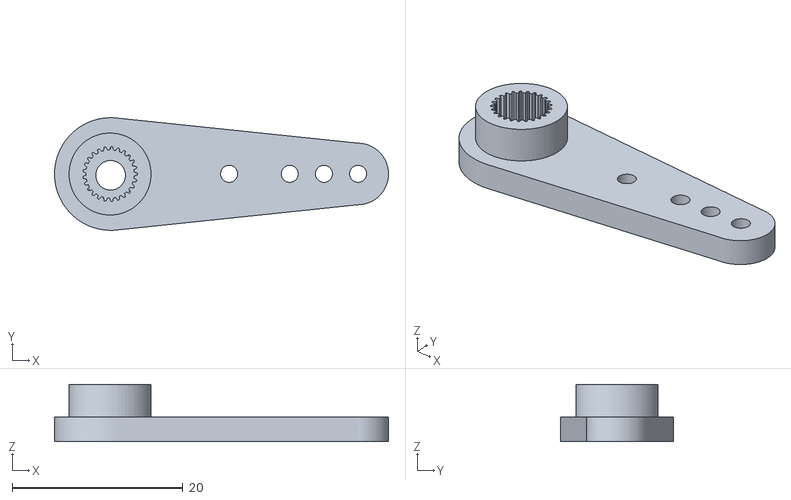
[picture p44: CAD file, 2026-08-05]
hardware/Reference Aims/Servo Arm_Horn for Tower Pro MG995_MG996R - 4719421/files/Servo_Arm.stl
39.1 x 13.2 x 6.68

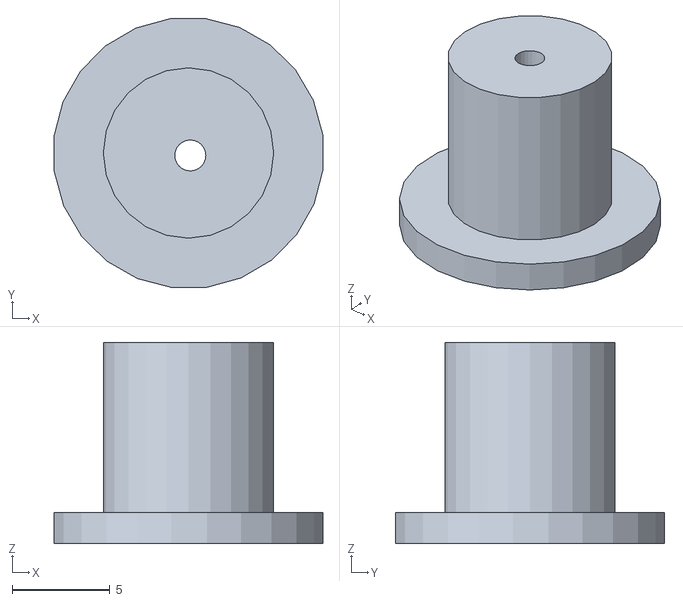
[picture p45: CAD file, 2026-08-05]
hardware/Reference Aims/Versatile Servo Bracket System - 5784/files/Servo_button.stl
13.8 x 13.8 x 10.3

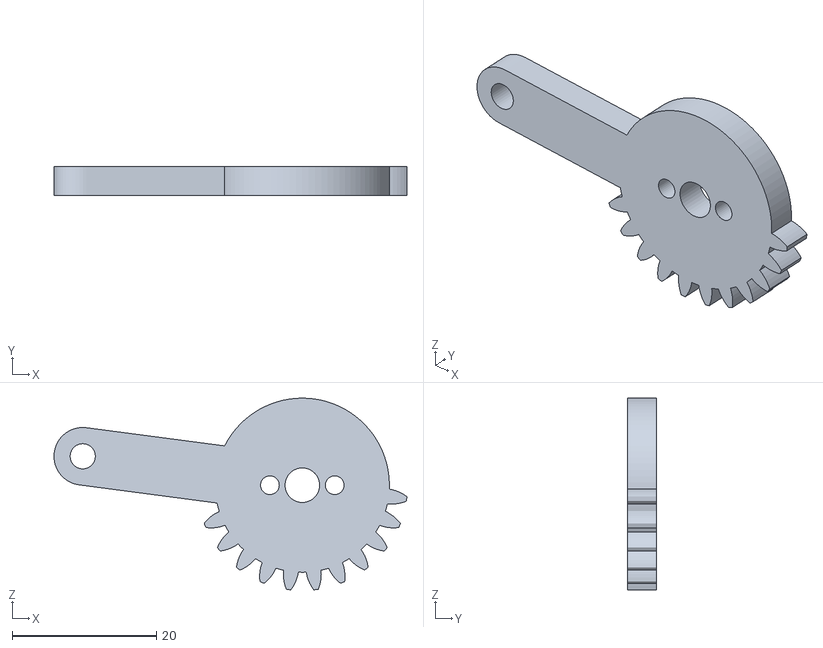
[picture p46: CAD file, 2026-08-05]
hardware/Main Aim to use/Main aim 3MG996R + 1SG90/Arduino based Robot Arm - 7322664/files/gear2.STL
49.0 x 4.00 x 26.6

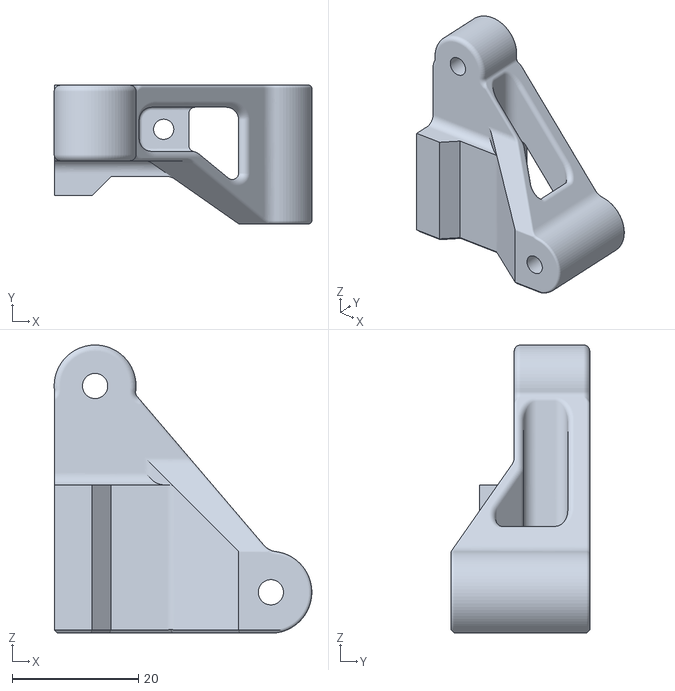
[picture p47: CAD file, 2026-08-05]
hardware/Reference Aims/EEZYbotARM MK2 - 1454048 - part 2 of 2/files/EBAmk2_009_trialinkfront.STL
40.9 x 22.0 x 45.7

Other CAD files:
hardware/Reference Aims/Robotic Arm - 4 DOF - 3888877/files/prt0003.stl
hardware/Reference Aims/Robotic arm 3 DOF V1 - 6986935/files/28byj_mount.stl
hardware/Reference Aims/Versatile Servo Bracket System - 5784/files/Servo_BracketInsideShortV1.1.stl
hardware/Main Aim to use/Main aim 3MG996R + 1SG90/Arduino based Robot Arm - 7322664/files/Arm_02_v3.STL
hardware/Main Aim to use/Main aim 3MG996R + 1SG90/Arduino based Robot Arm - 7322664/files/Arm_01.STL
hardware/Main Aim to use/Main aim 3MG996R + 1SG90/Arduino based Robot Arm - 7322664/files/Arm_03.STL
hardware/Main Aim to use/Main aim 3MG996R + 1SG90/Arduino based Robot Arm - 7322664/files/Base.STL
hardware/Main Aim to use/Main aim 3MG996R + 1SG90/Arduino based Robot Arm - 7322664/files/Gripper_1.STL
hardware/Main Aim to use/Main aim 3MG996R + 1SG90/Arduino based Robot Arm - 7322664/files/Gripper_base.STL
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

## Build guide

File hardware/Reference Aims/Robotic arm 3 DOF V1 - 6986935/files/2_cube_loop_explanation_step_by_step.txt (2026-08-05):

Prestep lower arm
Step 1. grab cube 1, rotate 180 degrees and raise arm
Step 2. lower arm
Step 3. release cube 1, move one tiny step (in order to properly trigger code)
Step 4. raise arm
Step 5. rotate 90 degrees
Step 6. lower arm
Step 7. grab cube 2, move one tiny step
Step 8. rotate 90 degrees, raise arm
Step 9. lower arm
Step 10. release cube 2, move one tiny step
Step 11. rotate 180 degrees, raise arm
Step 12. lower arm
Step 13. grab cube 1, rotate 90 degrees raise arm
Step 14. lower arm
Step 15. release cube 1, raise part of the arm
Step 16. rotate 90 degrees, reposition arm
Step 17. lower arm, Step 1. triggers

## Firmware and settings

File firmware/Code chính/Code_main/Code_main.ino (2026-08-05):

#include "MotorDC.h"
#include "CambienFC51.h"
#include "CambienmauTCS3200.h"
#include "DieukhienServo.h"

///////// Wifi ////////////
#include <WiFi.h>        //  
#include <HTTPClient.h>  //
///////////////////////////

unsigned long thoiGianPingCuoi = 0;
String pingURL = "http://192.168.100.100:8080/api/ping"; // Đảm bảo IP trùng với IP máy tính bạn  

// ==============================================================================
// 1.Nhập tên và mật khẩu Wi-Fi nhà
// (Lưu ý: Máy tính chạy code Python và ESP32 phải bắt CHUNG 1 mạng Wi-Fi này)
// ==============================================================================
const char* ssid = "Wifi";
const char* password = "MKWifi";

// ==============================================================
// 2.Thay chữ 192.168.x.x thành IP máy tính
// (Tuyệt đối giữ nguyên phần ":8080/api/sensor" ở đuôi)
// ==============================================================
String serverName = "http://192.168.x.x:8080/api/sensor";

// =========================================================
// HÀM GỬI DỮ LIỆU LÊN WEB (Có Tự Động Kết Nối Lại Wi-Fi)
// =========================================================
void sendDataToWeb(String tenMau, String maMau, int r, int g, int b) {
  // 1. KIỂM TRA MẠNG TRƯỚC KHI GỬI
  if (WiFi.status() != WL_CONNECTED) {
    Serial.println("CẢNH BÁO: Rớt mạng do Servo kéo dòng! Đang kết nối lại...");
    WiFi.disconnect();
    WiFi.reconnect();
    
    // Đợi tối đa 5 giây để Wi-Fi kết nối lại
    int timeout = 0;
    while (WiFi.status() != WL_CONNECTED && timeout < 10) {
      delay(500);
      Serial.print(".");
      timeout++;
    }
    Serial.println();
  }

  // 2. NẾU MẠNG ĐÃ ỔN ĐỊNH THÌ BẮN DỮ LIỆU
  if (WiFi.status() == WL_CONNECTED) {
    HTTPClient http;
    http.begin(serverName); 
    http.addHeader("Content-Type", "application/json"); 
    
    String jsonPayload = "{\"color_name\":\"" + tenMau + "\", \"color_key\":\"" + maMau + "\", \"r\":" + String(r) + ", \"g\":" + String(g) + ", \"b\":" + String(b) + "}";
    int httpResponseCode = http.POST(jsonPayload);
    
    if (httpResponseCode > 0) {
      Serial.print("-> ĐÃ GỬI WEB MÀU: ");
      Serial.print(tenMau);
      Serial.print(" (Mã: ");
      Serial.print(httpResponseCode);
      Serial.println(")");
    } else {
      Serial.print("-> LỖI GỬI WEB! Mã lỗi: ");
      Serial.println(httpResponseCode);
    }
    http.end();
  } else {
    Serial.println("-> BÓ TAY: KHÔNG CÓ WI-FI ĐỂ GỬI! Vui lòng kiểm tra lại nguồn điện.");
  }
}

void setup() {  
  Serial.begin(115200);
  delay(1000);

  ///////////////////// Wifi ///////////////////////
  // Bắt đầu kết nối Wi-Fi
  Serial.println();
  Serial.print("Dang ket noi den Wi-Fi: ");
  Serial.println(ssid);
  
  // ÉP ESP32 VÀO CHẾ ĐỘ THU SÓNG (STATION)
  WiFi.mode(WIFI_STA);
  // Ngắt các kết nối cũ bị kẹt (nếu có) trước khi kết nối mới
  WiFi.disconnect(); 
  delay(100);

  WiFi.begin(ssid, password);
  WiFi.setAutoReconnect(true); // Bật chế độ tự động kết nối lại của ESP32
  
  // Chờ cho đến khi kết nối thành công
  while (WiFi.status() != WL_CONNECTED) {
    delay(500);
    Serial.print(".");
  }
  
  Serial.println("");
  Serial.println("-> Ket noi Wi-Fi THANH CONG!");
  Serial.print("IP cua ESP32: ");
  Serial.println(WiFi.localIP());
  ///////////////////////////////////////////////////

  ///////////////// Moto_DC ////////////////////
  setupMotorDC();
  Serial.println("Set up DC successfully!!");
  //////////////////////////////////////////////

  /////////////// CambienFC51 ///////////////////
  setupFC51();
  Serial.println("Set up FC51 successfully!!");
  ///////////////////////////////////////////////

  ////////////// CambienmauTCS3200 ////////////////
  setupTCS3200();
  Serial.println("Set up FCS3200 successfully!!");
  //////////////////////////////////////////////////

  //////////////////// Servo ///////////////////////
  setupServo();
  Serial.println("Set up Servo successfully!!");
  //////////////////////////////////////////////////

}

void loop() {
  openFC51();
  delay(200);

// --- TÍNH NĂNG NHÁ MÁY (Ping) MỖI 3 GIÂY ---
  if (millis() - thoiGianPingCuoi > 3000) {
    if (WiFi.status() == WL_CONNECTED) {
      HTTPClient http;
      http.begin(pingURL);
      
      int httpResponseCode = http.GET(); // Gửi Ping và nhận mã kết quả
      
      Serial.print("-> Đang Ping tới Web... Mã kết quả: ");
      Serial.println(httpResponseCode);
      
      http.end();
    } else {
      // NẾU RỚT MẠNG -> ÉP NÓ KẾT NỐI LẠI NGAY LẬP TỨC
      Serial.println("-> LỖI: Rớt mạng Wi-Fi! Đang tự động kết nối lại...");
      WiFi.disconnect();
      WiFi.reconnect(); 
    }
    thoiGianPingCuoi = millis();
  }

}

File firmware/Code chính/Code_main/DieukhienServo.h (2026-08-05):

#pragma once
#include <ESP32Servo.h>
#include "CambienmauTCS3200.h"

/////// Khởi tạo 4 servo ////////
Servo s1;
Servo s2;
Servo s3;
Servo s4;
Servo s5;
/////////////////////////////////

const int Pin_s1 = 4;
const int Pin_s2 = 19;
const int Pin_s3 = 21;
const int Pin_s4 = 22;
const int Pin_s5 = 23;

const int Home_s1 = 85; // Đế
const int Home_s2 = 165; // Vai
const int Home_s3 = 120; // Khuỷu
const int Home_s4 = 120; // Cổ tay nâng hạ
const int Home_s5 = 110; // kẹp

void setupServo(){
  Serial.begin(115200);

  ////////////////////////////////////////////////////////////
  // Khởi tạo cấu hình Timer + chia tần số xung cho ESP32   //
  // Lý do: Adruino Uno tự chia xung -> ESP32 có 4 luồng    //
  //        chia xung độc lập để tạo xung PWM -> Nếu cho    //
  //        4 servo dùng chung 1 timer -> xảy ra hiện tượng //
  //        bị nhiễu xung -> 1 servo chạy dẫn đến các servo //
  //        khác cũng bị giật theo                          //
  ////////////////////////////////////////////////////////////
  ESP32PWM::allocateTimer(0);
  ESP32PWM::allocateTimer(1);
  ESP32PWM::allocateTimer(2);
  ESP32PWM::allocateTimer(3);

  /////////////////////////////////////////////////////////////
  // Ép các servo sử dụng xung 50Hz theo tiêu chuẩn          //
  // Lý do: Chống cháy linh kiện -> Vì có thể tự phát ở xung //
  //        cao hơn 100 or 200Hz                             //
  /////////////////////////////////////////////////////////////
  s1.setPeriodHertz(50);
  s2.setPeriodHertz(50);
  s3.setPeriodHertz(50);
  s4.setPeriodHertz(50);
  s5.setPeriodHertz(50);

  //////////////////////////////////////////////////////////////
  // Lệnh attach(chân) -> bắt buộc, 500 là độ rộng xung tương //
  // với góc 0 độ và 2400 là độ rộng xung tương ứng với góc   //
  // 180 độ                                                   //
  // Lý do: ép servo quay full các góc trong 180 độ -> nếu    //
  //        chỉ để attach bình thường -> có thể quay tối đa   //
  //        chỉ khoảng 100-120 độ                             //
  //////////////////////////////////////////////////////////////
  s1.attach(Pin_s1, 500, 2400);
  s2.attach(Pin_s2, 500, 2400);
  s3.attach(Pin_s3, 500, 2400);
  s4.attach(Pin_s4, 500, 2400);
  s5.attach(Pin_s5, 500, 2400);

  ///////////////////////////////////////////////////////////////
  // Đưa các servo về vị trí ban đầu -> Sử dụng delay 2000 để  //
  // ESP32 đứng im 2s -> để cánh tay quay về vị trí cũ rồi mới //
  // tiếp tục quay                                             //
  ///////////////////////////////////////////////////////////////
  s1.write(Home_s1);
  s2.write(Home_s2);
  s3.write(Home_s3);
  s4.write(Home_s4);
  s5.write(Home_s5);
  delay(2000);
}

////////////////////////////////////////////////////////////////////////
// Hàm giảm giật, rung cho cánh tay khi quay -> Thay vì bắt cánh tay  //
// xoay liền góc đó -> tiến hành băm nhỏ quãng đường thành từng độ    //
// nhỏ để xoay                                                        //
// Lý do: delay time càng lớn -> cành tay xoay càng chậm và ngược lại //                                                        
////////////////////////////////////////////////////////////////////////

/*void reduces1(Servo& myservo, int startAngle, int targetAngle, int delaytime) { // s1: kẹp
  int start_us = map(startAngle, 0, 180, 500, 2400);
  int target_us = map(targetAngle, 0, 180, 500, 2400);
  int micro_delay = delaytime / 5; 
  if (micro_delay < 1) micro_delay = 1; 
  if (start_us < target_us) {
    for (int i = start_us; i <= target_us; i += 23) { 
      myservo.writeMicroseconds(i);
      delay(micro_delay);
    }
  } 
  else if (start_us > target_us) {
    for (int i = start_us; i >= target_us; i -= 23) {
      myservo.writeMicroseconds(i);
      delay(micro_delay);
    }
  }
  myservo.write(targetAngle); 
}

void reduces2(Servo& myservo, int startAngle, int targetAngle, int delaytime) { // reduce for s2
  int start_us = map(startAngle, 0, 180, 500, 2400);
  int target_us = map(targetAngle, 0, 180, 500, 2400);
  int micro_delay = delaytime / 5; 
  if (micro_delay < 1) micro_delay = 1; 
  if (start_us < target_us) {
    for (int i = start_us; i <= target_us; i += 23) { 
      myservo.writeMicroseconds(i);
      delay(micro_delay);
    }
  } 
  else if (start_us > target_us) {
    for (int i = start_us; i >= target_us; i -= 23) {
      myservo.writeMicroseconds(i);
      delay(micro_delay);
    }
  }
  myservo.write(targetAngle); 
}

void reduces3(Servo& myservo, int startAngle, int targetAngle, int delaytime) { // reduce for s3
  int start_us = map(startAngle, 0, 180, 500, 2400);
  int target_us = map(targetAngle, 0, 180, 500, 2400);
  int micro_delay = delaytime / 5; 
  if (micro_delay < 1) micro_delay = 1; 
  if (start_us < target_us) {
    for (int i = start_us; i <= target_us; i += 20) { 
      myservo.writeMicroseconds(i);
      delay(micro_delay);
    }
  } 
  else if (start_us > target_us) {
    for (int i = start_us; i >= target_us; i -= 20) {
      myservo.writeMicroseconds(i);
      delay(micro_delay);
    }
  }
  myservo.write(targetAngle); 
}

void reduces4(Servo& myservo, int startAngle, int targetAngle, int delaytime) { // reduce for s4
  int start_us = map(startAngle, 0, 180, 500, 2400);
  int target_us = map(targetAngle, 0, 180, 500, 2400);
  int micro_delay = delaytime / 5; 
  if (micro_delay < 1) micro_delay = 1; 
  if (start_us < target_us) {
    for (int i = start_us; i <= target_us; i += 20) { 
      myservo.writeMicroseconds(i);
      delay(micro_delay);
    }
  } 
  else if (start_us > target_us) {
    for (int i = start_us; i >= target_us; i -= 20) {
      myservo.writeMicroseconds(i);
      delay(micro_delay);
    }
  }
  myservo.write(targetAngle);   
}*/

/*void reduces5(Servo& myservo, int startAngle, int targetAngle, int delaytime) { // reduce for s5
  int start_us = map(startAngle, 0, 180, 500, 2400);
  int target_us = map(targetAngle, 0, 180, 500, 2400);
  int micro_delay = delaytime / 5; 
  if (micro_delay < 1) micro_delay = 1; 
  if (start_us < target_us) {
    for (int i = start_us; i <= target_us; i += 20) { 
      myservo.writeMicroseconds(i);
      delay(micro_delay);
    }
  } 
  else if (start_us > target_us) {
    for (int i = start_us; i >= target_us; i -= 20) {
      myservo.writeMicroseconds(i);
      delay(micro_delay);
    }
  }
  myservo.write(targetAngle); 
}*/

////////////////////////////////////////////////////////////////////////
// HÀM QUAY SERVO 
////////////////////////////////////////////////////////////////////////
void instantMove(Servo& myservo, int targetAngle, int delaytime) {
  // Bẻ lái cái rụp tới đích luôn!
  myservo.write(targetAngle); 
  
  // LƯU Ý: Vẫn phải có một nhịp nghỉ nhỏ để nhông cốt bên trong Servo kịp xoay tới nơi.
  // Vì các con số delaytime (2, 5, 10) là quá bé so với tốc độ thực tế của Servo,
  // nên nhân thêm hệ số 30 để cánh tay không bị vấp lệnh tiếp theo.
  delay(delaytime * 30); 
}
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

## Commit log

2026-08-05 First commit - Hoan thanh du an Robot Aim
    [28byj_mount.stl, Arm_01.STL, Arm_02_v3.STL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]
2026-08-05 Fix schematics image links
